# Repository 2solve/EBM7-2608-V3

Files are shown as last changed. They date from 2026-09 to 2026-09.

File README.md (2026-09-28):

# IC2S EBM7-2608 V2.3 — variante fixa 4-20 mA

Placa de extensão da família IC2S (Extension Board Model 7) com **quatro entradas 4-20 mA**, **uma entrada de célula de
carga** e **um NTC de junta fria**, medidos por um ADC sigma-delta de 24 bits (**AD7124-8**). Encaixa por baixo na base board:
**P1** é o barramento (alimentação 24 V e 5 V, SPI do processador) e **P2** leva os sinais de campo.

Esta é a variante **fixa**: as quatro entradas são só 4-20 mA. A variante com selecção 0-10 V / 4-20 mA por MOSFET vive noutro
projecto (`EBM7-2608-V23_configuravel`).

Projecto KiCad 10 (testado em 10.0.5). Abrir
`Desenvolvimento_IC2S-EBM7-2608-V2.3-Fixo420/Projeto_IC2S-EBM7-2608-V2.3-Fixo420/IC2S-EBM7-2608-V2.3-Fixo420.kicad_pro`.

Identificador desta versão: **`IC2S-EBM7-2608-V2.3-Fixo420`** (produto IC2S-EBM7-2608, versão 2.3, variante fixa 4-20 mA).

---

## Estado (28-09-2026)

| Verificação | Resultado |
|---|---|
| DRC (`kicad-cli pcb drc --severity-all --schematic-parity`) | **0 erros**, 62 avisos (todos de serigrafia) |
| Ligações por fazer | 0 |
| Paridade esquemático ↔ PCB | 0 |
| ERC | 0 erros |

Não está pronta para fabricar: ver [Pendentes](#pendentes).

---

## Estrutura do repositório

Segue o padrão de pastas dos produtos da 2Solve (o mesmo de `Produtos/Axcel_Sensor`): uma pasta por versão, e dentro dela
projecto, documentos e ficheiros de fabricação, sempre com o identificador no nome.

```
Desenvolvimento_IC2S-EBM7-2608-V2.3-Fixo420/
├── Projeto_IC2S-EBM7-2608-V2.3-Fixo420/
│   ├── IC2S-EBM7-2608-V2.3-Fixo420.kicad_pro / .kicad_sch / .kicad_pcb / .kicad_dru
│   ├── 01_conectores … 08_ntc.kicad_sch          (as oito folhas)
│   ├── footprints/EBM7_V23.pretty, symbols/       (bibliotecas locais, por ${KIPRJMOD})
│   ├── Documentos_de_Referência-IC2S-EBM7-2608-V2.3-Fixo420/   (datasheets das peças desta placa)
│   └── Outputs/drc_report.json
├── Documentos_IC2S-EBM7-2608-V2.3-Fixo420/
│   ├── 00-Especificações_Técnicas_…/   verificações, relatórios, perguntas ao firmware
│   ├── 01-Esquemáticos_…/              Schematic-….pdf, ….step, …-Top_View.pdf, …-Bottom_View.pdf
│   ├── 02-Pinout_…/                    (vazio)
│   └── 03-Diagrama_Blocos_…/           (vazio)
└── Arquivos_Fabricação_IC2S-EBM7-2608-V2.3-Fixo420/
    ├── 00-Gerbers_…/                   ….GTL .G1 .G2 .GBL .GTS .GBS .GTO .GBO .Outline, ….TXT (furação), .gbrjob, .zip
    ├── 01-BOM_List_…/                  …-Preliminar.xlsx
    ├── 02-Pick-and-Place_…/            …-Pick-and-Place-Preliminar.csv
    └── 03-Stencil_…/                   ….GTP (pasta topo), ….GBP (pasta base)
```

Os ficheiros de fabricação e as vistas foram **gerados pelo `kicad-cli` a partir do projecto** a 28-09-2026 e são
**preliminares**: a placa ainda não passou a revisão independente do roteamento. Não enviar a fabricar sem essa revisão.

Os documentos em `00-Especificações_Técnicas` são registos da data em que foram escritos e citam os nomes antigos dos
ficheiros (`IC2S_Extension_Board_Model_7-EBM7-2608_V23L_Load_Cell_4AI.*`), anteriores à arrumação de 25-09-2026.

**Onde está cada decisão:** cada folha do esquemático tem um bloco de texto «DECISOES DESTA FOLHA» com notas numeradas. Neste
README cita-se sempre como *folha N, nota M*. A nota é a fonte; este documento resume.

---

## Como funciona, bloco a bloco

### Folha 1 — Conectores

- **P1** (Harwin M20-7822046, fila única de 20) liga à base board. Traz +24 V (P1.20), a massa GND_ADC (P1.19), +5 V, DGND e
  o SPI. Os pinos que esta placa não usa (USB, CS_DAC, I²C…) terminam aqui por desenho da família (nota 1).
- P1.20 leva ~116 mA em regime e ~180 mA em falha, 6 % do que o contacto aguenta (nota 2).
- **P2** (M20-7821446) é o conector de campo: excitação e sinais da célula, e os quatro laços (nota 5). Pinos 6-13 em pares
  `+24V_AINn` / `AINn`.

### Folha 2 — Entrada de 24 V e protecção

Caminho: P1.20 → TVS **D1** → fusível **F1** → díodo **D2** → **+24V_ADC**, que alimenta tudo: o conversor U1 e os laços.

- **F1 = Eaton CC12H750MA (time-lag)**: o I²t de fusão (150 mA²s) fica ~29× acima do arranque dos ~30 µF a jusante. O fusível anterior (FF,
  1,5 mA²s) abria no próprio arranque dos condensadores — um dos mecanismos da avaria em campo da V2.2 (notas 1, 2 e 10).
- **D1 = SMA6J33A-Q** (TVS de entrada): standoff 33 V, **clamp real 53,3 V** a 11,3 A — não os 40,6 V que dizia a biblioteca
  (nota 3).
- **C1 = 10 µF / 100 V em 1210**, condensador de entrada do U1: o datasheet da Recom (R-78HB-0.5, p.4) pede 3,3 µF / 100 V
  quando Vin pode passar de 50 V, e o clamp do TVS é 53,3 V (notas 4, 12 e 13).
- **Ramo único de 24 V** (28-09-2026, nota 13): F2, D3 e C2 saíram; o +24V_REG passou a ser o próprio +24V_ADC. Com
  116 mA em regime e ~180 mA em falha, F1 (750 mA) e D2 (1 A) chegam. Perde-se a selectividade: um curto no +24V_ADC
  abre F1 e desliga a placa inteira.
- **Condensadores** (nota 14): 100 nF de 50 V (TDK C1608X7R1H104K080AA) em todo o lado menos no C36, que está no
  +24V_ADC e fica a 100 V; 1 µF com um só MPN (TDK C1608X7R1H105K080AB).
- **Massas:** desde 24-09-2026 **GND_24V e GND_ADC são a mesma rede**. O net-tie que as unia (R1/R200) saiu (nota 7). Motivo:
  as duas são o mesmo domínio a montante; quem isola a lógica do processador é a MainBoard (conversor SCW12B-05), não esta placa.

### Folha 3 — Alimentação

Cadeia analógica: +24V_ADC → **U1** (Recom R-78HB5.0-0.5L, conversor 24→5 V) → FB1 → **+5V_ADC** → **U3** (SPX3819) → **+3.3V_ANA**.
A alimentação do lado do PLC (U2) está desenhada na folha 4, junto ao isolador que alimenta.

- O GND do U1 é GND_ADC: o +5V_ADC é a referência ratiométrica da célula (nota 2).
- O U1 não aceita ligação a quente (hot-plug) — aviso para o manual (nota 3).
- **Pré-carga do U1** (nota 13 e adenda de 15-09): o R-78HB só tem exactidão e regulação especificadas acima de ~10 % de carga;
  a placa sozinha fica em 1,6-6,8 %. Há posições para duas resistências de 220 R (0 / 22,7 / 45,5 mA); **a decisão faz-se na
  bancada**.
- **U4 = TL431B** grampeia o +3.3V_ANA a ~3,6 V (divisor 4k42 / 10k). É o sítio para onde os díodos de protecção das entradas
  despejam a corrente de um surto; sem ele o SPX3819, que só fornece corrente, deixava o rail subir até ~10 V e levava o ADC
  e a referência. Corrente real estimada 12-23 mA, contra 100 mA recomendados (nota 14, em que o componente aparece como U14).

### Folha 4 — Barreira digital

- **Alimentação do lado PLC:** +5 V do P1 → **U2** (SPX3819, o mesmo MPN do U3, desde 28-09; era MCP1824) → **+3.3V** (massa DGND), com C6/C8/C9 e os pontos de teste
  T3 (DGND) e T5 (+3.3V). Alimenta o lado 1 do isolador. Passou da folha 3 para esta em 25-09-2026, só no desenho
  (as ligações não mudaram); as notas que falam dela continuam na folha 3.
- **U5 = ISO7141** passa o SPI entre o lado do PLC (DGND) e o lado analógico (GND_ADC): 3 canais de ida (MOSI, CLK, CS) e 1 de
  volta (MISO), sempre habilitado (notas 3 e 4).
- **Não é isolamento de segurança nesta placa** (nota 1): os 2500 Vrms do ISO7141 exigiriam 3,7 mm de distância cobre-a-cobre e
  o PCB tem ~1 mm. Faz **separação de ruído** entre a lógica e a medida. Para um dia declarar isolamento: ≥ 3,7 mm ao longo da
  barreira (nota 5).
- **No PCB a barreira é física:** DGND e GND_ADC são zonas separadas nas camadas internas e em baixo. O `.kicad_dru` exige
  **1,0 mm** entre as redes do lado PLC (classe `DIGSIDE`) e o resto; há rule areas sem cobre debaixo do ISO7141
  (`keepout_barreira_ISO7141`) e junto ao P1 (`keepout_barreira_P1`, reposto a 25-09).
- Firmware: no arranque, reset do porto série do ADC (64 SCLK com DIN = 1), porque o CS pode oscilar na rampa de alimentação.

### Folha 5 — ADC

- **U6 = AD7124-8**, alimentado por +3.3V_ANA (AVDD, por um filtro passante NFM) e +3.3V_IOVDD (nota 4).
- **Referência dos laços: U7 = ADR4525 (2,5 V) no REFIN2**, por um único 0 Ω. Na V2.2 três 0 Ω punham 5 V nesse pino, acima do
  máximo absoluto de 3,6 V, em todas as placas (nota 1).
- **Célula ratiométrica no REFIN1** = metade da tensão de excitação (nota 2; folha 7, nota 10).
- SYNC com pull-up de 10k (o ADC não tem pull-up interno e com SYNC em baixo fica em reset) (nota 5).
- **Mapa de canais nesta placa:** AIN1 ← AIN4_ADC, AIN2 ← AIN3_ADC, AIN3 ← AIN2_ADC, AIN4 ← AIN1_ADC, AIN5/AIN6 = célula +/−,
  AIN8/AIN9 = NTC. O cruzamento dos laços é herdado da V2.2 e foi mantido para não trocar canais no firmware (folha 6, nota 4).
- Firmware (notas 8 e 9): REF_EN = 1; buffers de entrada ligados; REF_BUFP = REF_BUFM = 0 nos setups com REFIN2.
  As perguntas abertas ao firmware estão em `perguntas_firmware_EBM7_V23L_2026-09-24.md`.

### Folha 6 — Laços 4-20 mA (×4)

Cada canal tem **dois caminhos** no P2, em pares de pinos:

- **Alimentação do sensor** (pino par, `+24V_AINn`): +24V_ADC → fusível **F3-F6** → borne, com o TVS **SMBJ36A** junto ao
  conector.
- **Sinal** (pino ímpar, `AINn`): borne → TVS **824500301** → protector **TPS26613** (U8-U11) → **burden 110 Ω 0,1 %** →
  ferrite → RC anti-aliasing → clamps **BAV199** para +3.3V_ANA → ADC.

- **Burden 110 Ω** (decisão de 21-09-2026, na caixa de texto da folha): 2,20 V a 20 mA, fim de escala do ADC (2,5 V) a 22,7 mA.
  Cumpre a nota (2) da Tabela 8-2 do TPS26613 (SLVSFE3C p.20): 4,46 V > 2,20 V. Os 409 Ω da V2.2 davam 8,18 V e violavam-na.
  **A constante do firmware muda de 6,25 para 9,09 mA/V.** MPN: Susumu RG1608P-111-B-T5.
- **TPS26613** limita a corrente a ~32 mA e desliga em sobretensão; aguenta um curto no cabo de campo (nota 8).
  O seu +Vs vem de **U12 = TPS7A4001** a 12 V, e não dos 24 V: o máximo de +Vs é 32 V e o TVS de entrada grampeia a 53,3 V
  (notas 9 e 16). Um só divisor VSNS para os quatro (nota 11).
- **F3-F6 = Schurter 3413.0006.22 (125 mA)** desde 25-09-2026 (nota 1). É **mitigação, não correcção**: aguenta o arranque de um
  sensor a 3 fios e surtos moderados, mas um surto forte ainda o abre. A correcção completa (díodo em série entre o fusível e o
  TVS) está só na variante configurável.
- **BAV199** em vez de BAT54S: fuga 5 nA em vez de 2 µA (nota 15).
- **U12 (TPS7A4001):** footprint corrigido a 25-09 para o land pattern da TI (SBVS162B p.22); os pads NC 3/6/7 ficam a 0,20 mm,
  com excepção própria no `.kicad_dru`. O condensador de entrada **C34 passou a 10 µF / 100 V em 1210**
  (GRM32EC72A106ME05L): o datasheet pede > 1 µF efectivo junto ao pino, e a 32 V um 0805 de 100 V dá ~0,64 µF.

### Folha 7 — Célula de carga

- **H1 (jumper 2×3)** escolhe a tensão de excitação: 1-2 = 2,5 V (U13, LDO), **3-4 = 5 V (omissão)**, 5-6 = 3,3 V (nota 15).
- Caminho: H1 → **D23** (Schottky RB162MM-60) → **R30 68 Ω 1 W** → P2.2 → ponte. O D23 impede que o clamp do campo volte
  para os rails; queda típica ~0,27 V a 11 mA e 25 °C (curva VF-IF do datasheet ROHM). O R30 passou a 1 W porque um curto de
  campo a 5 V dissipa 0,33 W (nota 16).
- TVS no campo (D8/D9 e D10), resistências de entrada 1k3 0,1 % e clamps BAV199 (notas 3, 4 e 12).
- **Medida ratiométrica:** REFIN1 = excitação/2 por um divisor 10k/10k casado; com REF_BUFP = 1 **sempre** (nota 10).
- Células aceites: 1-3 mV/V, 120-1000 Ω (nota 5).

### Folha 8 — NTC

- **Função:** compensação de **junta fria** para termopar; nunca usado em campo até hoje (nota 1).
- Divisor excitado pelo REFOUT do ADC, leitura diferencial em AIN8/AIN9 (notas 2 a 4). Com R21 = 22k a leitura fica dentro da
  gama dos buffers em −40…+85 °C (nota 7).

---

## Placa (PCB)

- 60 × 60 mm, 4 camadas. **F.Cu** sinal · **In1.Cu** e **In2.Cu** planos de massa partidos (DGND | GND_ADC), sem pistas ·
  **B.Cu** sinal e enchimento de massa.
- P1 e P2 montam em baixo (encaixe na base board).
- Classes de rede no `.kicad_pro`: Default, Analog, Digital, Loop, Power5, Power12, Power24 e `DIGSIDE` (auxiliar, só para a
  regra da barreira).

---

## Alterações de 24-28/09/2026

| Data | O quê | Porquê |
|---|---|---|
| 24-09 | GND_24V fundido em GND_ADC; R1 removido; D1 retorna a GND_ADC por via própria | mesmo domínio a montante |
| 25-09 | F3-F6 de 50 mA para 125 mA (3413.0006.22) | mitigar a abertura em surtos moderados e no arranque de sensores |
| 25-09 | Footprint do U12 (TPS7A4001) conforme SBVS162B p.22; regra dos pads NC | DRC limpo sem mentir sobre o land pattern |
| 25-09 | MPN dos burdens 110 Ω: RG1608P-111-B-T5 | faltava MPN |
| 25-09 | C34 → 10 µF / 100 V 1210 | CIN efectivo do TPS7A4001 |
| 25-09 | `keepout_barreira_P1` reposto | tinha desaparecido da placa |
| 25-09 | U2 (MCP1824) e C6/C8/C9/T3/T5 desenhados na folha 4 em vez da 3 | agrupar o lado PLC junto ao isolador; netlist igual |
| 28-09 | **Ramo único de 24 V**: saem F2, D3 e C2; F1 + D2 alimentam o U1 e o +24V_ADC; +24V_REG deixa de existir | reunião: é tudo alimentado pelos mesmos 24 V, não eram canais independentes nem isolados; ganha-se espaço |
| 28-09 | 100 nF fora do 24 V → TDK C1608X7R1H104K080AA (50 V), 24 peças; o C36 (+24V_ADC) fica GRM188R72A104KA35D (100 V) | 100 V estava sobredimensionado; pior caso fora do 24 V é o +12V_TPS a 31,7 V, por isso 50 V e não 25 V |
| 28-09 | 1 µF → TDK C1608X7R1H105K080AB (50 V) nos quatro | havia dois MPN para a mesma função |
| 28-09 | U2 MCP1824ST (SOT-223) → SPX3819 (SOT-23-5); **faltam rotear 6 ligações do U2** | mesmo MPN do U3; peça menor e mais barata (`alteracao_LDO_3V3_lado_PLC_2026-09-28.md`) |

---

## Notas do esquemático desactualizadas

Algumas notas foram escritas para outra revisão ou para a variante configurável e **não descrevem esta placa**. Até serem
corrigidas, vale o circuito:

- **Folha 5, nota 10** e **folha 6, notas 12-14** («MODO DUPLO», MOSFETs Q1-Q4, divisor 40k2/10k, 0-10 V): esta placa **não
  tem MOSFETs** nem selecção de modo. O mapa de canais correcto está na folha 5 acima.
- **Folha 6, caixa «DECISAO 21-09»**: fala em R10/R11/R12/R16 e R13/R14/R15/R17 — é a que vale para esta placa.
- **Referências de outras versões:** as notas dizem U3 = K78U05 (hoje **U1 = R-78HB5.0**), U14 = TL431 (hoje **U4**),
  U15 = TPS7A4001 (hoje **U12**), D200 = TVS de entrada (hoje **D1**), D31 = Schottky da excitação (hoje **D23**).
- **Folha 7, nota 11**: diz TPS7A2025 para o U13; a peça montada é o **LP5907MFX-2.5**.

---

## Documentos

Estão em `Desenvolvimento_…/Documentos_…/00-Especificações_Técnicas_IC2S-EBM7-2608-V2.3-Fixo420/`.

| Ficheiro | Conteúdo |
|---|---|
| `alteracoes_reuniao_2026-09-28.md` | revisão da reunião de 28-09: ramo único de 24 V, entrada do R-78HB, tensão dos 100 nF, MPN do 1 µF |
| `verificacao_aplicacao_TPS26613_V23L.md` | fórmulas e notas do datasheet do TPS26613 com os valores da BOM |
| `verificacao_aplicacao_AD7124_V23L_2026-09-24.md` | idem para o AD7124-8 (47 linhas avaliadas) |
| `verificacao_aplicacao_D14_pistas_V23L.md` | pistas debaixo do clamp D14 |
| `relatorio_roteamento_EBM7_V23L_2026-09-22.md` | revisão do roteamento a 22-09 |
| `relatorio_emc_EBM7_V23L_2026-09-23.md` | pré-conformidade EMC (CISPR 32 classe A) |
| `comparacao_BOM_V22_V23L_2026-09-23.md` | o que mudou na BOM desde a V2.2 fabricada |
| `perguntas_firmware_EBM7_V23L_2026-09-24.md` | perguntas abertas à equipa de firmware |
| `PROMPT_revisao_independente_V23L.md` | prompt para uma revisão independente em sessão nova |

---

## Pendentes

- **Rotear as ligações do U2 (SPX3819) e do C49 (2,2 µF na saída do U2)**, 28-09, e depois regenerar Gerbers, BOM, pick-and-place e stencil: os de 28-09 ainda mostram o MCP1824.
- Serigrafia: 62 avisos, legendas do H1, texto «5V» fora do contorno.
- Reescrever e assinar o requisito RF5 do escopo com a barreira real (DGND ↔ GND_ADC).
- Corrigir as notas desactualizadas listadas acima.
- Decidir a pré-carga do U1 na bancada.
- BOM final: a `…-Preliminar.xlsx` tem 55 linhas, 134 peças, 1 DNP (R8) e 133 a montar.
- Pick-and-place: o CSV tem 144 linhas, mais 11 do que as peças a montar — os 8 pontos de teste (T1-T8, `TestPad_Via`) e os
  3 fiduciais. Marcar esses footprints como «excluir dos ficheiros de posição» na placa antes de enviar à montadora.
- Datasheets que faltam em `Documentos_de_Referência`: SMBJ36A-13-F (Diodes), MBR1H100SFT3G (onsemi), BLM18PG471SN1D
  (Murata), LED KG EELP41.22 e as resistências genéricas (Yageo RC0603, Panasonic ERJ).
- Verificação do roteamento (`2shw-pcb:check-roteamento`) em **sessão independente**, antes de fabricar.
- O mecanismo da avaria em campo da V2.2 (família 2) **não foi medido** (medição G8 com osciloscópio). As protecções desta
  versão são correctas por si, mas não há prova de que resolvem essa avaria.

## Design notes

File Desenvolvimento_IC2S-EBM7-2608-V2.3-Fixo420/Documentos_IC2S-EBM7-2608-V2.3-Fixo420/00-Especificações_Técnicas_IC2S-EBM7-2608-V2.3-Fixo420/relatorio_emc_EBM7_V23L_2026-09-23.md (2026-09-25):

# Revisão EMC de pré-conformidade — EBM7 V2.3 legacy (V23L)

**Placa:** `IC2S_Extension_Board_Model_7-EBM7-2608_V23L_Load_Cell_4AI.kicad_pcb`, gravada em 2026-09-23 10:16:16.
**Ferramenta:** skill `kicad-happy:emc` 2.2.0 — `analyze_schematic.py` → `analyze_pcb.py --full` → `analyze_emc.py --standard cispr-class-a --spice-enhanced` (ngspice), corrida `2026-09-23_1028`.
**Norma alvo:** CISPR 32 / EN 55032 classe A (ambiente industrial). O analisador é de *risco*, não prevê conformidade: só o ensaio em laboratório acreditado o faz.
**Método:** cada achado do analisador foi **re-medido** na geometria real da PCB com `pcbnew` (polígonos preenchidos das zonas, vias, pads), porque o analisador não conhece as três referências de terra desta placa. Cada linha diz de onde vem a conclusão: **A** datasheet, **B** física/medida, **C** regra do projecto, **D** critério próprio.

## 1. Resultado bruto do analisador

| | |
|---|---|
| Pontuação de risco | 0 / 100 |
| Achados | 38 — 10 error, 24 warning, 4 info |
| Categorias | plano de terra, desacoplo, I/O, relógio, stackup, emissão, retorno, PDN |

A pontuação **não tem significado** aqui: dos 10 *errors*, 3 (SU-001) e 2 (PD-001) são falsos positivos do analisador e 1 (GP-005) é a arquitectura pretendida (ver §2). Descontados, o risco real é **baixo-médio**, concentrado em vias de retorno.

## 2. Achados verificados um a um

| Regra | Analisador | Verificação na geometria | Veredito | Fonte |
|---|---|---|---|---|
| SU-001 ×3 | «camadas de sinal adjacentes F/In1, In1/In2, In2/B» | In1 e In2 são **planos de terra**: GND_ADC 2 715 mm² + DGND 338 mm² + GND_24V 125 mm² = **87 % da placa** em cada camada interna; B.Cu 82 %. O analisador não reconhece planos formados por várias zonas. | **falso positivo** | B |
| PD-001 +5V_REG | anti-ressonância 398 MHz, alvo 0,028 Ω «Vout = 0,5 V, 0,9 A» | O «0,5» é o sufixo do MPN R-78HB5.0-**0.5**L, não a tensão; a carga de 0,9 A é inventada (a placa consome < 0,2 A). Sem cargas digitais rápidas não há corrente a 400 MHz para excitar o pico. | **falso positivo** | B |
| PD-001 +12V_TPS | anti-ressonância 501 MHz, «Vout = 6,186 V» | Vout real = VREF × (1 + R25/R26) = 1,173 × (1 + 93,1 k/10 k) = **12,09 V** (VREF 1,173 V típ., TI TPS7A4001 p.5). Rail correcto; o pico a 500 MHz é irrelevante para um LDO que alimenta ±Vs dos TPS26613. | **falso positivo** (mas confirma o divisor) | A/B |
| GP-005 | «3 domínios de terra» | DGND (PLC) ↔ GND_ADC isolados pelo ISO7141 (U5); GND_24V ↔ GND_ADC unidos por **R1 0 R**; GND_24V e DGND chegam ambos de P1 (pinos 19 e 3/12/16). É a arquitectura pretendida; barreira medida 1,20 mm (relatório de roteamento). | **intencional** | C/B |
| GP-001 CS_ADC 57 % | «vão no plano de referência» | O analisador só conta GND_ADC. Sobre **DGND** a cobertura real é **68 %**; o troço sem plano é B.Cu (121,2; 100,5)–(120,5; 101,2) a entrar no pad 9 de P1: são os furos do conector. | real, irrelevante (sinal lento, 0,7 mm) | B |
| GP-001 CLK/MISO/MOSI 92–93 % | idem | Cobertura real sobre DGND 92–93 %; os troços a 24–48 % são os últimos 1,3–2 mm até aos pads de P1. Inevitável num conector THT. | real, irrelevante | B |
| GP-001 EXC_SEL 71 % | idem | Real **58 %**: a pista F.Cu (150,0–154,6; 78,4) corre **em cima da fila de pads de H1**, cujos furos abrem In1. EXC_SEL é DC (selector de excitação). | real, irrelevante | B |
| GP-001 MISO_ADC_ISO 75 % | idem | Real **86 %**; vão em (136,0; 98,6)–(136,4) F.Cu e B.Cu (136,0; 98,6–101,2) — é a zona de vias/pads junto a U5 e C13. Sinal SPI isolado com flancos rápidos: ver RP-001. | real, menor | B |
| GP-001 Temp2_AIN9 78 % | idem | Real 76 %; troços F.Cu (150,1–152,3; 82,0) e (150,1; 86,2–87,2) passam sobre os furos de H1 e vias. Entrada analógica lenta filtrada. | real, menor | B |
| GP-001 AIN1–4, Load_Cell±, REFIN1+, VSNS 80–94 % | idem | Reais 87–94 %; os vãos são todos os últimos mm até aos pads de P2 (x = 176,5) ou de fusíveis. | real, irrelevante | B |
| RP-001 MISO_ADC_ISO | «2 transições sem via GND a 1 mm» | Vias (136,0; 98,6) e (136,0; 101,2): GND mais próxima a **2,61 / 3,15 mm**. | **confirmado** — corrigir | B |
| RP-001 Temp2_AIN9, REFIN1+ | idem | (150,1; 86,2) → GND a **5,12 mm**; (152,7; 84,9) → **4,87 mm**; (152,3; 82,0) → 2,78; (164,8; 82,8) → 1,87. | confirmado, prioridade menor (sinais lentos, REFIN1+ é referência do ADC) | B |
| RP-001 VSNS | 4 transições | GND a 2,56–3,27 mm. VSNS é tensão de sentido DC dos TPS26613. | confirmado, irrelevante | B |
| RP-001 CS_ADC | 1 transição | (125,8; 100,5) → DGND a 3,62 mm. | confirmado, menor | B |
| DC-003 C17 | «4,9 mm da via» | **C17 = desacoplo IOVDD do AD7124 (U6.2)**: pad GND a **4,73 mm** da via GND mais próxima; pad +3.3V_IOVDD a 7,38 mm. O AD7124 pede o 0,1 µF «right up against the device» com retorno curto (Rev F p.73). | **confirmado** — corrigir | A/B |
| DC-003 C37, C38 | 4,6 / 4,2 mm | C37.2 GND → via a **6,03 mm**; C38.2 GND → **6,89 mm**; C38.1 +12V_TPS → 11,8 mm. São o condensador de VSNS e o de entrada do U12. | confirmado, menor (redes DC) | B |
| DC-003 C35 | 3,7 mm | Condensador de saída do Recom. | confirmado, menor | B |
| CK-001 CLK, CLK_ADC_ISO | «relógio em camada exterior» | Placa de 4 camadas com plano adjacente a 0,21 mm: microstrip sobre plano é a topologia normal; não há camada interna livre para stripline. | sem acção | B/D |
| IO-001 P1 | «sem filtragem» | P1 é o conector de encaixe na base do PLC (SPI, I²C, 24 V). Os sinais de campo entram por **P2** (lazos 4–20 mA, célula). | sem acção em P1; ver §4 | C |
| IO-002 P2 | «2 pinos GND para 12 sinais» | P2: GND_ADC nos pinos 5 e 14; sinais de campo DC de baixa frequência. | sem acção | B |
| EE-001 | ressonâncias de cavidade 1,18 / 1,67 / 2,36 GHz | Informativo; a placa não tem fontes nessa banda. | informativo | B |

## 3. O que corrigir (por ordem de valor/custo)

1. **Via GND junto a C17.1** (146,40; 95,90) — retorno do desacoplo IOVDD do ADC passa de 4,7 mm a < 1 mm. Uma via 0,6/0,3.
2. **Vias GND de costura junto às vias de MISO_ADC_ISO** (136,0; 98,6) e (136,0; 101,2), do lado GND_ADC da barreira (x ≥ 134,2 para manter a distância ao DGND). São os flancos mais rápidos da placa (saídas do ISO7141).
3. **Via GND junto a C37.2 e C38.2** (147,9; 107,65) e (148,3; 104,75) — desacoplos DC, custo zero.
4. Vias GND junto às vias de sinal de Temp2_AIN9 (150,1; 86,2) e REFIN1+ (152,7; 84,9).
5. Opcional, do relatório anterior: cobre de 5 × 5 mm no cátodo dos TVS D9/D10/D12/D13 com 3 vias (condição da nota 2 do SMBJ36A para o rating de 600 W; baixa a indutância do clamp em ESD).

Nenhuma destas acções move componentes nem toca a barreira. Podem ser aplicadas por script com verificação de clearance, refill e DRC, com o KiCad fechado.

## 4. O que nenhuma ferramenta viu

- **Imunidade** (IEC 61000-4-2/-4/-5/-6 nas entradas de campo por P2) só se verifica em laboratório. A protecção existe (fusível → TVS SMBJ36A → TPS26613 → burden → filtro RC do ADC); o analisador não avalia o caminho nem a tensão de clamp.
- **Emissão conduzida/radiada**: as únicas fontes são o Recom R-78HB (frequência de comutação não consta do PDF Rev 5-2019), o relógio interno do AD7124 (614 kHz) e os flancos do SPI através do ISO7141. Espera-se emissão baixa; a banda a vigiar num pré-ensaio é 30–300 MHz junto a U5 e U1.
- **Cablagem**: a placa liga à base do PLC; o comportamento em cabo depende do conjunto, não desta PCB.

## 5. Limites desta revisão

- Mesma sessão que fez o roteamento e as cirurgias (não é revisão independente).
- O analisador falhou em três pontos que ficam registados para a skill: não reconhece planos de terra formados por várias zonas (SU-001); lê a tensão de saída do MPN do Recom (PD-001); estima 6,19 V para um LDO que dá 12,09 V (PD-001); e o modo `--text` rebenta em cp1252 (corrido com `PYTHONIOENCODING=utf-8`).
- Sem pasta `datasheets/` do projecto (DS-002): as afirmações com datasheet acima vêm dos PDFs em `Documentos_de_Referência` lidos nesta sessão (TPS7A4001 p.5; AD7124-8 Rev F p.73; TPS2661x SLVSFE3C p.36; Würth 824520361 p.1).
- Ficheiros: `emc_analysis/2026-09-23_1028/{schematic,pcb,emc}.json` e `emc_text.txt` na pasta temporária da sessão; medições em `cobertura_gp.py`.

## Adenda 11:05 — plugin actualizado para 2.2.1 e nova corrida

**Plugin:** kicad-happy 2.2.0 (43dad23, 31-08) → **2.2.1** (a6bba1a, `main` de 13-09, que já inclui o lote «v2.3 correctness» por cima da
release 2.2.1 de 01-09). `claude plugin marketplace update kicad-happy` + `claude plugin update kicad-happy@kicad-happy`; scripts corridos
directamente da cache 2.2.1 (o reinício só afecta a skill carregada).

**Placa:** entretanto gravada às **11:03:49** pelo projectista: C17 movido de (146,4; 96,6) para (144,43; 98,6), 36 troços GND_ADC/rede 11
refeitos junto a C17, C37 e D-lado direito. DRC 96 (−2 de serigrafia), 0 por ligar, paridade 0; o toco de 0,25 mm em (160,45; 83,20) continua.

**Achados 2.2.0 (placa 10:16) → 2.2.1 (placa 11:03): 36 → 28, pontuação 0 → 26,5.**

| Mudou | Porquê |
|---|---|
| GP-001 desapareceu em MISO_ADC_ISO, Temp2_AIN9, AIN6, REFIN1+, VSNS | correcção #39 da 2.2.1: o antipad da própria via já não conta como vão do plano — confirma a leitura que eu tinha feito à mão |
| GP-001 CS_ADC error → warning | idem (agora 86 %) |
| DC-003 C17, C37, C35 desapareceram | C17 movido pelo projectista (GND a 1,02 mm); C37.2 agora com via GND a 1,78 mm pelo reroteamento; C35 (3,63 mm) já não passa o limiar |
| PD-001 +5V_REG e +12V_TPS error → **info** «peaks above relevant band» | a 2.2.1 desconta picos fora da banda útil; mas continua a ler Vout = 0,5 V do MPN e 6,186 V para o TPS7A4001 (real 12,09 V) |
| **novo** DC-001 U1 | condensador mais perto do Recom a 5,5 mm (C1); é a «caixa 3» do relatório de roteamento |
| Mantêm-se | SU-001 ×3 (falso positivo, planos multi-zona), GP-005 (intencional), GP-001 nas redes dos conectores THT, RP-001 nas 6 redes, CK-001, IO-001/002, EE-001 |

**Correcção a este relatório (§2, linha DC-003 C17).** C17 (10 µF) **não** é o desacoplo junto ao ADC: a alimentação IOVDD segue
+3.3V_IOVDD → C17 → **C16 (NFM18PC104R1C3D, filtro passante 100 nF)** → Net-(C16-IN) → U6.2, com C16 a 2,76 mm do pino. O elemento «right up
against the device» (AD7124-8 Rev F p.73) é o C16, e o seu ponto fraco é o retorno: os pads GND de C16 têm a via mais próxima a **2,2–3,4 mm**,
enquanto o filtro gémeo do AVDD (C15) tem via a 0,9–1,6 mm. O movimento de C17 melhorou o retorno do 10 µF (1,0 mm) mas deixou o seu pad
+3.3V_IOVDD a 5,5 mm da via de alimentação — irrelevante para um bulk atrás do filtro.

**Lista de acções revista (custo ≈ uma via cada):**
1. Via GND encostada ao pad 2 de **C16** (p. ex. (145,7; 95,9) ou (143,2; 95,9)) — retorno do filtro IOVDD do ADC de 2,2–3,4 mm para < 1 mm.
2. Vias GND de costura junto às vias de MISO_ADC_ISO (136,0; 98,6) e (136,0; 101,2), do lado GND_ADC (x ≥ 134,2).
3. Via GND junto a C38.2 (4,0 mm) e C35.2 (3,6 mm).
4. Vias GND junto às vias de Temp2_AIN9 (150,1; 86,2) e REFIN1+ (152,7; 84,9).
5. Apagar o toco (160,45; 83,20)–(160,45; 82,95).

Ficheiros: `emc_221/2026-09-23_1105/{schematic,pcb,emc}.json`, `emc_text_221.txt`, `legacy_drc_1103.json` (pasta temporária da sessão).

## Correcção 11:30 — a acção 1 (via GND em C16) é retirada

Javier apontou que o footprint `EBM7_V23:NFM0603` já traz os furos de GND. Confirmado no ficheiro da lib e na PCB: o pad 2 (terminal GND do
NFM18PC104) é composto por três peças SMD de 0,4 × 0,6 mm em F.Cu com pasta, uma faixa de 0,4 × 1,8 mm em B.Cu e **três pads thru-hole de
0,2 mm** (em y = −0,7; 0; +0,7, camadas `*.Cu`), com anel de 0,10 mm. O `pcbnew` confirma que o fill GND_ADC de **In1, In2 e B.Cu toca os
três furos** em C16 e em C15: a distância do terminal GND ao plano é zero, não 2,2–3,4 mm. O meu inventário só lista objectos `(via …)` e
ignorou pads PTH — erro de medida meu, registado como lição. A linha DC-003 C17 do §2 e a acção 1 da adenda das 11:05 ficam sem efeito;
a lista passa a começar nas vias de costura do MISO_ADC_ISO.

**O footprint está bem criado?** Electricamente sim, e é deliberado (descrição da lib: «vias do pad 2: furo 0,3 → 0,2 mm, anel 0,05 → 0,10;
a V2.2 fabricada já tinha furos de 0,2»). Contra o land pattern de referência da Murata (NFM18PC104R1C3-0-770-EN p.6, Fig. 3: a 1,0; b 2,2;
c 0,6; d 1,2; e 0,4; f 0,4):

| Item | Murata p.6 | Footprint | Nota |
|---|---|---|---|
| Lands de topo (In/Out) | largura (b−a)/2 = 0,6; extensão exterior 2,2; folga interior 1,0 | 0,6 × 0,6 em x = ±0,8 → 2,2 / 1,0 | igual |
| Lands GND | dois lands 0,4 × 0,4 separados por c = 0,6, extensão d = 1,2 | faixa contínua 0,4 × 1,8 **com pasta ao longo de toda a faixa**, incluindo sob o centro do corpo | difere: cobre e pasta sob o corpo e 0,3 mm para fora de cada lado |
| Furos | não constam (é um substrato de ensaio) | 3 × 0,2 mm, anel 0,10 = `min_via_annular_width` da placa; o do centro fica sob a pasta e sob o corpo | via-em-pad sem tamponar: risco de sucção de solda / vazio; V2.2 foi montada assim |

Recomendação (critério D, não é exigência de datasheet): manter a ligação por furos — é o que dá ao filtro o retorno curto que o AD7124 pede —
mas, numa próxima revisão da lib, retirar a pasta da peça central (y = 0) e do trilho sobre os furos, ou passar os furos para fora do corpo
(y = ±0,9), para o land ficar mais perto da Fig. 3 e sem solda a entrar nos furos. Confirmar com quem montou a V2.2 se houve vazios nesses pads.

## Adenda 12:10 — stencil do NFM18PC (C15/C16 legacy, C29/C31 sem_trilhas) corrigido

**Fonte (A):** Murata NFM18PC104R1C3-0-770 p.16 (aberturas de pasta NFM18PC: GND em dois quadrados 0,4 × 0,4 com vão central 0,4 e
extensão 1,2; sinais 0,6 × 0,6 com 1,0/2,2; espessura 100–150 µm), p.29 (land para refusão: faixa GND 0,4 × 1,5 com três furos
«small diameter thru hole ø0,2–0,3» **sob máscara** — centro e pontas —, janelas expostas só onde há pasta) e p.27 §1-4 (ligar o GND do
chip por via ao plano interno). O fabricante prevê os furos, **nunca dentro da abertura de pasta**.

**O que estava mal:** as peças SMD do GND tinham 0,4 × 0,6 em y = ±0,6 (janela de máscara e pasta 0,3…0,9) e os furos exteriores estavam em
y = ±0,7 — **inteiramente dentro da janela de pasta**: a solda seria sugada pelo furo (vazio no terminal GND, esferas no lado oposto). O furo
central já estava tentado. Na legacy havia ainda uma via 0,6/0,3 livre empilhada sobre o furo exterior de C16 (acrescentada depois das 09:16).

**Correcção aplicada (lib nos dois projectos + 4 instâncias):** janelas GND 0,4 × 0,4 em y = ±0,4 (0,2…0,6, igual à p.16); furos exteriores
em y = ±0,8 com cobre 0,5…1,0 (anel 0,10 na ponta) — dique de máscara de **0,10 mm** entre janela e furo, medido com `pcbnew` nas 4 peças;
furo central inalterado (dique 0,10). Via empilhada removida (redundante com os furos do footprint). Nota: no KiCad o `offset` do furo desloca
o **cobre**, não o furo — a primeira passada deixou o furo em ±0,75 (dique 0,05) e foi refeita.

**DRC:** legacy 96 = 96 antes, 0 por ligar, paridade 0, nenhum item em C15/C16; sem_trilhas 143 = 143 antes (os avisos de courtyard de C31
já existiam). Backups `.antes_nfm_stencil` e `.antes_nfm_stencil2` (PCB e `.kicad_mod`).

**Nota 12:40 (releitura da p.29 ampliada):** a cota 1,5 da Fig. NFM18PC é **entre centros dos furos das pontas** (furos em ±0,75, sob
máscara), não o comprimento da faixa; a faixa de cobre segue até ≈ ±0,88 e o furo central fica sob uma ilha de máscara 0,6 × 0,4. Com ø0,2
em ±0,75 o dique de máscara à janela (0,2…0,6) seria 0,05 mm; o footprint usa furos em ±0,80 e cobre até ±1,0 para um dique de 0,10 mm —
desvio deliberado de 0,05 mm (critério D, registo de máscara). Janelas, pads de sinal e stencil iguais à p.16/p.29. Sem efeito em
diafonia: a faixa GND entre In e Out é a separação prevista do filtro passante; folga cobre GND–sinal 0,3 mm, igual à Murata.

## Correcção 24-09 — procedência da lista de vias (a pedido do Javier: «é o que pede o datasheet?»)

**Nenhum datasheet da pasta pede vias de retorno a uma distância concreta.** O limiar de 1 mm é das regras RP-001 e DC-003 da
ferramenta `kicad-happy:emc` (critério da ferramenta, não do fabricante). O que os datasheets dizem, textual:

- AD7124-8 Rev F p.73 (*Grounding and Layout*): «ensuring that the paths for all return currents are as close as possible to the paths the
  currents took to reach their destinations» — princípio, sem distância; pede também não passar digital sob o ADC, cruzar digital/analógico em
  ângulo recto, alimentação com pistas largas e o 0,1 µF encostado ao chip.
- ISO7141 (SLLSE83F) p.25 (*Layout Guidelines*): «Routing the high-speed traces on the top layer avoids the use of vias … Placing a solid
  ground plane next to the high-speed signal layer … provides an excellent low-inductance path for the return current flow» — a preferência é
  **não ter via** nas linhas rápidas; a via de costura seria paliativo.
- TPS7A4001 (SBVS162B) p.13, §10.1.1: «the ground connection for the output capacitor should connect directly to the GND pin of the device» —
  aplica-se a **C38**; critério diferente de «via a 1 mm», **ainda não medido**.

| Item da lista de 23-09 | Fonte real | Estado |
|---|---|---|
| Vias de costura junto às vias de MISO_ADC_ISO | princípio AD7124 p.73 / ISO7141 p.25; 1 mm é da ferramenta | opcional; SCLK = 1 MHz (Rodrigo, 24-09) → benefício marginal |
| C38 | TPS7A4001 p.13 (GND do C_OUT directo ao pino GND) | único com base em datasheet; medir |
| C35 | nenhuma — e **erro meu**: C35 está no +24V_ADC dos laços, não na saída do Recom | retirado |
| Vias junto a Temp2_AIN9 e REFIN1+ | nenhuma; sinais lentos | retirados |

Nada disto exige nova revisão. Para o roteamento da sem_trilhas valem as regras textuais acima (ISO7141 p.25, AD7124 p.73, TPS7A4001 p.13,
ADR4525 p.35 «reference as close to the load as possible»). O shunt de H1 é só o modelo 3D.

**C38 medido (24-09):** o GND de C38 liga por pista F.Cu de 0,25 mm e 2,66 mm **directamente ao pad térmico (pino 9, GND) do U12**;
o +12V de C38 fica a 2,74 mm do pino OUT. Cumpre TPS7A4001 p.13 («output capacitor … directly to the GND pin»). Melhoria opcional: alargar
essa pista (a mesma secção pede ESL/ESR mínimos). Não há mais nada da lista de vias com base em datasheet.

## ⚠️ Correcção 24-09 — a barreira NÃO mede 1,20 mm

A revisão independente de 24-09 mediu **0,30 mm** cobre-a-cobre entre o domínio PLC e o campo em In1/In2. Re-medido nesta sessão
incluindo os **preenchimentos das zonas** (`barreira_real.py`): F.Cu 1,200 mm; **In1 0,300 mm; In2 0,300 mm; B.Cu 0,400 mm**. O par
crítico é a zona DGND contra a via GND_ADC em (128,20; 116,70) (segunda via de C5.1, presente desde antes da cirurgia de 23-09; C5.1 já
tem via própria em (127,35; 118,70)). Os 1,20 mm que escrevi mediam só pistas e pads, sem zonas — **erro de método meu**. A verificação
«nenhum cobre de campo dentro do contorno DGND» também não apanhou a via, porque ela fica fora do contorno mas a 0,3 mm do seu bordo.

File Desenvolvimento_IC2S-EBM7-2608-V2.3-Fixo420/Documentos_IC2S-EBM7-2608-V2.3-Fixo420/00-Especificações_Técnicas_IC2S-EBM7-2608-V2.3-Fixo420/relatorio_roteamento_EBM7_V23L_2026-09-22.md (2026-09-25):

# Relatório de roteamento — EBM7 V2.3 legacy (4-20 mA), estado de 22-09-2026 17:01

**Ficheiro lido:** `IC2S_Extension_Board_Model_7-EBM7-2608_V23L_Load_Cell_4AI.kicad_pcb`, mtime 2026-09-22 17:01:53
(149 footprints, 655 segmentos, 103 vias, 14 zonas). Revisão **só de leitura**; nada foi alterado na placa.

**Independência (declarada):** esta sessão alterou hoje o H1, os 0R selectores, o R30 e a nota da folha 07.
O roteamento é do projectista. O verificador é o mesmo modelo/sessão: **não** cumpre a regra «sessão limpa,
modelo diferente» da `2shw-pcb:check-roteamento`. Vale como pré-revisão; a revisão de portão deve correr em sessão nova.

**Métodos:** `kicad-cli pcb drc --schematic-parity --severity-all` sobre o ficheiro e sobre uma **cópia com zonas
reenchidas** (mesmos números: o que está por ligar é real, não relleno velho); DRC pelo servidor MCP KiCad
(`run_drc`): 102 violações / 38 por ligar / 1 courtyard — **coincide**; medições de geometria por script sobre o texto
do ficheiro (distâncias pad-condensador, barreira, larguras, rule areas, serigrafia); datasheets da pasta de referência.

## Veredito: **NÃO-LIMPO — 1 bloqueante**, 4 importantes, 7 menores

### BLOQUEANTE

**B1 — Barreira de isolação furada por placement: FB1, C7 e C5 estão do lado PLC.**
A placa separa dois domínios: lado PLC (`DGND`, `+5V`, `+3.3V`, SPI de P1 até U5 pinos 1-8) e lado de campo
(`GND_ADC` e tudo o resto). As zonas `DGND_*` chegam a x = 132,5 mm entre y = 110 e 122; as `GND_ADC_*` começam em
133,0: barreira de 0,5 mm nas zonas. Mas **FB1 (129,9; 119,1), C7 (129,2; 116,2) e C5 (128,2; 118,8)**, todos da rede de
campo `+5V_REG`/`+5V_ADC`, estão colocados dentro dessa região, e a pista `+5V_ADC` que os liga a U3 corre a x 129,9-134.
Resultado medido: **pista `+3.3V` (lado PLC) a 0,300 mm da pista `+5V_ADC` (lado de campo), na mesma camada F.Cu**, em
(130,8-131,8; 115,0-115,7). São três pares a 0,300 e dois a 0,449 mm. O ISO7141 dá 3,7 mm de creepage no encapsulado
(SLLSE83F p.17); 0,3 mm na superfície anula a barreira. **Correcção:** mover FB1, C7 e C5 para x ≥ 134 (junto a U3, que
está em 135,3; 115,45) e rotear `+5V_REG → FB1 → C7 → U3.1` inteiramente do lado de campo; manter U2/C6/C8 e a pista
`+3.3V` à esquerda de x ≈ 131. Depois medir de novo: nenhuma pista/pad dos dois domínios a menos do que as zonas (0,5 mm).

### IMPORTANTE

**I1 — 24 pads de `GND_ADC` sem ligação ao plano** (confirmado com zonas reenchidas): C14, C15.2, C20, C22, C23, U7.4,
R29, R37, C39, C43, C44, C47, D6, D7, D9, D10, D12, D13, D19, D20, D21, D22, D24, D25, U8.1/3, U9.1. Não há pour em F.Cu:
cada um precisa de via para In1/B.Cu ou pista curta até uma via. Prioridade aos desacoplos do U6 (C14, C15, C20) e da
referência (C22, C23, U7.4).

**I2 — Recom U1: condensadores longe dos pinos.** `+5V_REG` pin 3 → C3 22 µF a 11,1 mm, C4 100 nF a 12,3 mm, C5 a 21,6 mm;
`+24V_REG` pin 1 → C1 a 8,4 mm. O datasheet (REV 5/2019 p.6) pede os externos «fitted close to the converter pins».
Aproximar C3/C4 do pino 3 e C1 do pino 1 (o Recom comuta a 120-800 kHz).

**I3 — Restos de roteamento que enganam a conectividade:** pista `REFIN1+` de 11,25 mm em B.Cu solta em (163,9; 84,9);
pista `+3.3V_ANA` de 0,7 mm em (138,2; 86,8); via `+3.3V_ANA` em (139,9; 112,6) ligada só numa camada; três pistas
`AIN5/AIN6_ADC_Load_Cell±` soltas em (151,0; 92,3), (157,8; 87,0), (150,9; 91,8). Apagar ou completar.

**I4 — Zona órfã `ilha_1cm2_catodo_D25` em `+12V_TPS`, B.Cu (162,5-177,0; 116,0-124,5).** Herdada da V2.2 (o D25 de
então era um TVS; hoje D25 é um BAV199 em 184,6; 96,5). Fica isolada (2 avisos `isolated_copper`), o pad `+12V_TPS` mais
perto está a 7,3 mm (U11.6) e por baixo dela está D11 (TVS do AIN4). Apagar; se a ilha térmica era para um TVS de
`+12V_TPS`, redesenhá-la debaixo do díodo certo.

### MENOR

- **M1 — Serigrafia órfã do selector:** «2V5» em (157,1; 81,4) e «3V3» em (161,4; 81,4), a 7,7 e 11,7 mm do H1 (agora em
  150,0; 78,4, 2x3). Refazer: 2V5 / 5V / 3V3 junto a cada fila, na ordem do esquemático (1-2 = 2V5, 3-4 = 5V, 5-6 = 3V3).
- **M2 — U12 TPS7A4001 (HVSSOP-8): clearance 0,15 mm entre pads NC 6/7 e pads `+24V_ADC` 5/8**, regra Power24 pede
  0,25. É o passo de 0,65 mm do encapsulado, não o roteamento. Ou os NC vão à rede do pino vizinho no esquemático, ou
  regra DRC que isente os pads NC de U12.
- **M3 — `+24V_ADC` a 0,20 mm** nos cinco troços de fan-out dos pinos 5/8 de U12 (classe Power24 = 0,50). Inevitável no
  passo de 0,65; manter curtos (hoje ≤ 1,3 mm) e alargar logo a seguir.
- **M4 — `Load_Cell+`/`Load_Cell-` a 0,20 mm** (classe Analog = 0,25) em 16 troços entre P2 e R31/R32. Sem efeito
  eléctrico (µA, mV); ou se alarga para 0,25 ou se muda a classe, para o DRC não mentir.
- **M5 — Courtyard C20/C14** sobrepostos (143,0 vs 140,4; 85,4): 0603 a 2,6 mm de centro a centro; afastar 0,15 mm.
- **M6 — Paridade: MPN do U5** (PCB `ISO7141FCCDBQ`, esquemático `ISO7141CCDBQR`). Actualizar PCB a partir do
  esquemático. `lib_footprint_mismatch` em P1/P2 (`HDR1X20/1X14_FEMALE` diferem da biblioteca): actualizar da biblioteca
  ou aceitar por escrito.
- **M7 — Serigrafia:** 57 `silk_over_copper` + 32 `silk_overlap`. Passo final, depois de fechar o cobre.

### Verificado e em ordem

- **Rule areas seguem as peças** (corrigido desde a revisão anterior): Fid1 0,00 mm, Fid2 0,15, Fid3 0,22, barreira ISO7141
  0,70 mm do centro de U5.
- **TPS26613 §11.1:** VSNS a ≥ 2,70 mm de qualquer rede de laço na mesma camada, fora do encapsulado; bypass `+12V_TPS`
  a 2,49-2,54 mm do pino 6 dos quatro U8-U11.
- **AD7124 p.73:** nenhuma pista de rede alheia passa debaixo do U6 (caixa ±3,5 mm); desacoplo AVDD C14/C15 a ~5 mm
  (o datasheet pede «right up against the device» — aceitável, não óptimo).
- **`+3.3V_ANA`:** nasce em U3.5 com C11/C12 no nó e FB2/FB3 a sair desse nó; tronco 0,4 mm até C14/C15 (ADC) e
  C22/C23 (ADR4525); nada de errado na topologia, faltam H1.6, U13/C41, D22/D24/D25.
- **H1 2x3:** redes dos pads = esquemático (1-3-5 `EXC_SEL`; 2 `+2V5_EXC`; 4 `+5V_ADC`; 6 `+3.3V_ANA`); os cortos das
  12:02 foram resolvidos pelo projectista.
- **Larguras:** `+24V`/`+24V_REG` 0,50; `+12V_TPS`, `+5V*` 0,40; laços 0,30 — conforme netclasses, salvo M3/M4.
- Nenhum footprint fora do contorno (118,5-178,5 × 75,0-135,0).

### Não verificado nesta passada

Continuidade do plano `GND_ADC` em In1/In2 sob as pistas de B.Cu (ranhuras), estrangulamentos de enchimento das zonas,
DFT (pontos de teste do plano T&Q), atributos `dnp` PCB × esquemático, ficheiro de posição. Datasheets em falta na pasta:
LP5907 (U13), RB162MM (D23), Samtec FTS (H1), KOA SG73P (R30, lido do download de hoje).

```yaml
evidencia:
  skill: 2shw-pcb:check-roteamento (pre-revisao, sem sessao independente)
  artefatos: [relatorio_roteamento_EBM7_V23L_2026-09-22.md, output/drc_report.json (MCP)]
  sessao_independente: false
  modelo_verificador: Claude Fable 5.1 (mesmo da sessao de edicao)
  drc_violacoes: 102
  por_ligar: 38
  paridade: 1
  bloqueantes: 1
  importantes: 4
  menores: 7
  veredito: NAO-LIMPO
  rodada: 1
```

## Adenda 18:22 — B1 corrigido (opção A, aplicada nesta sessão; verificar em sessão independente)

- Zonas `DGND_B/In1/In2`: bordo inferior a **y = 116,504 para x 126,5–132,5**; mantém-se a 122,304 para x ≤ 126,5, porque
  P1.16 (DGND) e P1.17 (+5V) estão em y 119–121,5 e a pista +5V sobe até (125,3; 117,4). `GND_ADC_*` recebeu a língua
  x 127,001–133,001 × y 117,004–122,304 (0,5 mm de folga em todos os lados).
- Movidos: **C7 → (133,6; 112,1)** (pad +5V_ADC a 1,75 mm de U3.1), **R5 → (130,5; 116,85)**, **D5/R4/T4 → direita do Recom**
  (155,4 / 156,95 / 157,9). Apagados: 13 troços de +5V_ADC na região DGND, 3 de EN, vias GND (134,0;112,6), (134,0;117,4),
  (132,8;115,45), (127,4;116,2) e os tocos; novas vias GND em (133,5;115,45), (134,3;118,35), (127,35;118,7), (155,4;127,0).
- +5V_ADC novo: FB1.2 → R5.2 → y 117,7 → via (134,2;117,45) → B.Cu x 134,75 → via (134,75;113,6) → C7.2 / U3.1, e B.Cu até
  (134,9;103,4) onde retoma a pista existente para H1.6. +5V_REG: U1.3 → y 129,7 → x 157,9 → T4 → R4.1.
- **Medido: mínimo cobre isolado ↔ campo 0,300 → 1,200 mm** (pista +3.3V ↔ pads de R5); nenhum cobre de campo na região DGND.
- DRC 102 → 99 violações (só serigrafia: −3 `silk_over_copper`, +1 `silk_overlap` nas referências de C7/C11/C12/C23),
  por ligar 38 → 35, paridade 1 (MPN do ISO7141, inalterado). Backups: `.antes_barreira` (17:42) … `.antes_barreira5`.
- **Novo achado pré-existente, mesma classe:** pista **+3.3V em B.Cu (124,8–128,0; y 95,0)** entra 1 mm na zona `GND_ADC_B`
  junto a C9/U5 (a escada de `GND_ADC` começa em x 127,0 para y < 95,2): 0,3 mm até o enchimento de campo na mesma camada.
  Corrigir subindo-a para y ≥ 95,5 ou encurtando-a a x ≤ 126,5. Não tocado.

## Adenda 23-09-2026 06:32 — estado actual (só leitura; KiCad aberto)

DRC 120 violações (99 ontem às 18:22), **21 por ligar** (35), paridade 1. Copia com zonas reenchidas dá os mesmos números:
o que está por ligar é real. Desde as 18:22: 13 footprints movidos (R36/R37/R38 e C48/R39 para a direita do U6, C47 junto a
U13, D24/D25 trocados, D21 rodado), 656 → 691 segmentos, 106 → 113 vias, zona órfã `ilha_1cm2_catodo_D25` apagada (I4 fechado).

### Bloqueante novo
**B2 — D21 (TVS 824500101 de Load_Cell−) rodado de 0° para 90° em (168,6; 85,55).** As pistas continuavam a apontar aos pads
da orientação antiga: pad 1 (Load_Cell−) caiu sobre a pista Load_Cell+ (y 83,85) e pad 2 (GND) sobre a pista Load_Cell−
(y 87,15) → **2 `shorting_items`, 5 `solder_mask_bridge`, courtyard sobre D20 e D10, clearance 0,145 mm a D10.1**. Correcção:
voltar D21 a 0° (a pista Load_Cell− já termina em (170,64; 85,55), o pad 1 da orientação original) e ligar o pad 2 ao plano.

### Por ligar (21)
- **GND_ADC, 21 pads sem via:** C14.1, C15.2, C20.1 (desacoplo do ADC); C39.2, R29.2 (REFIN1+); C43.2, C44.1 (filtro da célula);
  D22.1, D24.1, D25.1 (clamps); D19.2, D20.2 (TVS excitação/célula); D6.2, D7.2, D9.2, D10.2, D12.2, D13.2 (TVS dos laços);
  U8.1, U8.3, U9.1 (GND dos TPS26613). Sem pour em F.Cu: uma via por pad ou pista curta até via.
- +3.3V_ANA: D22.2; +2.5_VREF: pista B.Cu 0,8 mm até U6.20 (e via solta em 145,9; 86,2); Load_Cell−: D21.1 (vai com B2).

### Estado dos itens de ontem
| item | estado |
|---|---|
| B1 barreira (FB1/C7/C5 lado PLC) | **fechado** 18:22; mínimo isolado↔campo 1,20 mm; sem cobre de campo na região DGND |
| I1 24 pads GND | 21 restam (lista acima) |
| I2 condensadores do Recom | aberto: C3 12,45 mm, C1 5,52 mm do pino |
| I3 restos soltos | quase fechado: só via +3.3V_ANA (139,9; 112,6) e via +2.5_VREF (145,9; 86,2) |
| I4 zona órfã +12V_TPS | **fechado** |
| M1 serigrafia 2V5/3V3 órfã | aberto (157,1 / 161,4; 81,4) |
| M2 U12 pads NC 0,15 mm | aberto (regra ou rede) |
| M3/M4 larguras +24V_ADC 0,20 / Load_Cell± 0,20 | aberto; novo: `Net-(D5-A)` 0,25 em classe Power24 (classe errada para um LED) |
| M5 courtyard C20/C14 | aberto |
| M6 MPN U5, P1/P2 vs biblioteca | aberto |
| M7 serigrafia | 63 + 40 avisos (cresceu com o placement) |
| +3.3V B.Cu (124,8–128,0; 95,0) na GND_ADC_B junto a C9 | aberto |
| Desacoplo longe: U5.7/U5.10 → 5,8 mm; U6.20 → C25 6,3 mm; U13 → C41 3,4/4,8 mm; VSNS → C37 15–20 mm | inalterado |

### Verificado em ordem
Rule areas seguem as peças; VSNS ≥ 2,70 mm dos laços; nada alheio sob U6; H1 e R30 conforme esquemático; nenhum footprint
fora do contorno; par da célula completo em F.Cu (AIN5 27,5 mm sem via, AIN6 24,9 mm com 2 vias), filtros ainda no lado do conector.

### Correcção de fonte (23-09-2026) — I2, condensadores do Recom
A frase «C1 and C2 are required and should be fitted close to the converter pins» está na secção **Dual Output (two Converters)
with Negative Output** do datasheet (REV 5/2019, p.6), não na aplicação de saída única que usamos. Para saída única o PDF **não
dá instrução de posição** dos condensadores, e o texto extraído não contém «Switching Frequency» (os 120–800 kHz citados ontem
não saem deste PDF). I2 passa a **recomendação de prática** (condensadores de entrada/saída de um conversor comutado junto aos
pinos), não a requisito de datasheet. Mantém-se como IMPORTANTE pela física, com a fonte corrigida.

## Adenda 23-09-2026 09:16 — cirurgia aplicada (caixas 1 e 2, aprovadas por Javier)

Aplicado com verificação de clearance (≥ 0,2 mm a cobre de outra rede, 4 camadas), porta sintáctica + `pcbnew.LoadBoard`
numa cópia antes de gravar, refill e DRC. Backups `.antes_cirurgia` (PCB e .kicad_pro) e `.antes_cirurgia2`.

- **B2 D21**: rodado 90° → 0°; pad 1 caiu na ponta da pista Load_Cell− (170,64; 85,55); pad 2 com via GND. 2 cortos, 5 pontes
  de máscara, 2 courtyards e 1 clearance desapareceram.
- **22 vias GND_ADC** (0,6/0,3, stub 0,3 mm): C14.1, C15.2, C20.1, C39.2, C43.2, C44.1, D6.2, D7.2, D9.2, D10.2, D12.2, D13.2,
  D19.2, D20.2, D21.2, D22.1, D24.1, D25.1, R29.2, U8.1, U8.3, U9.1; mais uma para o grupo C42.1/C45.1 em (161,2; 78,2).
- **Esquina C9/U5** (item «+3.3V B.Cu na GND_ADC_B»): escalão das zonas DGND 96,0 → 94,4 e GND_ADC 95,2 → 93,9; a via (128,0; 95,0),
  a pista B.Cu e C9 ficam dentro do contorno DGND; nenhum cobre PLC dentro do contorno GND_ADC nem cobre de campo dentro do DGND.
  Mínimo isolado ↔ campo mantém-se **1,20 mm**.
- +2.5_VREF: via (145,9; 86,2) ligada a U6.20. C14 −0,10 mm / C20 +0,06 mm (M5 fechado). MPN de U5 = ISO7141CCDBQR (M6,
  paridade 0). `Net-(D5-A)` passou de Power24 a Default no `.kicad_pro`. Load_Cell± 16 troços a 0,25 mm (M4 fechado).
- **Erro meu, corrigido na mesma passada:** a via +3.3V_ANA (139,95; 112,6) que o DRC dava «só numa camada» era o nó entre dois
  troços F.Cu; ao apagá-la partiu-se o ramo dos BAV199. Reposta a junção pelo ponto (139,95; 112,6), sem via.

**Estado:** DRC **97** violações (06:32: 120), das quais 2 erros (pads NC de U12, M2), 57 + 36 de serigrafia, 2 `lib_footprint_mismatch`
(P1/P2); **por ligar 1** (D22.2 ← +3.3V_ANA, sem caminho de 2 troços a partir de D25.2; fica para o projectista); paridade **0**;
nenhuma pista ou via solta. Abertos: I2 (Recom, prática), M1 (serigrafia H1), M2, M3 (+24V_ADC 0,20 no fan-out de U12), M7,
filtros da célula longe do ADC, P1/P2 vs biblioteca, desacoplos de U5/U6.20/U13 e VSNS.

## Adenda 23-09-2026 09:37 — D22.2 ligado pelo projectista; releitura

Javier rotou D22.2 ← +3.3V_ANA (PCB gravada 09:37:45): 9 troços de 0,40 mm + 1 via em (160,45; 80,8); sai de D22.2 em F.Cu, desce a
B.Cu, corre por y = 82,1 debaixo de D24 (lado oposto, com GND_ADC em In1/In2 entre) e entra no bus existente na via (154,75; 79,45).
Moveu ainda as vias GND de C42/C45 (159,2 → 159,55; 80,8) e de D22.1 ((162,6; 81,85) → (161,7; 80,55)). Nenhum footprint ou zona mudou.

- Clearance mínima do caminho novo: **0,382 mm** (F.Cu, vs ADC_Load_Cell+) e 0,400 mm (B.Cu, vs via GND) — acima dos 0,15 da classe e dos
  0,20 do meu critério. Barreira isolado ↔ campo: **1,200 mm**, inalterada.
- DRC: **98** violações, **0 por ligar** (era 1), paridade 0. A violação nova é um **toco redundante** de 0,25 mm em F.Cu,
  (160,45; 83,20)–(160,45; 82,95), sobreposto ao troço maior — apagar. Os 2 erros continuam a ser os pads NC de U12 (M2).
- Ficam como antes: M1 (textos «2V5»/«3V3» órfãos em (157,1; 81,4) e (161,4; 81,4) — o «3V3» está encostado ao pad 1 de D22), M2, M3
  (+24V_ADC a 0,20 no fan-out de U12), 57 + 36 de serigrafia, P1/P2 vs biblioteca, desacoplos «longe» da caixa 3
  (C1/C3 do Recom, C12, C25/C24 de U6.20/U7.6, C41 de U13, C37 dos VSNS).

## ⚠️ Correcção 24-09 — a barreira NÃO mede 1,20 mm

A revisão independente de 24-09 mediu **0,30 mm** cobre-a-cobre entre o domínio PLC e o campo em In1/In2. Re-medido nesta sessão
incluindo os **preenchimentos das zonas** (`barreira_real.py`): F.Cu 1,200 mm; **In1 0,300 mm; In2 0,300 mm; B.Cu 0,400 mm**. O par
crítico é a zona DGND contra a via GND_ADC em (128,20; 116,70) (segunda via de C5.1, presente desde antes da cirurgia de 23-09; C5.1 já
tem via própria em (127,35; 118,70)). Os 1,20 mm que escrevi mediam só pistas e pads, sem zonas — **erro de método meu**. A verificação
«nenhum cobre de campo dentro do contorno DGND» também não apanhou a via, porque ela fica fora do contorno mas a 0,3 mm do seu bordo.

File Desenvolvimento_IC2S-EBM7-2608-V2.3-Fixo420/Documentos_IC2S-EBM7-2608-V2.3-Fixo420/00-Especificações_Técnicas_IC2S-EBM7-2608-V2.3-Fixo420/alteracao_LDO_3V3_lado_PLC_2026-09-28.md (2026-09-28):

# Regulador de 3,3 V do lado PLC — U2: MCP1824ST-3302E/DB → SPX3819M5-L-3-3/TR (2026-09-28)

Da reunião de 25-09: «esse chip é mais caro… existe regulador menores». O U2 alimenta só o lado 1 do ISO7141 (+5V do P1 → 3,3 V, massa DGND).

## Comparação que decidiu (datasheets locais; preços da API Mouser gravados nos repositórios)

| | MCP1824ST-3302E/DB (saiu) | SPX3819M5-L-3-3/TR | MCP1824T-3302E/OT |
|---|---|---|---|
| Encapsulamento | SOT-223-3 | SOT-23-5 | SOT-23-5 |
| Entrada (operação / máx. absoluto) | 2,1-6,0 V / 6,5 V | 2,5-16 V / 20 V | 2,1-6,0 V / 6,5 V |
| Precisão em temperatura | ±2,5 % | ±2 % | ±2,5 % |
| Estável com cerâmico | sim, «Stable with 1.0 µF Ceramic» (DS22070A p.1) | **não especificado** («bench testing», SPX3819 rev. 2.0.5 p.7); provado em campo na V2.2 | sim (mesmo datasheet) |
| ESD HBM | ≥ 4 kV | 1 kV | ≥ 4 kV |
| Mouser 1 un. | 0,64 USD (25-09) | 0,51 USD (16-09) | 0,56 USD (25-09) |
| Stock Mouser | 11 898 (25-09) | **99** (16-09) | 14 500 (25-09) |

Carga real: só o lado 1 do ISO7141, ≤ 8 mA a 40 Mbps (TI SLLSE83F p.10). O ISO7141 pede VCC1 de 2,7 a 5,5 V
(p.5) e 0,1 µF a ≤ 2 mm do pino (p.22 e p.25): cumprido com qualquer um dos três (C a 1,9 mm).

**Critério da equipa (28-09-2026): menos MPN, mais peças do mesmo tipo.** Na EBM7 o SPX3819 já é o U3/U4 do
+3.3V_ANA; na EBM2 o MCP1824T já é o U4 do 3V3_REF. O MCP1824ST sai das três placas.

## O que mudou

- **U2 = SPX3819M5-L-3-3/TR**, SOT-23-5. Ligações: 1 IN e 3 EN a +5V, 2 GND a DGND, 4 BYP aberto (p.7 permite), 5 OUT a +3.3V.
- Condensadores mantidos (os que já estavam na entrada e na saída).
- PCB: pegada SOT-23-5 no mesmo sitio (127,45; 108,85); tiradas 11 pistas que acabavam nos pads antigos e 2 restos soltos. **Faltam rotear 6 ligações do U2.** Gerbers, BOM de fabrico, pick-and-place e stencil de 28-09 ainda mostram o MCP1824: regenerar depois do roteamento.

## Verificação

- ERC 0 erros; DRC 0 erros, 0 paridade, 6 por ligar (as do U2); netlist: só mudam os pinos do U2.

## Riscos em aberto

- **Estabilidade com cerâmico não garantida no datasheet** do SPX3819; a base é a experiência de campo da V2.2 (SPX3819 do +3.3V_ANA só com cerâmicos). Aqui a carga é ≤ 8 mA, o que joga a favor (p.7), mas não foi medido. Medir na 1.ª placa: 3,3 V em DC e, com osciloscópio emprestado, o ripple na saída.
- **Stock Mouser baixo** (99 un. a 16-09): confirmar antes da compra (LCSC tem).
- ESD 1 kV HBM (entrada no +5V do P1, conector interno: só conta no manuseio).
- Preços e stock são das consultas gravadas (16 e 25-09), não de hoje: a web da Mouser bloqueia leitura automática.

## Complemento: circuito recomendado do datasheet (SPX3819 rev. 2.0.5, Fig. 18 «Standard Application Circuit», p.8)

| Elemento | Datasheet | Na placa |
|---|---|---|
| EN | alto (> 2 V); «ENABLE may be tied directly to VIN» | EN directo a +5V ✅ |
| BYP | condensador «(Opt.)»; pode ficar aberto se o ruído não importa (p.7) | aberto ✅ |
| Entrada | medido com CIN = 1 µF (p.2-3) | 10 µF cerâmico ✅ |
| Saída | desenhado polarizado; 2,2 µF electrolítico ou 1 µF tântalo (p.7) | C8 10 µF + C9 100 nF + **C49 2,2 µF**, todos cerâmicos |

**C49 = 2,2 µF C1608X5R1E225K080AB** (MPN já na BOM) acrescentado em paralelo à saída do U2, para a saída ficar como a do SPX3819 da V2.2 em campo (2,2 µF + 10 µF + 100 nF, só cerâmicos; a V2.2 não tinha nenhum electrolítico junto do SPX3819: os únicos eram C5/C11 de 100 µF nos +24V_ADC dos PDM2). No PCB: clone da pegada do C8, a 3 mm do U2, **2 ligações por rotear**. ERC 0; DRC 0 erros, sem avisos novos.

## Layout final (PCB de 28-09, 17:15)

**Correcção à tabela acima:** o C9 (100 nF) **não é da saída do U2**. Está na mesma rede +3.3V, mas é o **bypass do VCC1 do ISO7141 (U5)**: TI SLLSE83F §10, «a 0.1-µF bypass capacitor is recommended at input and output supply pins (VCC1 and VCC2)… as close to the supply pins as possible». Durante o roteamento chegou a ser movido com o grupo do U2 (ficou a 6,3 mm do VCC1) e foi reposto.

| Condensador | Função | Distância pad a pad |
|---|---|---|
| C9 100 nF | bypass VCC1 do U5 (pino 1); massa por via DGND a 1,0 mm | 1,93 mm |
| C13 100 nF | bypass VCC2 do U5 (pino 16) | 1,98 mm |
| C49 2,2 µF | saída do U2 (pino 5), o mais próximo | 1,68 mm |
| C8 10 µF | saída do U2, atrás do C49 | 2,23 mm |
| C6 10 µF | entrada do U2 (pino 1) | 3,03 mm |

O pino 7 do U5 (EN1) também está em +3.3V, mas é entrada lógica (habilita as saídas do lado 1); não precisa de desacoplamento.

Verificação: DRC kicad-cli com paridade — 0 erros, 0 avisos, 0 desligados, paridade 0. Barreira DIGSIDE/campo: 1,000 mm entre zonas DGND/GND_ADC (regra 1,0 mm), 1,04 mm entre pistas e pads. Gerbers, furação, PnP, stencil, BOM, vistas, STEP e PDF do esquemático regenerados a partir desta placa.

**Correcção (18:19):** a linha de pendentes da versão anterior atribuía o C35 ao U1 e falava de «C1/C2 do U1». C1/C2 são os nomes do datasheet da Recom, não referências da placa. Pelo esquemático: a entrada do U1 é o **C1** (folha 02, nota 9: «C1 = entrada do R-78HB»), a saída é o **C3** (folha 03), e o C35/C36/R27 pertencem à folha 06 (laços). O C2 da placa já não existe (saiu com o ramo único de 24 V).

## Condensadores do U1 (PCB de 28-09, 18:19)

| Condensador (Recom) | Placa | Distância pad a pad |
|---|---|---|
| C1, entrada | **C1** 10 µF/100 V | +24V_ADC → pino 1: 2,94 mm; massa → pino 2: 2,92 mm; via GND_ADC a 1,62 mm |
| C2, saída | **C3** 22 µF | +5V_REG → pino 3: 2,32 mm; massa → pino 2: 4,98 mm; via GND_ADC a 1,05 mm |

Antes estavam a 10,9 e 12,4 mm; a Recom pede «C1 and C2 are required and should be fitted close to the converter pins». C4/C5 continuam no filtro do +5V_REG para o FB1, fora do laço do conversor.

C35 (folha 06) passou de 0,53 mm para 2,23 mm do bordo; o eixo continua perpendicular ao bordo (só importa se a placa for em painel com V-cut desse lado).

DRC kicad-cli com paridade: 0 erros, 0 desligados, paridade 0; 1 aviso cosmético (texto «C35» sobre o pad do C36). Pacote de fabricação regenerado desta placa (18:23).

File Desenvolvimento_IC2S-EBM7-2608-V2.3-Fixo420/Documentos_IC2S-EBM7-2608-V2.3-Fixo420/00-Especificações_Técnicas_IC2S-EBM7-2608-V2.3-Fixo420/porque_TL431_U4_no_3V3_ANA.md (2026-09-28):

# Porque existe o U4 (TL431B) no +3.3V_ANA

Pergunta da reunião de 25-09-2026: *«o SPX3819 já regula os 3,3 V; para que serve o TL431?»*

## Resposta curta

O U3 (SPX3819) **só consegue fornecer corrente, não a absorver**. O U4 existe para o caso contrário: quando entra
corrente **de fora** no +3.3V_ANA e empurra o rail para cima. Quem a mete lá são os díodos de protecção das entradas.
Sem o U4, essa corrente não tem para onde ir e o rail sobe até queimar o ADC. Em funcionamento normal o U4 está
desligado e não faz nada.

## O caminho da corrente, passo a passo

1. Cada entrada analógica do ADC tem um **BAV199** (D14, D15, D16, D17, D22, D24, D25): um díodo para o GND_ADC e outro para o **+3.3V_ANA**.
2. Se a tensão numa entrada passar de ~3,3 V + 0,6 V (surto no cabo, sensor ligado mal, 24 V no borne errado), o díodo
   de cima conduz e **despeja a corrente no +3.3V_ANA**. É exactamente para isso que ele lá está: proteger o pino do ADC,
   que aguenta no máximo **AVDD + 0,3 V** (AD7124-8 Rev. F, p.14, *Analog Input Voltage to AVSS*).
3. Essa corrente tem de sair do rail por algum lado. O SPX3819 é um LDO série: o transístor de saída liga a entrada à
   saída e só puxa corrente **da entrada para a saída**. Não há no datasheet (MaxLinear SPX3819 Rev. 2.0.5) nenhuma
   especificação de corrente absorvida na saída: ele simplesmente corta.
4. Sem o U4, a corrente só pode ir para o consumo das cargas (ADC, referência, alguns mA) e para os condensadores do
   rail, que carregam. Se o surto trouxer mais corrente do que as cargas gastam, **o rail sobe**. A revisão kicad-happy
   (folha 3, nota 14) estimou que chegava a ~10 V.
5. O AVDD do AD7124 tem **máximo absoluto de 3,96 V** (p.14, *AVDD to AVSS*). A 10 V o ADC morre, e com ele a
   referência U7 e o que mais estiver no rail.

O U4 fecha esse caminho: com o rail acima de ~3,6 V ele conduz e absorve a corrente para o GND_ADC, segurando o rail.

## Os números

O U4 é um regulador *shunt*: conduz quando a tensão no pino REF passa de V_ref. O divisor R6 4k42 / R7 10k faz o
limiar ser V_ref × (1 + 4,42/10) = V_ref × 1,442.

| Grandeza | Valor | Fonte |
|---|---|---|
| V_ref (TL431B) | 2,440 / 2,495 / 2,550 V (mín / típ / máx) | TI SLVS543S, p.6 |
| Limiar do clamp | **3,52 / 3,60 / 3,68 V** | 1,442 × V_ref |
| Com 100 mA a atravessar | +0,07 V (\|Z_KA\| ≤ 0,5 Ω × 1,442) → até ~3,75-3,79 V | SLVS543S p.6; folha 3, nota 14 |
| Saída do SPX3819 | 3,3 V ± 2 % em temperatura → **3,37 V no máximo** | SPX3819 p.2 |
| Folga entre os dois | 3,52 − 3,37 = **0,15 V**: em serviço o U4 nunca conduz | — |
| AVDD máx. absoluto do AD7124 | **3,96 V** | AD7124-8 p.14 |
| Folga do clamp ao máx. absoluto | 3,96 − 3,79 = 0,17 V no pior caso | — |
| Corrente que o U4 aguenta | 100 mA recomendado, 150 mA máx. absoluto | SLVS543S p.5 |
| Corrente residual estimada de um surto | 12-23 mA (corrida 4) | folha 3, nota 14 |
| Consumo permanente do divisor | 3,3 V / 14,42 kΩ = **0,23 mA** | — |
| Fuga do U4 desligado | ≤ 1 µA | SLVS543S p.6, I_off |

## Porque não outra peça

- **Zener de 3,6 V** (ZMM5227B, da mesma série do D4 já usado; Diodes DS30024 Rev. C-2, p.2): V_Z = **3,42-3,78 V a
  20 mA**, Z_ZT = 24 Ω a 20 mA e Z_ZK = **1700 Ω a 0,25 mA**. Dois problemas:
  - joelho mole: com 1700 Ω perto do joelho, o zener já conduz a 3,3-3,37 V e carrega o LDO permanentemente. A fuga
    só está especificada a 1 V (≤ 15 µA), não a 3,3 V;
  - clamp alto: a 100 mA fica em ~3,78 + 0,08 A × 24 Ω ≈ **5,7 V**, bem acima dos 3,96 V do ADC.
  O TL431B tem joelho abrupto (≤ 1 µA desligado), Z_KA ≤ 0,5 Ω e 0,5 % de tolerância.
- **TVS de 3,3 V**: o mesmo problema, maior. Os TVS de baixa tensão têm fuga alta e clamp muito acima do standoff.
- **Não pôr nada e confiar no LDO**: é o caso descrito acima. O LDO não absorve corrente.
- **Custo**: o TL431BQDBZR custa ~0,44 USD à unidade (Mouser, BOM da EBM2 de 25-09) e o divisor são duas
  resistências 0603.

## Resumo para o revisor

| | Sem o U4 | Com o U4 |
|---|---|---|
| Serviço normal | 3,3 V | 3,3 V (o U4 está desligado; gasta 0,23 mA no divisor) |
| Surto numa entrada | o BAV199 despeja no rail, o LDO não absorve, o rail sobe (~10 V) e o ADC morre | o U4 absorve até 100 mA e o rail fica ≤ 3,79 V, abaixo dos 3,96 V do ADC |

O mesmo raciocínio está resumido na **folha 3, nota 14** do esquemático. A EBM2 V5 tem o mesmo circuito (U3, folha 3,
nota 7), com o limiar a 3,52 V.

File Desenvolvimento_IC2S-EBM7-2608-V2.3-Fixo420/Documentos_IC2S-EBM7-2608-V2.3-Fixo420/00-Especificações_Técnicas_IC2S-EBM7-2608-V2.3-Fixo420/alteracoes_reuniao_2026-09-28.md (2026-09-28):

# Alterações de 28-09-2026 — revisão da reunião

Quatro observações da reunião, aplicadas ao esquemático e ao PCB. Notas no esquemático: **folha 2, notas 2, 13 e 14**.

## 1. Ramo único de 24 V

**Antes:** depois do TVS havia dois ramos iguais, F1 → D2 → +24V_REG (só o U1, R-78HB) e F2 → D3 → +24V_ADC (laços,
LDO de 12 V, LED), cada um com o seu 10 µF / 100 V.

**Agora:** saem **F2, D3 e C2**. F1 → D2 → **+24V_ADC** alimenta tudo; o nome +24V_REG deixa de existir.

- Motivo (equipa): é tudo alimentado pelos mesmos 24 V; os ramos não eram canais independentes nem isolados; ganha-se espaço.
- Corrente: 116 mA em regime, ~180 mA em falha (folha 1, nota 2) contra F1 = 750 mA e D2 = MBR1H100SF 1 A.
- Arranque: ~30 µF a jusante do F1; pela escala da nota 10 (3,4 mA²s para 20 µF) dá ~5 mA²s contra 150 mA²s de fusão:
  **~29× de margem** (era ~44× no ramo com 20 µF). Estimativa, não medida.
- Custo: perde-se a selectividade. Um curto no +24V_ADC abre F1 e desliga a placa inteira (antes só o ramo dos laços).

PCB: saíram as três peças, a pista do ânodo (Net-(D3-A)), a ligação do díodo à diagonal e o toco de GND do condensador. O bus
+24V passa a acabar no pad 1 do F1. A pista do C1 desce em F.Cu (139,80; 127,20 → 128,80) e junta-se, a 45°, à diagonal
que já ia para a via do +24V_ADC em (141,20; 130,10). Largura 0,50 mm (classe Power24). No `.kicad_pro` saíram os padrões
de netclass `+24V_REG` e `Net-(D3-A)`.

## 2. Condensador de entrada do R-78HB

**C1 = 10 µF / 100 V, 1210 (GRM32EC72A106ME05L)**, a 5,5 mm do pino Vin. Recom R-78HB-0.5 (rev. 5-2019), p.4: *«To
protect the converter during power-up, use C1 = 3.3 µF/100V if Vin > 50V»*. Operamos a 24 V, mas o clamp do TVS é 53,3 V,
portanto aplica-se — e 10 µF / 100 V cumpre. A capacidade de saída (~50 µF) está abaixo do máximo de 100 µF (p.2). O
1 µF / 100 V da p.6 é da configuração de saída negativa, que não é a nossa. **Sem alteração.**

## 3. Tensão dos 100 nF

Todos os 25 eram GRM188R72A104KA35D (100 V). Só um precisa: o **C36**, no +24V_ADC (até 53,3 V).

| Grupo | Tensão máxima | Peça |
|---|---|---|
| C36 no +24V_ADC | 53,3 V (clamp) | fica GRM188R72A104KA35D, 100 V — valor `100nF/100V` |
| 4 no +12V_TPS | 12 V; 31,7 V com o divisor do LDO em falha (folha 6, nota 17) | **TDK C1608X7R1H104K080AA, 50 V** |
| 20 em 3,3 V, 5 V, ADC e referência | ≤ 5 V | **TDK C1608X7R1H104K080AA, 50 V** (um só MPN) |

25 V não serve: não cobre os 31,7 V do +12V_TPS. Fonte: catálogo TDK *MLCC commercial general*, p.34 (X7R, 1608,
100 nF ±10 %, DC 50 V). Valor escrito `100nF/50V`. São 24 peças.

## 4. Mesmo MPN para a mesma função

- 10 µF nos rails de 2,5 / 3,3 / 5 V: já era um só MPN (0603YD106KAT2A). Sem alteração.
- 2,2 µF, 22 µF e 10 µF / 100 V (1210): um MPN cada. Sem alteração.
- **1 µF: havia dois** (885012206002 em 1 e C0603C105K4RACTU em 3). Agora os quatro são **TDK C1608X7R1H105K080AB**
  (X7R, 1608, 1 µF ±10 %, DC 50 V; catálogo TDK p.35). Valor escrito `1uF/50V` (antes havia `1uF` e `1uF/16V`).

O catálogo TDK está em `Projeto_…/Documentos_de_Referência-…/TDK_mlcc_commercial_general_en.pdf`.

## Verificação

- Netlist antes/depois: só saem F2, D3, C2 e a rede Net-(D3-A); C1 / D2 / U1 passam de +24V_REG a +24V_ADC; 28 condensadores
  mudam de valor/MPN. Nenhuma outra ligação muda.
- ERC: 0 erros (os avisos são os mesmos de antes).
- DRC (`--severity-all --schematic-parity --all-track-errors`): 0 erros, 62 avisos (serigrafia), 0 por ligar, paridade 0.
- Gerbers, furos, BOM (55 linhas, 134 peças, 133 a montar), pick-and-place (144 linhas), stencil, PDF do esquemático, vistas e STEP regenerados.

Scripts (sessão de 28-09): `sch_2809.py` (esquemático), `pcb_2809.py` (PCB), `pro_2809.py` (netclasses).

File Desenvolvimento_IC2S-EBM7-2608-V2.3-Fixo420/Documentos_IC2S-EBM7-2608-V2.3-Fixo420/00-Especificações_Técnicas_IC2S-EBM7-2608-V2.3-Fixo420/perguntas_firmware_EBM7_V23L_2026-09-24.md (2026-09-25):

# Perguntas ao firmware — EBM7 V2.3 legacy 4-20 mA

Objectivo: fechar suposições do hardware e confirmar as constantes que **mudam** com esta versão. Prioritárias: 1, 2, 5–8 e 10.

## 1. Configuração actual do AD7124

1. Que referência usa cada canal (REFIN1, REFIN2, interna 2,5 V ou AVDD)? Os laços 4-20 mA medem contra **REFIN2 (ADR4525, 2,5 V)**? O orçamento de exactidão assume que sim.
2. Que referência estava configurada no firmware da **V2.2**? (Na placa, R150/R151/R152 montados punham REFIN2 a 5 V — fora do permitido; ou o firmware usava AVDD?)
3. Por canal: ganho, buffers de entrada e de referência, taxa de saída e filtro (rejeição 50/60 Hz).
4. Mapa de pinos AIN usado — confirmar contra o esquemático: AIN1–AIN4 laços, AIN5/AIN6 célula, AIN8/AIN9 temperatura, REFIN1 ratiométrica.

## 2. Constantes que mudam na legacy

5. Burden: 160 Ω (V2.2) → **110 Ω**.
6. Referência dos laços: **2,5 V (ADR4525)**.
7. Divisor da NTC: 5k62 → **22k (R37)**. Que fórmula/tabela usa a NTC?
8. Célula de carga: medição **ratiométrica** contra REFIN1, série 1k3 + filtro diferencial. A fórmula assume a tensão de excitação ou trabalha em proporção?

## 3. Calibração (decide se RF2 < 0,2 % se cumpre)

9. É feita a calibração interna de zero e fundo de escala no arranque?
10. Há calibração por placa com corrente padrão, guardada em memória? Sem ela o pior caso é 0,30 %; com ela, 0,16 %.
11. Constante comum a todas as placas ou por unidade?

## 4. Diagnóstico e falhas

12. Detecção de laço aberto (< 3,6 mA) e de falha (> 21 mA)? O ADC mede até 22,7 mA.
13. Com transmissor em curto o TPS26613 limita 100 ms e corta 800 ms em ciclo; a leitura pulsa. O firmware filtra ou sinaliza? (SGOOD não está ligado.)
14. Usam REF_DET (REFIN < 0,7 V) ou o registo de erros? Detectariam shunt errado em H1 ou célula desligada.
15. Lêem AVDD, IOVDD ou a referência pelos canais internos para vigiar as alimentações?

## 5. Excitação e comunicação

16. Como sabe o firmware que tensão de excitação o shunt de H1 seleccionou (5 V / 3,3 V / 2,5 V)?
17. Frequência do SCLK do SPI? O ISO7141 acrescenta atraso e limita a velocidade máxima.
18. Usam as fontes de corrente internas ou os GPIO do AD7124 para alguma coisa?

---

## Resposta do Rodrigo (software do Raspberry Pi) — resumo e verificação, 24-09

- **Não há firmware na EBM7**: o software do Pi fala com o AD7124 por SPI (1 MHz, modo 3, sem CRC) e converte para engenharia.
- **V2.2**: todos os canais com referência **AVDD 3,3 V**; REFIN1/REFIN2 não usados; referência interna habilitada. Vetor de fábrica 16.244.633 a 3,2 V → 3,305 V ✔.
  Mas o REFIN2 e o REFOUT estavam ligados ao +5V_ADC por 0 Ω (acima de AVDD + 0,3 V = 3,6 V) → **AD7124 das V2.2 sob suspeita**. Na legacy +2,5_VREF não toca o 5 V e R8 é DNP ✔.
- **Calibração**: 6 pontos (0–20 mA) por unidade e por canal, guardada no Pi → cenário 0,16 % ✔. Sem calibração interna do AD7124.
- **Configuração**: célula ganho 128 bipolar ~400 SPS; laços ganho 1 unipolar ~4800 SPS; SINC3, sem rejeição 50/60 Hz; todos os buffers ligados.
- **Mapa**: AI1 = AIN4 … AI4 = AIN1 — **igual na legacy** (seguido pela netlist: P2.7 → U8 → R10 → FB4 → R18 → AIN1_ADC → pino 8 = AIN4). Negativo dos laços = DGND interno (código 19).
- **Vetor novo** [0; 2.952.790; …; 14.763.950] = I·110/2,5·2²⁴ ✔.
- **NTC não é lida hoje**; RF3 exige-a → função nova.

## Retorno do hardware às perguntas dele

| Tema | Resposta | Fonte |
|---|---|---|
| Buffers em 0 V | laços AIN_BUFP 1 / AIN_BUFM 0, negativo **AVSS (17)**; REFIN2 REF_BUFM 0 (REF_BUFP opcional); **REFIN1 REF_BUFP = 1 obrigatório** (divisor 10k/10k = 5 kΩ × ±12 µA ≈ 60 mV), REF_BUFM 0 | AD7124 p.7, p.8, p.91; netlist (pino 13 REFIN1− e 21 REFIN2− a GND_ADC) |
| Limite superior | NAMUR NE 43: ≤ 3,6 e ≥ 21,0 mA falha; 20,5–21,0 sobre-alcance; saturação 22,7 mA | NE 43; 2,5 V/110 Ω |
| SGOOD | impossível nesta placa (ISO7141 com 4 canais no SPI; GPIO do AD7124 só saídas); detectar por código máximo ~100 ms + ~0 durante 800 ms | TI p.23; decisão 04-09 |
| NTC | Vishay NTCS0603E3103JLT R25 10 kΩ ±5 %, **B25/85 3435 K ±1 %** (tabela da série, linha …3103*LT); divisor REFOUT → R36 → AIN9 → R37 22k → GND; referência interna tem de ficar habilitada; AIN9 vs AVSS, ref interna, ganho 1; −40 °C 0,20 V, +85 °C 2,35 V → RF3 ✔ (modelo β) | Vishay NTCS0603E3; netlist |

## Texto de resposta ao Rodrigo (pronto para enviar)

Olá, Rodrigo,

Muito obrigado, as respostas esclareceram bastante. Conferi tudo contra a placa e seguem os retornos.

**CONFIRMAÇÕES**
- O vetor de fábrica novo está correto: 0,44 V / 2,5 V × 2^24 = 2.952.790 contagens em 4 mA.
- O mapa invertido (AI1 = AIN4 … AI4 = AIN1) é o mesmo na V2.3; não muda nada no software.
- A calibração de 6 pontos por placa e por canal cobre o requisito de 0,2 % (cenário de 0,16 %).

**BUFFERS EM 0 V**
Concordo em desligar os buffers que ficam em 0 V. O AD7124 permite ligar cada buffer separadamente:
- Laços: AIN_BUFP = 1 e AIN_BUFM = 0. Sugiro usar AVSS (código 17) como negativo em vez de DGND (19); na placa os dois vão ao GND_ADC, mas o AVSS é a terra analógica.
- REFIN2 (laços, ADR4525): REF_BUFM = 0. O REF_BUFP pode ficar desligado, porque o ADR4525 tem impedância baixa.
- REFIN1 (célula): REF_BUFP = 1 é obrigatório. O REFIN1 vem de um divisor de 10k/10k (5 kΩ) e, sem buffer, a corrente de entrada de ±12 µA daria cerca de 60 mV de erro. REF_BUFM = 0.
- Com isso a célula fica ratiométrica: o REFIN1 vale metade da excitação, qualquer que seja o jumper do H1.

**LIMITE SUPERIOR**
Sugiro o critério NAMUR NE 43: abaixo de 3,6 mA e acima de 21,0 mA é falha; entre 20,5 e 21,0 mA, sobre-alcance. O ADC satura em 22,7 mA.

**SGOOD**
Não dá para levar ao Raspberry nesta placa: o SGOOD fica do lado de campo, o ISO7141 usa os 4 canais no SPI e os GPIO do AD7124 são só saídas. Por software dá para detectar: com transmissor em curto, a leitura fica no código máximo por uns 100 ms e depois perto de zero por 800 ms, em ciclo. Sugiro sinalizar "sobrecorrente" quando aparecer o código máximo.

**NTC**
O canal de NTC é requisito (RF3 do escopo), então entra na V2.3:
- NTC Vishay NTCS0603E3103JLT: 10 kΩ a 25 °C (±5 %), B25/85 = 3435 K (±1 %).
- O divisor é alimentado pelo REFOUT: REFOUT → NTC → AIN9, com 22 kΩ do AIN9 ao GND. Por isso a referência interna precisa continuar habilitada.
- Medição: AIN9 contra AVSS, referência interna de 2,5 V, ganho 1, AIN_BUFP = 1 e AIN_BUFM = 0. Fica ratiométrica.
- Fórmula: R_NTC = 22 kΩ × (1/razão − 1), com razão = V_AIN9 / 2,5 V; depois 1/T = 1/298,15 + ln(R_NTC/10 kΩ)/3435 (T em K).
- Faixa: cerca de 0,20 V a −40 °C e 2,35 V a +85 °C, dentro da faixa do ADC.

**SUGESTÕES (não urgentes)**
- Ativar alguma rejeição de 50/60 Hz, pensando nos cabos de 40 m em ambiente industrial.
- Usar o REF_DET na célula: sem jumper no H1 o REFIN1 cai abaixo de 0,7 V e isso é detectado.
- Ler o registrador de erros e, na célula, fazer a calibração interna de zero na inicialização.

**SOBRE OS 5 V NA V2.2**
Você tem razão em levantar isso. Na V2.2 o REFIN2 e a saída da referência interna ficavam ligados ao +5V_ADC por resistores de 0 Ω, acima do máximo absoluto de 3,6 V. Vamos considerar os AD7124 das placas V2.2 como suspeitos. Na V2.3 isso não existe mais.

Se quiser, marcamos a chamada para fechar os detalhes.

Abraço,
Javier

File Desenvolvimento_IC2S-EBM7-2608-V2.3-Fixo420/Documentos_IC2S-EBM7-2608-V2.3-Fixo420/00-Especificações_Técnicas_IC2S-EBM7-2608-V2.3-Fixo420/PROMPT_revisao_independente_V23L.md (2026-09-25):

# Prompt — revisión independiente EBM7 V2.3 legacy

Copiar todo lo que está entre las dos líneas en una sesión NUEVA de Claude Code
(idealmente con otro modelo), abierta en `C:\hw\hw-ebm7-v2.2`.

---

Eres un revisor independiente de hardware. Vas a revisar una PCB que diseñó otra persona y que otra sesión de IA
modificó. Tu trabajo es verificar, no validar: busca lo que está mal, no confirmes lo que está bien.

## Objeto de la revisión

- Proyecto KiCad 10: `Desenvolvimento_IC2S-EBM7-2608-V2.2\Projeto_IC2S-EBM7-2608-V2.2\KiCad_EBM7_V23_LEGACY_4-20\`
  - PCB: `IC2S_Extension_Board_Model_7-EBM7-2608_V23L_Load_Cell_4AI.kicad_pcb`
  - Esquemático raíz: `IC2S_Extension_Board_Model_7-EBM7-2608_V23L_Load_Cell_4AI.kicad_sch` (8 hojas)
  - Biblioteca de footprints del proyecto: `footprints\EBM7_V23.pretty\`
- Datasheets locales: `Desenvolvimento_IC2S-EBM7-2608-V2.2\Projeto_IC2S-EBM7-2608-V2.2\Documentos_de_Referência-IC2S-EBM7-2608-V2.2\`
- Requisitos del producto: `Desenvolvimento_IC2S-EBM7-2608-V2.2\Documentos_IC2S-EBM7-2608-V2.2\00-Especificações_Técnicas_IC2S-EBM7-2608-V2.2\escopo_EBM7_respin.md` (tabla RF1–RF6).

Es una placa de expansión de PLC: AD7124-8 con 4 lazos 4-20 mA (protectores TPS26613), una célula de carga en puente
con excitación seleccionable por jumper (H1: 5 V / 3,3 V / 2,5 V) y una NTC; aislador ISO7141 hacia el lado digital.

## Datos de entrada que no están en el CAD

El software que lee el AD7124 corre en una Raspberry Pi (no hay firmware en la placa). Su configuración actual,
informada por el responsable del software el 24-09-2026: referencia AVDD en todos los canales; todos los buffers de
entrada y de referencia activados; laços con ganancia 1 unipolar, negativo = DGND interno (código 19); célula con
ganancia 128 bipolar; SINC3, sin rechazo 50/60 Hz; modo continuo, full power, reloj interno; SPI 1 MHz modo 3;
calibración de 6 puntos por placa y por canal guardada en el Pi; AIN8/AIN9 (NTC) no configurados. Tienen previsto
pasar los laços a REFIN2 y la célula a REFIN1.

## Tareas, en este orden

1. **`/2shw-pcb:check-roteamento`** sobre la PCB indicada. Solo lectura.
2. **`/2shw-pcb:verificar-aplicacao-datasheet`** para todos los CI críticos: AD7124-8 (U6), ADR4525 (U7),
   ISO7141 (U5), TPS26613 (U8–U11), TPS7A4001 (U12), LP5907 (U13), SPX3819 (U3), MCP1824 (U2), R-78HB (U1),
   TL431 (U4), y los TVS/diodos de protección. Incluye las restricciones cruzadas entre componentes y el test de una
   multiplicación por cadena analógica (lazo, célula, NTC), evaluando también la configuración de software descrita
   arriba contra el datasheet del AD7124.
3. Un informe final que junte las dos cosas, con los hallazgos ordenados por severidad.

## Reglas

- **Solo lectura.** No modifiques ningún archivo del proyecto, no hagas commits, no ejecutes `sch_annotate`.
  Tus scripts y archivos temporales van a la carpeta temporal de la sesión.
- No toques ni uses como referencia `KiCad_EBM7_V2.3_ensaio_SPI` ni `KiCad_EBM7_V2.3_mouser`.
- **No leas** los informes previos de esta placa hasta haber terminado tus propios hallazgos:
  `relatorio_roteamento_*.md`, `relatorio_emc_*.md`, `verificacao_aplicacao_*.md`, `comparacao_BOM_*.md`,
  `perguntas_firmware_*.md` de la carpeta del proyecto. Al final, y solo al final, puedes compararlos y decir en qué
  coincides y en qué no.
- Toda frase atribuida a un datasheet sale de una búsqueda en el PDF en esta sesión, con página. Si no está, escribe
  «no consta en este PDF». Pinouts: confirma en el dibujo renderizado, no solo en el texto.
- Clasifica cada conclusión por su fuente: A (datasheet), B (física/medida en la placa), C (regla del proyecto),
  D (criterio propio). Un umbral que no venga del datasheet se marca D.
- Mide sobre la geometría real (pcbnew con `C:\Program Files\KiCad\10.0\bin\python.exe`, o `kicad-cli`), no sobre
  suposiciones. Los footprints pueden traer pads pasantes que funcionan como vías: cuéntalos.
- Datos conocidos como faltantes: la sensibilidad de la célula (mV/V) no está definida; el datasheet local del diodo
  D23 es del RB162MM-40, pero la BOM usa RB162MM-60TR. Trátalos como «falta dato», no los inventes.
- Murata, TDK, onsemi y ADI bloquean descargas automáticas: si falta un datasheet, márcalo `[FD]` y sigue.

## Entregables (en portugués, en la carpeta temporal de la sesión)

- `check_roteamento_V23L_independente.md`
- `verificacao_aplicacao_V23L_independente.md`
- `revisao_independente_V23L_resumo.md` — veredicto (lista para fabricar / no), bloqueantes, hallazgos por
  severidad con fuente A/B/C/D, lo que no pudiste verificar y por qué, y al final la comparación con los informes
  previos.

---

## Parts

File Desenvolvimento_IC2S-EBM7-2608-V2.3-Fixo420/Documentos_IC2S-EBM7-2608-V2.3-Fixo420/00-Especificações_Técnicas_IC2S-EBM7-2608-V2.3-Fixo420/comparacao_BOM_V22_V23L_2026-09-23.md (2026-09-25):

# Comparação de componentes — EBM7 V2.2 (fabricada) → V2.3 legacy 4-20 mA

**Fontes:** BOM de fabricação da V2.2 (`Arquivos_Fabricação…/01-BOM_List…/BOM_PartType-…V22….xls`) e netlist reconstruída da V2.2
(`Reconstruida_IC2S-EBM7-2608-V2.2.Net`); esquemático da V2.3L exportado hoje (`kicad-cli sch export bom` e `netlist`).
**Método:** os designadores foram renumerados entre versões, por isso a correspondência é feita **pela função**: as redes a que cada
peça liga em cada versão. Onde a função foi deduzida da topologia (e não de um documento), está marcado *(inferido)*.

| | V2.2 | V2.3L |
|---|---|---|
| Peças montadas | 119 (BOM) | 137 + 1 DNP (R8) |
| Números de peça distintos | 43 | 54 |

## 1. Entrada e alimentação

| Função | V2.2 | V2.3L | Nota |
|---|---|---|---|
| Alimentação do lado de campo | 2 × **PDM2-S24-S24-S** (U1, U2), DC/DC isolado 24→24 V 2 W | laço directo de +24V por F2 e D3 (+24V_ADC) + **TPS7A4001DGNR** (U12), LDO 24→12 V (+12V_TPS, ±Vs dos TPS26613) com R25 93k1 / R26 10k | o lado de campo deixa de ser isolado do 24 V; GND_24V–GND_ADC unidos por R1 0 R (nota 7 da folha 02) |
| 5 V do lado analógico | **CRE1S2405SC** (U3), DC/DC isolado 24→5 V 1 W | **R-78HB5.0-0.5L** (U1), buck não isolado | |
| Fusíveis de entrada | 0466.125NR 125 mA (F1) + 2 × 3413.0008.22 160 mA (F2, F7) | 2 × **CC12H750MA-TR** (F1, F2) | 3 → 2 |
| Díodos de polaridade | 3 × PMEG6010CEH (D1, D3, D5) | 2 × **MBR1H100SFT3G** (D2, D3) | 3 → 2 |
| TVS na entrada +24V | — | **SMA6J33A-Q** (D1) | novo |
| Bulk de entrada/saída 10 µF | 5 × UMK316BBJ106ML 10 µF 50 V 1210 | 3 × **GRM32EC72A106ME05L** 10 µF 100 V 1210 (C1, C2, C35) + **C3216X5R1H106K** 10 µF 50 V 1206 (C38, +12V_TPS) | |
| Electrolíticos | 2 × ESL107M050AGMAA 100 µF THT | — | saem |
| 100 nF no 24 V do campo | 2 × C1206C104M5RAC 100 nF 50 V 1206 | GRM188R72A104KA35D 100 nF 100 V 0603 (C34, C36) | |
| Condensadores Y da barreira | 6 × C1206C102KGRACTU 1 nF 2 kV | — | saem com a isolação |
| Bulk do 5 V | GRM32ER61A107ME20K 100 µF 10 V 1210 (C17) | 2 × **CL21A226KOQNNNG** 22 µF 0805 (C3, C5) | |
| Carga no +5V_REG | — | 2 × **RC1206FR-07220RL** 220 R 1206 (R2, R3) | novo; carga mínima do Recom *(inferido)* |
| Clamp do +5V_REG | ZMM5234B 6,2 V | ZMM5234B (D4) | mantido |
| LEDs | 3 × LG Q396-PS-35 com 2 × 14k7 (R1, R2) | 2 × **KG EELP41.22** (D5 com R4 2k2 no +5V_REG; D18 com **R27 22k** no +24V_ADC) | 3 → 2 |
| Zener no +24V | BZT52H-B2V4 2,4 V (D25) | — | sai |
| 3,3 V digital | MCP1824ST-3302E/DB (U8) | MCP1824ST-3302E/DB (U2) | mantido |

## 2. Referência, ADC e alimentação analógica

| Função | V2.2 | V2.3L | Nota |
|---|---|---|---|
| ADC | AD7124-8BCPZ | AD7124-8BCPZ (U6) | mantido |
| LDO 3,3 V analógico | SPX3819M5-L-3-3 (U4) | SPX3819M5-L-3-3 (U3) | mantido |
| Referência 2,5 V | ADR4525 (U7) — está na netlist mas **não na BOM XLS** | ADR4525BRZ (U7) | mantido; a BOM da V2.2 omite U7 e C43–C46 |
| Protecção do +3.3V_ANA | — | **TL431BQDBZR** (U4), shunt 3,6 V, com R6 4k42 / R7 10k | novo |
| Desacoplo 100 nF | 15 × TMK107BJ104KA 100 nF 25 V | 26 × **GRM188R72A104KA35D** 100 nF 100 V | uniformizado a 100 V |
| 1 µF | 885012206002 | 885012206002 (C21) + 3 × **C0603C105K4RACTU** (C22, C41, C47) | |
| Filtros passantes | 2 × NFM18PC104R1C3D | 2 × NFM18PC104R1C3D (C15, C16) | mantidos; footprint corrigido hoje |
| Ferrites | 7 × BLM18PG471SN1D | 7 × BLM18PG471SN1D | mantidas |

## 3. Laços 4–20 mA (×4)

| Função | V2.2 | V2.3L | Nota |
|---|---|---|---|
| Protector de laço | — | 4 × **TPS26613DDFR** (U8–U11) + divisor VSNS R22 11k5 / R23, R24 6k65 | novo |
| Resistência de medida (burden) | 249 R + 160 R em série = 409 Ω (8 peças) | 4 × **110 R** (R13, R14, R15, R17) | nota (2) da Table 8-2 do TPS2661x; **sem MPN no esquemático** |
| Fusível por canal | 4 × F0603G0R10FNTR 70 mA 0603 | 4 × **3413.0002.22** 1206 (F3–F6) | |
| TVS na alimentação do laço (+24V_AINx) | 4 × 824500301 | 4 × **SMBJ36A-13-F** (D9, D10, D12, D13) | |
| TVS no sinal (AINx) | 4 × 824500301 | 4 × 824500301 (D6, D7, D8, D11) | mantido |
| Clamp à entrada do ADC | 4 × BAT54SLT1G | **BAV199LT1G** (D14–D17) | |
| 0 R | 3 × 0 R (R150–R152, no +2.5_VREF) | 6 × 0 R (R1 net-tie, R10, R11, R12, R16; R8 DNP) | funções diferentes, não comparar peça a peça |

## 4. Célula de carga

| Função | V2.2 | V2.3L | Nota |
|---|---|---|---|
| Resistência de excitação | CR1206-FX-18R0ELF 18 R ¼ W | **SG73P2BTTD68R0F** 68 R 1 W (R30) | |
| Selector de excitação | FTS-102-01-L-D, 2×2 (+3,3 V) | **FTS-103-01-L-D**, 2×3 (5 V / 3,3 V / 2,5 V) + **RB162MM-60TR** (D23) | |
| Fonte 2,5 V de excitação | — | **LP5907MFX-2.5** (U13) + C47 1 µF | novo (previsão) |
| Resistências série da célula | 2 × ERA-3AEB101V 100 R 0,1 % | 2 × **RG1608P-132-B-T5** 1k3 0,1 % (R31, R32) + **C46** 2,2 µF diferencial | filtro anti-aliasing |
| Referência ratiométrica (REFIN1+) | — | 2 × **RG1608P-103-B-T5** 10k 0,1 % (R28, R29) + BAV199 (D22) | novo |
| TVS nas linhas da célula | 2 × 824500301 | 2 × **824500101** (D20, D21) | |
| TVS na excitação | 824500301 (em IEXC2) | **SMA6J6.0A** (D19, em IEXC_OUT) | |
| Clamp à entrada do ADC | 2 × BAV199LT1G | BAV199LT1G (D24, D25) | mantido |

## 5. NTC

| Função | V2.2 | V2.3L |
|---|---|---|
| NTC | NTCS0603E3103JLT | NTCS0603E3103JLT (R36) |
| Resistência do divisor | ERA-3AEB5621V 5k62 0,1 % | **RG1608P-223-B-T5** 22k 0,1 % (R37) |
| Resistências 3k | 2 × RC0603FR-073KL | 2 × RC0603FR-073KL (R38, R39) |
| Filtro | GCM188R71H103KA37J 10 nF | GCM188R71H103KA37J (C48) |

## 6. Mantidos sem alteração

AD7124-8BCPZ, ISO7141CCDBQR, MCP1824ST-3302E/DB, SPX3819M5-L-3-3, ADR4525, NFM18PC104R1C3D, BLM18PG471SN1D, 824500301 (4 de 11),
BAV199LT1G, ZMM5234B, 0603YD106KAT2A, C1608X5R1E225K080AB, 885012206002, GCM188R71H103KA37J, NTCS0603E3103JLT, CRCW0603100KFKEA,
RC0603FR-072K2L, RC0603FR-073K3L, RC0603FR-073KL, RC0603JR-070RL, M20-7822046 (P1), M20-7821446 (P2).

## 7. Pendentes encontrados nesta comparação

- **R13, R14, R15, R17 (110 R) sem MPN** no esquemático da V2.3L.
- A **BOM XLS da V2.2 não lista U7 (ADR4525) nem C43–C46**, que estão na netlist reconstruída; a BOM de fabricação da V2.2 estava incompleta.
- A exportação agrupada do `kicad-cli` marca os seis 0 R como DNP porque agrupa por valor; só **R8** é DNP. Qualquer BOM de compra tem de ser
  exportada sem agrupar por valor, ou agrupando também pelo campo DNP.

## 8. Dimensionamento do burden de 110 Ω e orçamento RF2 (adenda 23-09)

**Fontes (A):** TI SLVSFE3C p.5 (IOL 25/32/40 mA; IQ ≤ 0,1 µA), p.6 (V(SNSR) 1,72 V, V(SNSF) 1,00 V só típico), p.20 Table 8-2 notas (1)(2),
p.23 Table 8-3 (MODE = GND); Schurter USFF 1206 p.4 (3413.0002 = 50 mA, 430 mV a In); ADI ADR4525 Rev. G p.4 (grau B ±0,02 %,
soldadura ±0,02 %, 2 ppm/°C box, VIN 3–15 V, dropout 500 mV), p.9 (25 ppm/1000 h), p.35 Table 11 (COUT ≥ 1 µF), p.6/p.9 (carga 0,1–100 µF);
AD7124-8 Rev F p.5 (erro de ganho ±0,0025 % G = 1, deriva 1–2 ppm/°C). **Premissas (D):** barramento 18–32 V (decisão 15-09); ambiente
20–60 °C (ΔT 40 K, decisão 04-09); os canais 4-20 mA medem contra +2,5_VREF (ADR4525) — configuração de firmware, não verificada.

| Restrição | Conta | Resultado |
|---|---|---|
| Fundo de escala do ADC | 2,5 V / 110 Ω | 22,7 mA — 20 mA usa 88 %; cobre falha NAMUR ≥ 21 mA |
| TI nota (1) | R1 + R2 = 11k5 + 3k325 = 14,8 kΩ ≤ 12,09 V / 45 µA = 269 kΩ | passa |
| TI nota (2) | V(SNSF)·(R1+R2)/R2 = 4,46 V > I·Rb | 20 mA: 2,2 V (margem 2×); 22 mA: 2,4 V; 40 mA (limite máx.): 4,40 V — margem 1,3 %, só em falha |
| Tensão disponível ao transmissor a 18 V, 20 mA | 18 − D3 ≈ 0,5 [FD] − fusível 0,18 − TPS 12,5 Ω máx. 0,25 − Rb 2,2 | ≈ 14,9 V (transmissores típicos pedem 10–12 V) |
| Potência | 20 mA: 44 mW; 22,7 mA: 57 mW; falha 40 mA: 176 mW 100 ms / 0,9 s | exige ≥ 0,1 W (0,125 W preferível) e capacidade de pulso |
| ADR4525 | VIN 3,3 V ≥ 3,0 V; COUT = C24 100 nF + C25 10 µF = 10,1 µF (1…100 µF) | passa |

**Orçamento RF2 (< 0,2 % FS) com burden 0,1 % / 25 ppm/K:** inicial 0,1 + 0,02 + 0,02 + 0,0025 = 0,14 %; deriva em 40 K 0,1 (Rb) + 0,008 (ref)
+ 0,008 (ADC) + 0,04 (auto-aquecimento ≈ 15 K) + 0,005 (ref, 4500 h) = 0,16 %. **Sem calibração:** pior caso 0,30 % ❌, RSS 0,15 %.
**Com calibração por unidade a 25 °C:** pior caso 0,16 % ✅. Com burden 1 %/100 ppm não cumpre nem calibrado (0,4 % só de deriva).

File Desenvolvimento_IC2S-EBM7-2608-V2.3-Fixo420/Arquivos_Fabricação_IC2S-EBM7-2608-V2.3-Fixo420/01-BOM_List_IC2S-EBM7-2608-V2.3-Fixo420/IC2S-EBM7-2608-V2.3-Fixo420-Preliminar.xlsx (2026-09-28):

Item | Referencias | Valor | Footprint | MPN | Qtd | DNP | Qtd_a_montar
1 | C1,C34,C35 | 10uF/100V | EBM7_V23:C_1210_3225Metric | GRM32EC72A106ME05L | 3 |  | 3
2 | C3,C5 | 22uF | EBM7_V23:C_0805_2012Metric | CL21A226KOQNNNG | 2 |  | 2
3 | C4,C9,C10,C12,C13,C18,C19,C20,C23,C24,C26,C27,C28,C29,C30,C31,C32,C33,C37,C39,C40,C42,C43,C44 | 100nF/50V | EBM7_V23:0603C | C1608X7R1H104K080AA | 24 |  | 24
4 | C6,C8,C14,C17,C25,C45 | 10uF | EBM7_V23:0603C | 0603YD106KAT2A | 6 |  | 6
5 | C7,C11,C46,C49 | 2.2uF | EBM7_V23:0603C | C1608X5R1E225K080AB | 4 |  | 4
6 | C15,C16 | 100nF FT | EBM7_V23:NFM0603 | NFM18PC104R1C3D | 2 |  | 2
7 | C21,C22,C41,C47 | 1uF/50V | EBM7_V23:0603C | C1608X7R1H105K080AB | 4 |  | 4
8 | C36 | 100nF/100V | EBM7_V23:0603C | GRM188R72A104KA35D | 1 |  | 1
9 | C38 | 10uF/50V | EBM7_V23:C_1206_3216Metric | C3216X5R1H106K160AB | 1 |  | 1
10 | C48 | 10nF | EBM7_V23:0603C | GCM188R71H103KA37J | 1 |  | 1
11 | D1 | SMA6J33A-Q | EBM7_V23:DO-214 | SMA6J33A-Q | 1 |  | 1
12 | D2 | MBR1H100SF | EBM7_V23:SOD123 | MBR1H100SFT3G | 1 |  | 1
13 | D4 | ZMM5234B | EBM7_V23:SOD-80C | ZMM5234B | 1 |  | 1
14 | D5,D18 | KG EELP41.22 | EBM7_V23:0603LED | KG EELP41.22-PHRH-35-A8J8-20-R18 | 2 |  | 2
15 | D6,D7,D8,D11 | 824500301 | EBM7_V23:DO-214 | 824500301 | 4 |  | 4
16 | D9,D10,D12,D13 | SMBJ36A | EBM7_V23:DO-214AA | SMBJ36A-13-F | 4 |  | 4
17 | D14,D15,D16,D17,D22,D24,D25 | BAV199 | EBM7_V23:SOT23-3 | BAV199LT1G | 7 |  | 7
18 | D19 | SMA6J6.0A | EBM7_V23:DO-214 | SMA6J6.0A | 1 |  | 1
19 | D20,D21 | 824500101 | EBM7_V23:DO-214 | 824500101 | 2 |  | 2
20 | D23 | RB162MM-60 | EBM7_V23:SOD-123F | RB162MM-60TR | 1 |  | 1
21 | F1 | CC12H750MA-TR | EBM7_V23:1206F | CC12H750MA-TR | 1 |  | 1
22 | F3,F4,F5,F6 | 3413.0006.22 | EBM7_V23:1206F | 3413.0006.22 | 4 |  | 4
23 | FB1,FB2,FB3,FB4,FB5,FB6,FB7 | 470R@100MHz | EBM7_V23:0603FB | BLM18PG471SN1D | 7 |  | 7
24 | H1 | FTS-103-01-L-D | EBM7_V23:HDR2X3_1.27mm-Without_number | FTS-103-01-L-D | 1 |  | 1
25 | P1 | M20-7822046 | EBM7_V23:HDR1X20_FEMALE | M20-7822046 | 1 |  | 1
26 | P2 | M20-7821446 | EBM7_V23:HDR1X14_FEMALE | M20-7821446 | 1 |  | 1
27 | R2,R3 | 220R | EBM7_V23:1206R | RC1206FR-07220RL | 2 |  | 2
28 | R4 | 2k2 | EBM7_V23:0603R | RC0603FR-072K2L | 1 |  | 1
29 | R5 | 100k | EBM7_V23:0603R | CRCW0603100KFKEA | 1 |  | 1
30 | R6 | 4k42 | EBM7_V23:0603R | RMCF0603FT4K42 | 1 |  | 1
31 | R7,R9,R26 | 10k | EBM7_V23:0603R | RC0603FR-0710KL | 3 |  | 3
32 | R8 | 0R | EBM7_V23:0603R | RC0603JR-070RL | 1 | DNP | 0
33 | R10,R11,R12,R16 | 0R | EBM7_V23:0603R | RC0603JR-070RL | 4 |  | 4
34 | R13,R14,R15,R17 | 110R | EBM7_V23:0603R | RG1608P-111-B-T5 | 4 |  | 4
35 | R18,R19,R20,R21 | 3k3 | EBM7_V23:0603R | RC0603FR-073K3L | 4 |  | 4
36 | R22 | 11k5 | EBM7_V23:0603R | RC0603FR-0711K5L | 1 |  | 1
37 | R23,R24 | 6k65 | EBM7_V23:0603R | RC0603FR-076K65L | 2 |  | 2
38 | R25 | 93k1 | EBM7_V23:0603R | RMCF0603FT93K1 | 1 |  | 1
39 | R27 | 22k | EBM7_V23:0603R | ERJ-3EKF2202V | 1 |  | 1
40 | R28,R29 | 10k 0.1% | EBM7_V23:0603R | RG1608P-103-B-T5 | 2 |  | 2
41 | R30 | 68R 1W | EBM7_V23:1206R | SG73P2BTTD68R0F | 1 |  | 1
42 | R31,R32 | 1k3 0.1% | EBM7_V23:0603R | RG1608P-132-B-T5 | 2 |  | 2
43 | R36 | NTC 10k | EBM7_V23:0603R | NTCS0603E3103JLT | 1 |  | 1
44 | R37 | 22k 0.1% | EBM7_V23:0603R | RG1608P-223-B-T5 | 1 |  | 1
45 | R38,R39 | 3k | EBM7_V23:0603R | RC0603FR-073KL | 2 |  | 2
46 | U1 | R-78HB5.0-0.5L | EBM7_V23:R-78HBxx-0.5L_SIP-3H | R-78HB5.0-0.5L | 1 |  | 1
47 | U2,U3 | SPX3819M5-L-3-3/TR | EBM7_V23:SOT-23-5 | SPX3819M5-L-3-3/TR | 2 |  | 2
48 | U4 | TL431B | EBM7_V23:SOT23-3 | TL431BQDBZR | 1 |  | 1
49 | U5 | ISO7141CCDBQR | EBM7_V23:SSOP16-4.9x3.9mm | ISO7141CCDBQR | 1 |  | 1
50 | U6 | AD7124-8BCPZ | EBM7_V23:LFCSP-32-2 | AD7124-8BCPZ | 1 |  | 1
51 | U7 | ADR4525BRZ | EBM7_V23:SOIC8 | ADR4525BRZ | 1 |  | 1
52 | U8,U9,U10,U11 | TPS26613DDFR | EBM7_V23:SOT-23-8 | TPS26613DDFR | 4 |  | 4
53 | U12 | TPS7A4001DGN | EBM7_V23:HVSSOP-8-1EP | TPS7A4001DGNR | 1 |  | 1
54 | U13 | LP5907MFX-2.5 | EBM7_V23:SOT-23-5 | LP5907MFX-2.5/NOPB | 1 |  | 1
 | PRELIMINAR - placa ainda sem revisao independente do roteamento (2shw-pcb:check-roteamento). Gerado do esquematico em 28-09-2026.

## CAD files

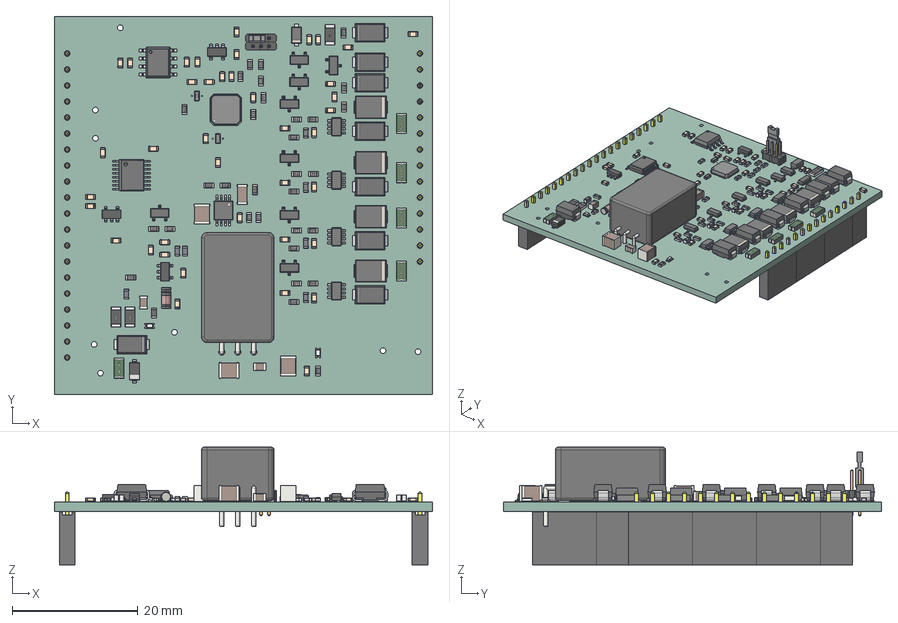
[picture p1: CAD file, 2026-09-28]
Desenvolvimento_IC2S-EBM7-2608-V2.3-Fixo420/Documentos_IC2S-EBM7-2608-V2.3-Fixo420/01-Esquemáticos_IC2S-EBM7-2608-V2.3-Fixo420/IC2S-EBM7-2608-V2.3-Fixo420.step
60.0 x 60.0 x 18.7 mm
User Library-CAPC1608X___ x 40
User Library-RESC1608X___ x 32
MSOP-8-1EP_3x3mm_P0.65mm_EP1.68x1.88mm
C_1210_3225Metric x 3
User Library-so8-3
User Library-S1G-1 x 8
D_SMB x 4
C_1206_3216Metric
C_0805_2012Metric x 2
User Library-MAX_QSOP16
User Library-SMD RESISTOR-1 x 3
User Library-FUSER_nanoSMD x 5
User Library-SOT-23-3_body_1 x 8
User Library-SOT-23-3_pin_SOT_SOT-23_1 x 24
User Library-Murata_NFM18PS_Murata_NFM_body x 2
User Library-Murata_NFM18PS_Murata_NFM_terminals x 2
User Library-LED_0603_WS_Pocket002 x 2
User Library-LED_0603_WS_Pad004 x 2
User Library-LED_0603_WS_Fillet x 2
User Library-LED_0603_WS_Pocket001 x 2
User Library-LED_0603_WS_Pad x 2
User Library-FB_1608_Pad001 x 7
User Library-FB_1608_Cut x 7
9360D52E-9BD1-42F0-84E8-DD68B45C04DC
BDA441D8-A5C4-4C44-A8A0-E9EBD450C16B x 3
20493694-5DF9-4F19-89F9-3D9FA7465B40
Converter_DCDC_RECOM_R_78HB_05L_THT
SOT-23-8 x 4
D_SOD_123F
K÷rper2 x 3
Pin2 x 3
User Library-SOD80-2
User Library-ZL262-4SG x 9
IC2S-EBM7-2608-V2.3-Fixo420_PCB

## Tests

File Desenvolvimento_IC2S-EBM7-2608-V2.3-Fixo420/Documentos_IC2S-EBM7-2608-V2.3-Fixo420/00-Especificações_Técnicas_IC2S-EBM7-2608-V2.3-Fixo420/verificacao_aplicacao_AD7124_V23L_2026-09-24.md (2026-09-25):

# Verificação de aplicação — AD7124-8 (U6), EBM7 V2.3 legacy

**Placa:** `IC2S_Extension_Board_Model_7-EBM7-2608_V23L_Load_Cell_4AI` (PCB de 2026-09-23 12:09; netlist exportada do esquemático).
**Procedimento:** skill `2shw-pcb:verificar-aplicacao-datasheet`; linhas avaliadas por `tabela.py` (não escritas à mão), 47 linhas.
**Configuração de software:** a actual é a descrita pelo Rodrigo em 24-09 (V2.2: referência AVDD, todos os buffers ligados, AINM = DGND,
ganho 1 nos laços e 128 na célula, SINC3, SCLK 1 MHz modo 3); a proposta é a da resposta enviada a 24-09.

## 1. CIs e PDFs usados

| CI | PDF | Páginas |
|---|---|---|
| AD7124-8 (U6) | `AnalogDevices_AD7124-8_RevF.pdf` (Rev F) | 7, 8, 9, 10, 11, 14, 16, 17, 47, 73, 75, 89–91 |
| ADR4525 (U7) | `adr4520_4525_4530_4533_4540_4550.pdf` (Rev G, Downloads) | 4, 9, 35 |
| TL431BQ (U4) | `TI_TL431.pdf` | 14 (TL431BQ: Vref 2483–2507 mV, desvio ≤ 34 mV) |
| SPX3819 (U3) | `1016_SPX3819.pdf` | 2 (±1 % a 25 °C, ±2 % em temperatura, 57 ppm/°C) |
| TPS26613 (U8–U11) | `TI_TPS2661x.pdf` (SLVSFE3C) | 5 (IOL 25/32/40 mA) |
| ISO7141 (U5) | `TI_ISO7141CC.pdf` (SLLSE83F) | 8 (tPLH/tPHL ≤ 45 ns a 3,3 V) |
| TVS 824500101 (D20, D21) | `Wurth_824500101.pdf` | 1 (VDC 10 V, VBR 11,7 V ±5 %) |
| NTC NTCS0603E3103JLT (R36) | `Vishay_NTCS0603E3_serie.pdf` | tabela da série (R25 10 kΩ, B25/85 3435 K ±1 %) |

## 2. Tabela

| CI | fonte (§/tabela/nota, pág.) | fórmula | valores usados | resultado | veredito |
|---|---|---|---|---|---|
| AD7124-8 (U6) | Rev F p.9, AVDD-AVSS full power | `2,9 V <= AVDD <= 3,6 V (SPX3819 3,3 V +-2 %, 1016_SPX3819 p.2)` | Vn=3.300, tol=0.02 | Vn*(1-tol) = 3.234 ; Vn*(1+tol) = 3.366 | cumpre |
| AD7124-8 (U6) | Rev F p.9, IOVDD e IOVDD-AVSS | `1,65 <= IOVDD <= 3,6 V e IOVDD-AVSS <= 5,4 V` | Vn=3.300, tol=0.02 | Vn*(1+tol) = 3.366 | cumpre |
| TL431BQ (U4) x AD7124 | TL431 p.14 (Vref 2483-2507 mV, dev <= 34 mV) x AD7124 p.14 (abs max AVDD 3,96 V) | `clamp max = (Vref_max+dev)*(1+R6max/R7min) <= 3,96 V` | Vr=2.507, dev=0.034, R6=4464, R7=9900 | (Vr+dev)*(1+R6/R7) = 3.687 | cumpre |
| TL431BQ (U4) x SPX3819 | TL431 p.14 x SPX3819 p.2 | `clamp min > AVDD max normal (TL431 nao conduz em operacao)` | Vr=2.483, dev=0.034, R6=4376, R7=1.01e+04, Vavdd=3.366 | (Vr-dev)*(1+R6/R7) = 3.510 ; Vavdd = 3.366 | cumpre |
| TL431BQ (U4) x AD7124 | AD7124 p.9 (full power <= 3,6 V) | `clamp max <= 3,6 V (so com o SPX3819 em falha)` | Vr=2.507, dev=0.034, R6=4464, R7=9900 so em falha do regulador; abs max cumprido na linha anterior | (Vr+dev)*(1+R6/R7) = 3.687 | **FALHA** |
| AD7124-8 (U6) | Rev F p.73 | `AVDD: 0,1 uF encostado ao chip (C15 -> pino 26, mm)` | d=1.550 limiar 2,0 mm = criterio D (o datasheet nao da numero) | d = 1.550 | cumpre |
| AD7124-8 (U6) | Rev F p.73 | `AVDD: 1 uF tantalo || 0,1 uF (bulk, uF)` | C=10.000 C14 e MLCC 10 uF, nao tantalo: desvio de tipo, nao de valor | C = 10.000 | cumpre |
| AD7124-8 (U6) | Rev F p.73 | `IOVDD: 0,1 uF encostado ao chip (C16 -> pino 2, mm)` | d=2.760 limiar 2,0 mm = criterio D; C16 e NFM passante com 3 furos GND proprios | d = 2.760 | **FALHA** |
| AD7124-8 (U6) | Rev F p.73 | `IOVDD: 1 uF || 0,1 uF (bulk, uF)` | C=10.000 | C = 10.000 | cumpre |
| AD7124-8 (U6) | Rev F p.16 e p.73 | `REGCAPA e REGCAPD: 0,1 uF cada (C20, C19)` | Ca=0.1, Cd=0.1 | Ca = 0.1 ; Cd = 0.1 | cumpre |
| AD7124-8 (U6) | Rev F p.47 | `REFOUT: 0,1 uF obrigatorio com referencia interna activa (C18 100 nF + C21 1 uF)` | C=1.100 | C = 1.100 | cumpre |
| AD7124-8 (U6) | Rev F p.7 (Output Current 10 mA) | `carga do REFOUT (divisor NTC a +85 C) <= 10 mA` | Vr=2.500, Rntc=1451, R37=2.2e+04 | Vr/(Rntc+R37) = 0.0001066 | cumpre |
| AD7124-8 (U6) | Rev F p.73 (All analog inputs must be decoupled to AVSS) | `condensadores de AIN8/AIN9 a AVSS` | n=0 so C48 10 nF diferencial AIN8-AIN9; nenhum a AVSS | n = 0 | **FALHA** |
| AD7124-8 (U6) | Rev F p.73 (decouple the REFINx(+) ... to AVSS) | `REFIN1+: C39; REFIN2+: C24, C25` | n1=1.000, n2=2.000 | n1 = 1.000 ; n2 = 2.000 | cumpre |
| AD7124-8 (U6) | Rev F p.7 (External REFIN 0,5...AVDD) | `REFIN2 = ADR4525 2,5 V dentro de 0,5...AVDD` | V=2.500, Avdd=3.234 | V = 2.500 | cumpre |
| AD7124-8 (U6) | Rev F p.7 (buffered AVSS+0,1...AVDD-0,1) | `REFIN2(+) bufferizado: 2,5 V <= AVDD_min - 0,1` | V=2.500, Avdd=3.234 | Avdd-0.1 = 3.134 | cumpre |
| AD7124-8 (U6) | Rev F p.7 / p.47 (buffers pedem 100 mV) | `REFINx(-) = 0 V com REF_BUFM = 1 (config. actual do Pi: todos os buffers ligados)` | Vm=0 config. actual do software (Rodrigo 24-09) | Vm = 0 | **FALHA** |
| AD7124-8 (U6) | Rev F p.7 (unbuffered AVSS-0,05) | `REFINx(-) = 0 V com REF_BUFM = 0 (config. proposta)` | Vm=0 | Vm = 0 | cumpre |
| AD7124-8 (U6) | Rev F p.16 (REFIN1(+) >= AVSS+0,5) e p.8 (REF_DET < 0,7 V) | `REFIN1 pior caso (H1 = 2V5, Vf D23 = 0,7 V): Vb/2 >= 0,7 V` | Vs=2.500, Vf=0.7, Rb=350.000, R30=68.000 Vf do RB162MM-60 [FD]: datasheet ausente; 0,7 V e pessimista; ponte 350 ohm (RF1) | (Vs-Vf)/(Rb+R30)*Rb/2 = 0.7536 | cumpre |
| AD7124-8 (U6) | Rev F p.7 (buffered <= AVDD-0,1) | `REFIN1 melhor caso (H1 = 5 V, Vf = 0): Vb/2 <= AVDD_min - 0,1` | Vs=5.000, Vf=0, Rb=350.000, R30=68.000, Avdd=3.234 | (Vs-Vf)/(Rb+R30)*Rb/2 = 2.093 | cumpre |
| AD7124-8 (U6) | Rev F p.8 (unbuffered ref +-12 uA) x RF1 (erro < 0,5 %) | `REFIN1 sem buffer: 12 uA x (R28||R29) / REFIN1 < 0,5 %` | I=1.2e-05, R=5000, Vref=1.930 exige REF_BUFP = 1 no canal da celula | I*R/Vref = 0.03109 | **FALHA** |
| AD7124-8 (U6) | Rev F p.7 (buffered ref +-3 nA full power) | `REFIN1 com buffer: 3 nA x 5 kohm / REFIN1 < 0,5 %` | I=3e-09, R=5000, Vref=1.930 | I*R/Vref = 7.772e-06 | cumpre |
| AD7124-8 (U6) | Rev F p.7 (+-VREF/gain) | `laco: 20 mA x 110 ohm <= VREF2 = 2,5 V` | I=0.02, Rb=110.000, Vref=2.500 | I*Rb = 2.200 | cumpre |
| AD7124-8 (U6) | Rev F p.7 (G = 1 buffered 0,1...AVDD-0,1) | `laco AINP: 4...22,7 mA x 110 ohm dentro de 0,1...AVDD_min-0,1` | Rb=110.000, Avdd=3.234 | 0.004*Rb = 0.44 ; Avdd-0.1 = 3.134 | cumpre |
| AD7124-8 (U6) | Rev F p.7 | `laco AINM = AVSS/DGND (0 V) com AIN_BUFM = 1 (config. actual)` | Vm=0 config. actual do software | Vm = 0 | **FALHA** |
| AD7124-8 (U6) | Rev F p.7 (G = 1 unbuffered -0,05...) | `laco AINM = 0 V com AIN_BUFM = 0 (config. proposta)` | Vm=0 | Vm = 0 | cumpre |
| AD7124-8 (U6) | Rev F p.7 (unbuffered +-2,65 uA/V) x RF2 (< 0,2 %) | `laco AINP sem buffer: 2,65 uA/V x 2,2 V x R18 3k3 / 2,2 V < 0,2 %` | k=2.65e-06, V=2.200, R=3300 exige AIN_BUFP = 1 | k*V*R = 0.01924 | **FALHA** |
| AD7124-8 (U6) | Rev F p.7 (buffered +-3,3 nA full power) | `laco AINP com buffer: 3,3 nA x 3k3 / 2,2 V < 0,2 %` | I=3.3e-09, R=3300, V=2.200 | I*R = 1.089e-05 | cumpre |
| AD7124 x TPS26613 | AD7124 p.14 (AIN <= AVDD+0,3) x TPS2661x p.5 (IOL max 40 mA) | `falha: IOL_max x 110 ohm <= AVDD + 0,3 V` | I=0.04, Rb=110.000, Avdd=3.300 so com transmissor em curto e IOL > 32,7 mA | I*Rb = 4.400 | **FALHA** |
| AD7124 x TPS26613 | AD7124 p.14 (AINx input current 10 mA) | `falha: corrente no pino <= (4,4 - 3,3) / R18 <= 10 mA` | V=4.400, Avdd=3.300, R=3300 | (V-Avdd)/R = 0.0003333 | cumpre |
| AD7124-8 (U6) | Rev F p.75 (antialias obrigatorio; sem numero) | `laco: fc = 1/(2 pi R18 C27) <= f_mod/100` | R=3300, C=1e-07, fmod=6.144e+05 limiar /100 = criterio D | 1/(2*pi*R*C) = 482.288 | cumpre |
| AD7124-8 (U6) | Rev F p.7 (+-VREF/gain) x celula | `celula: S x Vb <= REFIN1/128 = (Vb/2)/128  (S em V/V)` | S=?, ratio=0.5 falta a sensibilidade da celula; com 2 mV/V usa 51 % da escala | missing: S | **falta dado** |
| AD7124-8 (U6) | Rev F p.7 (G > 1: AVSS-0,05...AVDD+0,05) | `celula: modo comum Vb/2 (H1 = 5 V) dentro de -0,05...AVDD+0,05` | Vcm=1.930, Avdd=3.234 | Vcm = 1.930 | cumpre |
| AD7124-8 (U6) | Rev F p.75 | `celula: fc diferencial = 1/(2 pi 2x1k3 (C46+C43/2)) <= f_mod/100` | R=1300, Cd=2.2e-06, Cc=1e-07, fmod=6.144e+05 | 1/(2*pi*2*R*(Cd+Cc/2)) = 27.206 | cumpre |
| AD7124 x TVS 824500101 | AD7124 p.14 x Wurth 824500101 p.1 (VBR 11,7 V +-5 %) | `celula ligada a 24 V por engano: V_TVS <= AVDD+0,3` | Vt=12.285, Avdd=3.300 o pino fica acima de AVDD+0,3 enquanto o BAV199 conduz; so em falha de cablagem | Vt = 12.285 | **FALHA** |
| AD7124 x TVS 824500101 | AD7124 p.14 (10 mA) | `idem: corrente maxima possivel no pino, sem contar o BAV199, <= 10 mA` | Vt=12.285, Avdd=3.300, R=1300 | (Vt-Avdd)/R = 0.006912 | cumpre |
| AD7124-8 (U6) | Rev F p.7 x escopo RF3 (-40...+85 C) | `NTC: V_AIN9 de -40 a +85 C dentro de 0,1...AVDD-0,1 (B = 3435 K, Vishay)` | Vlo=0.2035, Vhi=2.345, Avdd=3.234 | Vlo = 0.2035 ; Vhi = 2.345 | cumpre |
| AD7124-8 (U6) | Rev F p.7 (unbuffered +-2,65 uA/V) | `NTC sem buffer: 2,65 uA/V x 2,35 V x 3 kohm / 2,35 V < 0,1 %` | k=2.65e-06, V=2.345, R=3000 exige AIN_BUFP = 1 | k*V*R = 0.01864 | **FALHA** |
| AD7124-8 (U6) | Rev F p.7 x SPX3819 p.2 (57 ppm/C) x RF2 | `lacos com referencia AVDD (config. actual): deriva 57 ppm/C x 40 K < 0,2 %` | tc=5.7e-05, dT=40.000 calibracao por placa nao remove deriva; passar a REFIN2 | tc*dT = 0.00228 | **FALHA** |
| AD7124-8 (U6) | Rev F p.11 (t3, t4 >= 100 ns) | `SCLK 1 MHz: meio periodo >= 100 ns` | f=1e+06 | 0.5/f = 5e-07 | cumpre |
| AD7124 x ISO7141 | AD7124 p.11 (dados validos <= 80 ns) x ISO7141 p.8 (tPLH/tPHL <= 45 ns) | `ida e volta: 2 x 45 + 80 ns <= meio periodo` | tiso=4.5e-08, tv=8e-08, f=1e+06 | 2*tiso+tv = 1.7e-07 | cumpre |
| AD7124-8 (U6) | Rev F p.16 (SYNC baixo mantem o modulador em reset) | `SYNC alto: pull-up R9 10k a IOVDD` | pullup=1.000 | pullup = 1.000 | cumpre |
| AD7124-8 (U6) | Rev F p.17 (Connect the exposed pad to AVSS) | `EP (pino 33) ligado a GND_ADC` | ok=1.000 | ok = 1.000 | cumpre |
| AD7124-8 (U6) | Rev F p.73 (Avoid running digital lines under the device) | `pistas de outras redes sob o U6 (+-2,5 mm)` | n=0 | n = 0 | cumpre |
| AD7124-8 (U6) | Rev F p.73 (Avoid crossover of digital and analog signals) | `cruzamentos SPI x entradas analogicas em camadas diferentes` | n=0 | n = 0 | cumpre |
| ADR4525 (U7) x AD7124 | ADR4525 Rev G p.4 (VIN 3-15 V, dropout 500 mV) | `VIN = +3.3V_ANA min >= 3,0 V` | V=3.234 | V = 3.234 | cumpre |
| ADR4525 (U7) x AD7124 | ADR4525 p.35 Table 11 (C_OUT >= 1 uF) e p.9 (carga 0,1-100 uF) | `1 <= C24 + C25 <= 100 uF` | C=10.100 | C = 10.100 | cumpre |

cumpre: 35 · FALHA: 11 · falta dado: 1

## 3. Leitura dos resultados

As 11 linhas **FALHA** não são todas defeitos de placa. Separam-se em três grupos:

**A. Hardware — achados reais**

1. **AIN8/AIN9 (NTC) sem desacoplo a AVSS.** Rev F p.73: «All analog inputs must be decoupled to AVSS». Só existe C48 (10 nF) entre AIN8 e AIN9;
   o modo comum destas duas entradas não tem filtro. Correcção: um condensador de cada entrada a GND_ADC (ex.: 10 nF 0603), junto ao U6.
   Exige footprints novos → para a próxima revisão ou para a sem_trilhas.
2. **Sobretensão nas entradas em falha.** Com transmissor em curto e IOL acima de 32,7 mA (máx. 40 mA, TPS p.5) o burden chega a 4,4 V; com a
   célula ligada a 24 V por engano o TVS segura ~12,3 V. Nos dois casos o pino passa AVDD + 0,3 V (p.14) enquanto o BAV199 conduz. A corrente
   fica limitada por R18 (0,33 mA) e por R31/R32 (≤ 6,9 mA, dividida com o BAV199), abaixo dos 10 mA de p.14. Violação formal de tensão
   **só em falha**, com corrente dentro do limite.
3. **Clamp do TL431 no pior caso = 3,69 V**, acima dos 3,6 V de operação em full power (p.9), abaixo dos 3,96 V absolutos (p.14). Só actua com o
   SPX3819 avariado; em operação normal o TL431 não conduz (clamp mínimo 3,51 V > 3,37 V).
4. *(critério D)* C16 (0,1 µF do IOVDD) a 2,76 mm do pino; o datasheet diz «ideally right up against the device» sem número. É um NFM com os
   seus próprios furos a GND; observação, não bloqueante.

**B. Requisitos para o software do Raspberry (a configuração actual falha)**

| Registo | Canal | Valor | Linha que o exige |
|---|---|---|---|
| REF_BUFM | todos os que usam REFIN1/REFIN2 | **0** | REFINx(−) = 0 V < AVSS + 0,1 |
| AIN_BUFM | laços e NTC (negativo em AVSS) | **0** | AINM = 0 V < AVSS + 0,1 |
| REF_BUFP | célula (REFIN1) | **1** | sem buffer: 12 µA × 5 kΩ = 60 mV → 3,1 % |
| AIN_BUFP | laços e NTC | **1** | sem buffer: 19 mV → 0,87 % (laços) e 0,8 % (NTC) |
| REF_SEL | laços | **REFIN2** (ADR4525) | com AVDD a deriva do SPX3819 dá 0,23 % em 40 K > 0,2 % |
| REF_SEL | célula | **REFIN1** | ratiometria (RF1) |
| REF_SEL + REF_EN | NTC | **interna**, referência interna activa | o divisor é alimentado pelo REFOUT |

**C. Dado em falta**

- **Sensibilidade da célula de carga (mV/V).** Com 2 mV/V a escala é usada a 51 %; com 3 mV/V a 77 %. Qualquer valor até 3,9 mV/V cabe.

## 4. Teste de uma multiplicação por cadeia analógica

**Laço 4-20 mA** (AI1 → U8 → R10 0 Ω → burden 110 Ω → FB4 → R18 3k3 → AIN4, com C27 100 nF e BAV199):

| Corrente | Burden | Pino (buffer ligado, ±3,3 nA × 3k3 = 11 µV) | Código (REFIN2 2,5 V) |
|---|---|---|---|
| 4 mA | 0,44 V | 0,44 V | 2 952 790 |
| 20 mA | 2,20 V | 2,20 V | 14 763 950 |
| 22,7 mA | 2,50 V | 2,50 V | saturação |
| 40 mA (falha) | 4,40 V | ≈ AVDD + Vf (clamp) | saturação |

**Célula de carga** (H1 → D23 → IEXC2 → R30 68 Ω → IEXC_OUT → ponte 350 Ω; REFIN1 = V_ponte/2 por R28/R29):

| H1 | I_exc (Vf 0,4 V [FD]) | V_ponte | REFIN1 | Fundo de escala (G 128) | Sinal a 2 mV/V |
|---|---|---|---|---|---|
| 5 V | 11,0 mA | 3,85 V | 1,93 V | ±15,0 mV | 7,7 mV (51 %) |
| 3,3 V | 6,9 mA | 2,43 V | 1,21 V | ±9,5 mV | 4,9 mV (51 %) |
| 2,5 V | 5,0 mA | 1,76 V | 0,88 V | ±6,9 mV | 3,5 mV (51 %) |

**NTC** (REFOUT 2,5 V → R36 NTC → nó → R37 22k → GND; nó → R38 3k → AIN9; REFOUT → R39 3k → AIN8):

| Temperatura | R_NTC (B = 3435 K) | V_AIN9 | Corrente no REFOUT |
|---|---|---|---|
| −40 °C | 248 kΩ | 0,20 V | 9 µA |
| +25 °C | 10 kΩ | 1,72 V | 78 µA |
| +85 °C | 1,45 kΩ | 2,35 V | 107 µA |

## 5. O que nenhuma ferramenta viu

- **ERC, DRC e o analisador kicad-happy passam com a configuração actual do software**, que viola p.7 em três registos (REF_BUFM, AIN_BUFM,
  e a escolha de AVDD como referência). Só o cruzamento entre a p.7 do datasheet e a configuração do Rodrigo o mostra.
- A falta de desacoplo a AVSS em AIN8/AIN9 não gera aviso em nenhuma ferramenta: C48 existe e liga às duas entradas.
- As sobretensões em falha dependem de três CIs ao mesmo tempo (TPS26613 IOL máx., burden, abs máx. do AD7124) e de um TVS; nenhuma peça isolada falha.

## 6. Limites desta revisão

- **Não é independente:** feita na mesma sessão que alterou a placa e escreveu a resposta ao Rodrigo.
- Vf do RB162MM-60 (D23) sem datasheet local: assumido 0,4 V (0,7 V no pior caso de REF_DET, que ainda passa com 0,754 V).
- Não cobre: filtros digitais e rejeição 50/60 Hz (dependem da configuração final do software), ruído (tabelas de ruído p.19–20), o sensor de
  temperatura interno, burnout e diagnósticos, e o modelo do cabo de 40 m na medição ratiométrica da célula (4 fios, sem sense).
- Distâncias de desacoplo e o ADR4525 a 10,2 mm do REFIN2 (ADR4525 p.35: «as close to the load as possible») são qualitativas no datasheet;
  os limiares usados são critério D e estão marcados.

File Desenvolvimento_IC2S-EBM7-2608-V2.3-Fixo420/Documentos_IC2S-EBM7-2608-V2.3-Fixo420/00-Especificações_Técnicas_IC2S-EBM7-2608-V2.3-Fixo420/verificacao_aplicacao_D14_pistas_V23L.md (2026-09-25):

# Verificação de aplicação — pistas debaixo de D14 (BAV199, clamp de AIN1_ADC), EBM7 V2.3 legacy

**Pergunta do projectista (22-09-2026):** as pistas que passam debaixo de D14 podem ficar ou têm de mudar de sítio?
**Ficheiro:** `IC2S_Extension_Board_Model_7-EBM7-2608_V23L_Load_Cell_4AI.kicad_pcb`, mtime 2026-09-22 18:22:59. Só leitura.
**Skill:** `2shw-pcb:verificar-aplicacao-datasheet` (mesma sessão que editou a placa hoje: limitação declarada).

## 1. O que há debaixo de D14 (courtyard 154,05–157,97 × 87,17–90,63; SOT-23 em F.Cu, rot −90)

| camada | rede | o quê |
|---|---|---|
| F.Cu | GND_ADC, +3.3V_ANA, AIN1_ADC | os próprios acessos aos três pads (pad 1 GND, pad 2 +3.3V_ANA com via em 154,85;86,95, pad 3 AIN1_ADC) |
| **B.Cu** | **+3.3V_ANA, 0,40 mm** | **o bus que alimenta a coluna de clamps D14–D17 (x = 154,85, de y 86,85 a 112,95): passa por baixo de D14, 0,45 mm em planta do pad 1** |
| F.Cu | AIN5_ADC_Load_Cell+ | toco solto de 0,7 mm (157,85;87,0)–(157,35;86,5), a 0,74 mm do pad 1 — resto de roteamento |
| In1.Cu, In2.Cu | GND_ADC | planos contínuos sob toda a caixa |

Nó protegido: `AIN1_ADC` = U6.8, R18 (3k3), C27 (100 nF), D14.3. O bus de B.Cu alimenta **só** D14, D15, D16, D17, D22, D24, D25.

## 2. Datasheets usados (grep na sessão)

- onsemi **BAV199LT1/D Rev 12** (Aug 2024), 6 páginas: p.2 IR ≤ 5,0 nA @ 70 V (25 °C) / 80 nA @ 150 °C por díodo; CD ≤ 2,0 pF. **Não tem secção de layout** (p.6 é texto legal).
- Analog Devices **AD7124-8 Rev F**, p.73 *Grounding and Layout*: «Avoid running digital lines under the device …», «Avoid crossover of digital and analog signals», «Run traces on opposite sides of the board at right angles to each other» (técnica de 2 camadas: «the component side of the board is dedicated to ground planes»).
- TI **TPS2661x SLVSFE3C §11.1** (espírito): sinais sensíveis afastados da corrente de laço.

## 3. Tabela (avaliada por `tabela.py`, não escrita à mão)

| CI | fonte (§/tabela/nota, pág.) | fórmula | valores usados | resultado | veredito |
|---|---|---|---|---|---|
| D14 BAV199 / U6 AD7124-8 | AD7124-8 Rev F p.73: 'Avoid running digital lines under the device ... Avoid crossover of digital and analog signals' | `distancia minima cobre digital (SPI/CS/CLK/ISO) <-> no AIN1_ADC (pads e pistas, qualquer camada) >= 2 mm` | d_dig=4.040 nenhuma rede digital debaixo de D14; a mais perto e CS_ADC_ISO a 4,04 mm de U6.8 | d_dig = 4.040 | cumpre |
| D14 / U6 | AD7124-8 Rev F p.73: '... allows the analog ground plane to run under the AD7124-8 to prevent noise coupling' | `planos GND_ADC continuos debaixo de D14 (In1.Cu, In2.Cu) >= 1` | planos=2.000 | planos = 2.000 | cumpre |
| D14 / U6 | AD7124-8 Rev F p.73: 'Run traces on opposite sides of the board at right angles to each other' (tecnica de 2 camadas: 'component side ... ground planes') | `bus +3.3V_ANA em B.Cu (x=154,85) corre em planta sob pistas AIN1 de F.Cu: comprimento paralelo L; aceite se ha >= 1 plano GND entre as camadas` | L_par=4.530, planos=2.000 em 4 camadas os dois planos internos fazem o que a regra pede para 2 camadas | L_par = 4.530 ; planos = 2.000 | cumpre |
| D14 BAV199 | BAV199LT1/D Rev 12 p.2: IR <= 5,0 nA (VR=70 V, 25 C), <= 80 nA (TJ=150 C), por diodo | `corrente normal no bus +3.3V_ANA debaixo de D14 = so a fuga dos 7 BAV199 que alimenta: 7 x IR(150 C) <= 1 uA -> pista sem di/dt` | n=7.000, IR_150=8e-08 | n*IR_150*1e9 = 560.000 | cumpre |
| D14 BAV199 | BAV199LT1/D Rev 12 p.2: CD <= 2,0 pF (VR=0, 1 MHz) | `capacidade que o clamp acrescenta ao no AIN1 vs C27 do filtro: CD/C27 <= 0,1 %` | CD=2e-12, C27=1e-07 | CD/C27*100 = 0.002 | cumpre |
| AIN1_ADC (F.Cu) | criterio do projecto: cobre de outra rede na mesma camada a >= 0,30 mm do no analogico (DRC exige 0,15) | `distancia minima na mesma camada: +5V_ADC (rail DC) a d5, ao longo de L5 em paralelo` | d5=0.347, L5=8.500 rail DC; acoplamento ~0,1 pF contra 100 nF de C27: sem efeito; melhoravel, nao defeito | d5 = 0.347 ; L5 = 8.500 | cumpre |
| AIN1_ADC (F.Cu) | TPS2661x SLVSFE3C 11.1 (espirito): sinais sensiveis afastados da corrente de laco; criterio >= 2 mm na mesma camada | `distancia minima de redes de laco (AINx de campo, +24V_AINx, BRD, IEXC, Load_Cell) ao no AIN1_ADC` | d_loop=8.020 | d_loop = 8.020 | cumpre |
| D14 (housekeeping) | DRC track_dangling: toco AIN5_ADC_Load_Cell+ (157,85;87,0)-(157,35;86,5) dentro do courtyard de D14 | `tocos de outra rede dentro do courtyard de D14 == 0` | tocos=1.000 resto de roteamento (I3 do relatorio): apagar | tocos = 1.000 | **FALHA** |
| D14 BAV199 | BAV199LT1/D Rev 12: 6 paginas; nao tem seccao de layout (p.6 e texto legal) -> 'not in this PDF' | `requisitos de layout do fabricante do diodo: nenhum` | req=0 | req = 0 | cumpre |

cumpre: 8 · FALHA: 1 · falta dado: 0

## 4. Teste de uma multiplicação (acoplamento no nó AIN1)

- Bus B.Cu sob D14: corrente normal = fuga de 7 BAV199 ≤ 7 × 80 nA = **0,56 µA** (pior caso a 150 °C), DC → nenhum di/dt a acoplar. Em falta de campo o clamp conduz mA para +3.3V_ANA, mas aí o dano seria o próprio evento, não a pista.
- Dois planos GND_ADC (In1, In2) entre F.Cu e B.Cu: a capacidade F.Cu↔B.Cu através de dois planos é desprezável; a regra «right angles» do AD7124 é para 2 camadas e aqui está mais do que cumprida.
- +5V_ADC em F.Cu a 0,35 mm da pista AIN1 ao longo de ~8,5 mm: ≈ 0,1 pF de acoplamento contra os 100 nF de C27 (fc = 1/(2π·3k3·100n) = 482 Hz) → razão 1e-6. Rail DC. Sem efeito medível.

## 5. Veredito

**As pistas debaixo de D14 podem ficar.** O único item que falha é o toco solto de `AIN5_ADC_Load_Cell+` dentro do courtyard de D14, que é lixo de roteamento (I3 do relatório das 17:01) e se apaga.

## 6. O que nenhuma ferramenta viu

ERC/DRC não distinguem «pista debaixo de um clamp analógico» de qualquer outra pista; o DRC só mediria clearance na mesma camada. A pergunta só se responde lendo quem alimenta o bus (só clamps → sem corrente) e quantos planos há entre as camadas (dois) — nenhum analisador faz essa conta.

## 7. Limites desta verificação

Não se verificou a continuidade real dos enchimentos de In1/In2 sob D14 (usou-se o contorno das zonas, que cobre a caixa e não tem keepout nem zona de outra rede ali); não se mediu ruído. Mesma sessão que editou a placa hoje: repetir em sessão independente antes do portão.

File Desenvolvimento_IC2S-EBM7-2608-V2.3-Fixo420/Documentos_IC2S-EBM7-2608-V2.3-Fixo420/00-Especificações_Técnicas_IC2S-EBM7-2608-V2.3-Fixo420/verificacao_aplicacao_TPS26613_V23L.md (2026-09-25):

# Verificação de aplicação — TPS26613 (U8-U11) — EBM7 V2.3 legacy

**Data:** 21-09-2026 · **Placa:** `IC2S_Extension_Board_Model_7-EBM7-2608_V23L_Load_Cell_4AI.kicad_pcb`, gravada às **19:11:52** ·
**Datasheet:** `TI_TPS2661x.pdf` (SLVSFE3C, nov. 2020 rev. dez. 2021), citações por `grep` com página ·
**Procedimento:** `2shw-pcb:esquematico` etapa 2.3b / skill `verificar-aplicacao-datasheet` — tabela gerada por avaliação (`tabela.py`), não escrita à mão.

## Estado do roteamento no momento da leitura

549 segmentos (F.Cu 507 · B.Cu 42) · 83 vias · 71 ligações por fazer (eram 80) · DRC: 3 `clearance` · 4 `courtyards_overlap` · 2 `isolated_copper` · 0 `track_dangling` (eram 2) · 76 de serigrafia.
`VSNS`: 73,69 mm (F.Cu 50,27 · B.Cu 23,42), 4 vias; troço vertical em B.Cu em x = 161,300 de y 98,1 a 121,5.
Barreira do ISO7141: sem pistas nem vias no keepout.

## Tabela de verificação

| CI | fonte (§/tabela/nota, pág.) | fórmula | valores usados | resultado | veredito |
|---|---|---|---|---|---|
| TPS26613 U8-U11 | SLVSFE3C Tab. 8-2 nota (1), pág. 20 | `(R1 + R2) <= (+Vs) / 45 uA` | R1=1.15e+04, R2=3325, Vs=12.000 | R1+R2 = 1.482e+04 ; Vs/45e-6 = 2.667e+05 | cumpre |
| TPS26613 U8-U11 | SLVSFE3C Tab. 8-2 nota (2), pág. 20 | `V(SNSF) x (R1+R2)/R2 > I_LOOP x R_burden` | V_SNSF=1.000, R1=1.15e+04, R2=3325, I_LOOP=0.02, R_burden=110.000 R13-R17 = 110R na placa (era 409 herdado) | V_SNSF*(R1+R2)/R2 = 4.459 ; I_LOOP*R_burden = 2.200 | cumpre |
| TPS26613 U8-U11 | SLVSFE3C Tab. 8-2 linha '±Vs supplies', pág. 20 | `+Vs >= V(SNSR) x (R1+R2)/R2  (tem de conseguir sair do modo lazo)` | V_SNSR=1.720, R1=1.15e+04, R2=3325, Vs=12.000 | V_SNSR*(R1+R2)/R2 = 7.669 | cumpre |
| TPS26613 U8-U11 | SLVSFE3C §8.3.5.1, pág. 20 | `R1/R2 recomendados se I_LOOP x R_burden > 1,8 V  -> estao presentes (R22, R23||R24)` | I_LOOP=0.02, R_burden=110.000, presentes=1.000 | I_LOOP*R_burden = 2.200 | cumpre |
| TPS26613 U8-U11 | SLVSFE3C §7.3 Rec. Operating, pág. 4 | `+Vs <= 30 V` | Vs=12.000 +Vs vem do U12 regulado, nao dos 24 V crus (que chegam a 33) | Vs = 12.000 | cumpre |
| TPS26613 U8-U11 | SLVSFE3C §7.3 Rec. Operating, pág. 4 | `VSNS <= 5 V` | Vs=12.000, R1=1.15e+04, R2=3325 | Vs*R2/(R1+R2) = 2.691 | cumpre |
| TPS26613 U8-U11 | SLVSFE3C §7.3 Rec. Operating, pág. 4 | `IN, OUT dentro de -50..+50 V  (lazo a 24 V, TVS D1 a 33 V)` | V_max_lazo=33.000 | V_max_lazo = 33.000 | cumpre |
| TPS26613 U8-U11 | SLVSFE3C §7.1 Abs max, pág. 4 | `VSNS <= 5,5 V` | Vs=12.000, R1=1.15e+04, R2=3325 | Vs*R2/(R1+R2) = 2.691 | cumpre |
| TPS26613 U8-U11 | SLVSFE3C §7.5 IOL tip. 32 mA + Tab. 8-2 nota (2) | `em limite de corrente: I_OL x R_burden < V(SNSF) x (R1+R2)/R2  (nao cai em modo lazo na falta)` | I_OL=0.032, R_burden=110.000, V_SNSF=1.000, R1=1.15e+04, R2=3325 | I_OL*R_burden = 3.520 ; V_SNSF*(R1+R2)/R2 = 4.459 | cumpre |
| TPS26613 U8-U11 | SLVSFE3C §11.1 bullet 1, pág. 36 — 'add local bypass capacitors' (limite 3 mm = critério, TI nao da numero) | `distancia pino 6 (+Vs) ao 100 nF local <= 3 mm, nos 4 canais` | d_U8=2.490, d_U9=2.540, d_U10=2.520, d_U11=2.540 | max(d_U8,d_U9,d_U10,d_U11) = 2.540 | cumpre |
| TPS26613 U8-U11 | SLVSFE3C §11.1 bullet 2, pág. 36 — 'connect GND pin to GND of ±Vs supplies' | `pino 1 (GND) e pino 3 (-Vs) na mesma rede que a massa do +Vs (GND_ADC), nos 4` | ok_netlist=1.000 | ok_netlist = 1.000 | cumpre |
| TPS26613 U8-U11 | SLVSFE3C §11.1 bullet 3, pág. 36 — 'route both terminals of Rburden differentially to ADC (AINP, AINM)' | `entrada do ADC diferencial sobre R_burden` | diferencial=0 topologia unipolar (R13 a GND_ADC, so AINx_ADC vai ao U6) — decisao de projecto a documentar, nao e de roteamento | diferencial = 0 | **FALHA** |
| TPS26613 U8-U11 | SLVSFE3C §11.1 bullet 4, pág. 36 — 'keep EN/VSNS and SGOOD away from loop current' (2 mm fora do encapsulado = critério) | `distancia minima VSNS <-> redes de lazo na mesma capa, fora da saida de pino, >= 2 mm` | d_min_fora_pino=2.460, d_saida_pino_SOT23_8=1.300 1,30 mm e a distancia pino5-pino7 do SOT-23-8, geometria do encapsulado | d_min_fora_pino = 2.460 ; d_saida_pino_SOT23_8 = 1.300 | cumpre |
| TPS26613 U8-U11 | §11.1 bullet 4 aplicado ao troco novo de VSNS em B.Cu (23,4 mm sob a coluna de OUT em F.Cu) | `planos In1 e In2 (GND_ADC) continuos entre o troco de B.Cu e as pistas de lazo em F.Cu (so as antipads das 4 vias descobertas)` | pontos_cobertos=37.000, pontos_total=51.000, vias=4.000, pontos_por_via=3.500 | pontos_total - pontos_cobertos = 14.000 ; vias*pontos_por_via = 14.000 | cumpre |
| R13-R17 (carga) | critério de derating: I²R <= 50 % do nominal 0603 (0,1 W) | `I_LOOP² x R_burden <= 0,050 W` | I_LOOP=0.02, R_burden=110.000 | I_LOOP**2*R_burden = 0.044 | cumpre |
| AD7124-8 U6 <- lazo | AD7124-8 Rev F: fim de escala = V_REF (ADR4525 2,5 V), unipolar | `I_LOOP x R_burden <= V_REF a 20 mA; fim de escala em mA = V_REF / R_burden` | I_LOOP=0.02, R_burden=110.000, V_REF=2.500 | I_LOOP*R_burden = 2.200 ; V_REF/R_burden*1000 = 22.727 | cumpre |
| TPS26613 U8-U11 | SLVSFE3C Fig. 6-1, pág. 3 (renderizada) — pad 7 = VSNS no 26613; = EN no 26611/12/14 | `pad 7 dos 4 footprints na rede VSNS (pinfunction VSNS_7)` | ok_pinout=1.000 | ok_pinout = 1.000 | cumpre |
| TPS26613 U8-U11 | SLVSFE3C SGOOD (pad 8) — saida de diagnostico por canal | `SGOOD ligado ou decisao escrita de o deixar sem uso` | decisao_escrita=? os 4 SGOOD estao sem ligar; falta a nota de decisao na folha | missing: decisao_escrita | **falta dado** |

cumpre: 16 · FALHA: 1 · falta dado: 1

**Leitura:** 16 cumprem · 1 falha · 1 falta dado. A falha é de **topologia**, não de roteamento; o dado que falta é uma **nota de decisão**, não uma medida.

## Prova de uma multiplicação — cadeia de um canal (idêntica nos quatro)

```
P2.AINx ─► U8 IN ─► U8 OUT ─► R10 0R ─┬─► R13 110R ─► GND_ADC
                                       └─► FB4 ─► R18 3k3 ─► AINx_ADC ─► U6      (C27 100 nF, clamp D14)

  4 mA :  V(OUT) = 0,004 × 110 = 0,44 V      V(ADC) = 0,44 V   (17,6 % do fim de escala de 2,5 V)
 20 mA :  V(OUT) = 0,020 × 110 = 2,20 V      V(ADC) = 2,20 V   (88 %)
22,7 mA:  V(OUT) = 2,50 V = V_REF            fim de escala do ADC — permite ver o fallo NAMUR > 21 mA
32 mA (I_OL, em falta): V(OUT) = 3,52 V  <  4,46 V (umbral de modo lazo)  →  o TPS26613 não muda de modo durante uma falta
Margem ao transmissor a 20 mA: 24 − 0,15 (R_ON 7,5 Ω) − 2,20 − ~0,5 (fusível + díodo) ≈ 21 V
Antes (valores herdados 40k2 + 10k): 20 mA × 50,2 kΩ = 1 004 V — a entrada não podia funcionar em corrente.
```

## O que nenhuma ferramenta viu

- **ERC / DRC**: não lêem datasheets. Um divisor de 50,2 kΩ numa entrada de corrente é eléctricamente perfeito para ambos.
- **Analisador de esquemático (kicad-happy)**: reconhece padrões, não intenções. Viu `R10`/`R13` como divisor de tensão e deu-o por correcto.
- **SPICE (47/47)**: confirmou que o divisor dividia o que dizia dividir. Não pode saber se devia ser um divisor.
- **Revisor independente**: recebeu o checklist de pinagem e roteamento. Nenhum dos dois tinha a linha «fórmulas da secção de aplicação com os valores da BOM».
- **`kicad-cli`**: tolera uma cadeia partida em várias linhas que o editor gráfico rejeita — verificar como carrega o utilizador.

## O que continua a não cumprir, e porquê

1. **§11.1 bullet 3 — `RBurden` diferencial para `AINP`/`AINM`.** A topologia é unipolar: `R13` vai a `GND_ADC` e só `AINx_ADC` chega ao `U6`. É uma recomendação de exactidão (rejeição de ruído de massa), não um limite eléctrico. **Não se resolve no roteamento**: ou se aceita e se escreve como decisão na folha `06_lacos`, ou se muda o esquemático para ligar os dois terminais de `R13` a um par `AINP`/`AINM` do AD7124 (tem 16 entradas). Recomendação: escrever a decisão; a medida em 4-20 mA industrial tolera a perda.
2. **`SGOOD` (pad 8) sem ligar nos quatro.** Perde-se o diagnóstico por canal. Legítimo, mas falta a nota de decisão na folha.

## Limites desta revisão

- Cobre **um** dos seis CI críticos. Faltam AD7124-8, ISO7141, TPS7A4001, SPX3819 e R-78HB com o mesmo rigor.
- `V(SNSF)` = 1,00 V e `V(SNSR)` = 1,72 V são os valores da tabela da pág. 6 tal como extraídos; se essa linha tiver mín/máx que a extracção não captou, o limite de 223 Ω desloca-se ligeiramente. Não muda nenhum veredito com 110 Ω (margem 4,46 V contra 2,20 V).
- Os limites de 3 mm (bypass) e 2 mm (VSNS fora do encapsulado) são **critério do revisor**: a TI não dá número. Estão marcados como tal na tabela.
- O `+Vs` do TPS26613 assume-se 12,0 V; o valor real do `U12` (TPS7A4001 com 93k1/10k) não foi medido nesta revisão.

## Pendentes que saem desta tabela

- Nota de decisão na folha `06_lacos` sobre `SGOOD` sem uso e sobre a entrada unipolar do ADC.
- MPN dos quatro `110R` 0,1 % (`R13`, `R14`, `R15`, `R17`).
- Constante do firmware dos painéis: **9,09 mA/V** (2,20 V a 20 mA).
- `clearance` em (164,40 · 100,65): pista `AIN2` contra a ilha de `GND_ADC` do `U9` — roteamento.

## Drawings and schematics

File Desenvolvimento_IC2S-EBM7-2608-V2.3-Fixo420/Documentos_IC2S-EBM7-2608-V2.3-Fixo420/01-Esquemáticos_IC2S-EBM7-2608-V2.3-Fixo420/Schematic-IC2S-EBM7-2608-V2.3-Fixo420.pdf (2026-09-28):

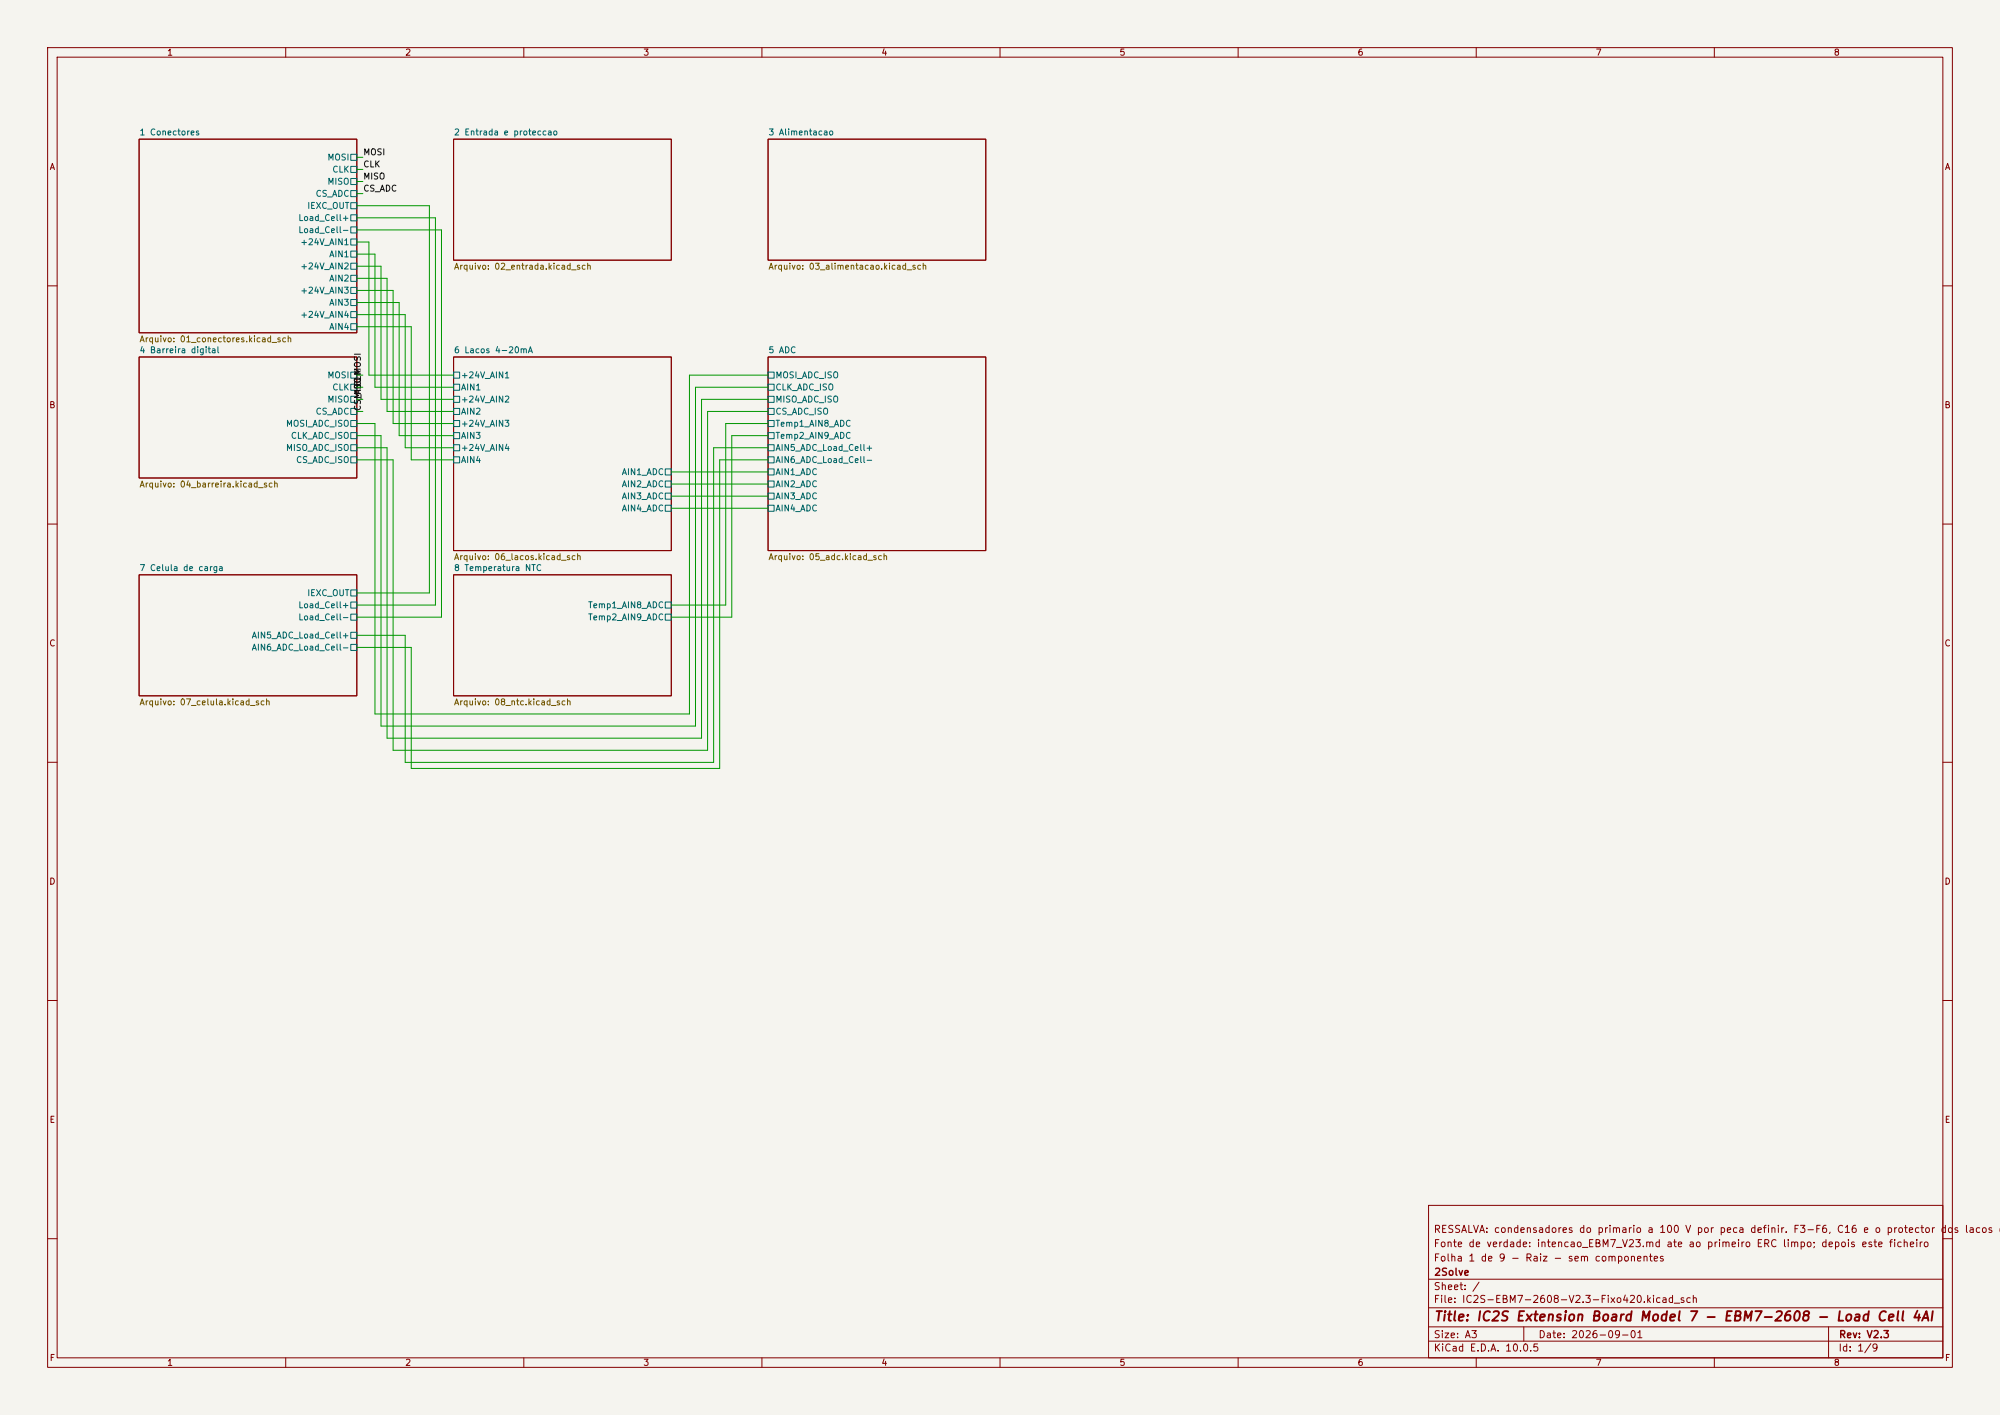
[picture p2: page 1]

Arquivo: 03_alimentacao.kicad_sch MOSI CLK MISO

Arquivo: 08_ntc.kicad_sch MOSI CLK MISO

RESSALVA: condensadores do primario a 100 V por peca definir. F3-F6, C16 e o protector dos lacos escolhidos (2026-09-03).
Fonte de verdade: intencao_EBM7_V23.md ate ao primeiro ERC limpo; depois este ficheiro
Folha 1 de 9 - Raiz - sem componentes
2Solve
Sheet: /
File: IC2S-EBM7-2608-V2.3-Fixo420.kicad_sch
Title: IC2S Extension Board Model 7 - EBM7-2608 - Load Cell 4AI

Size: A3 | Rev: V2.3 | F Date: 2026-09-01
KiCad E.D.A. 10.0.5 | Id: 1/9

1 | 2 | 3 | 4 | 5 | 6

AB

C

D

AB

C

### D Date: 2026-09-01

Size: A4 | Rev: V2.3

## Title: IC2S Extension Board Model 7 - EBM7-2608 - Load Cell 4AI

### File: 01_conectores.kicad_sch

### Sheet: /1 Conectores/

2Solve

### Folha 2 de 9 - 1 Conectores

### Fonte de verdade: intencao_EBM7_V23.md ate ao primeiro ERC limpo; depois este ficheiro

Fid2 | Fid3 | RESSALVA: condensadores do primario a 100 V por peca definir. F3-F6, C16 e o protector dos lacos escolhidos (2026-09-03). GND_ADC

GND_ADC

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
# 14 P2 M20-7821446 +24V DGND

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
20 P1 M20-7822046 +5V DGND

GND_ADC

DGND

Fid1 | +24V_AIN4 +24V_AIN3 AIN2

AIN1 +24V_AIN1

+24V_AIN2

AIN4

CLK

# AIN3 CS_ADC

IEXC_OUT Load_Cell+

Load_Cell-

MISO MOSI LDAC_DAC

# CS_DAC USB1 USB2

SCL

# ID3 CS4

ID1

SDA | 6. Fiduciais sem pino electrico: as redes unconnected-(FidX) 5. P2 = M20-7821446 (campo): IEXC e celula > folha 7; da V2.2 desaparecem do diff de netlist. a espera dessas folhas (aviso de ERC temporario esperado). lacos 4-20 mA > folha 6. Os pinos de hoja na raiz ficam
2. P1-20 leva 116 mA em regime (4 lacos a 24 mA, 2 LED, U3) e passiva real e a base board via P1. Fecha os 4 pendentes 3. PWR_FLAG de +24V, GND_ADC (P1.19), +5V e DGND nesta folha: a fonte Barramento da base board. Sinais nao usados nesta placa: 1. P1 = M20-7822046 (Harwin, FILA UNICA de 20 - nao 2x10). DECISOES DESTA FOLHA (F2 2.2b) ~180 mA em falha: 6% dos 3 A/contacto (Harwin M20), margem 16x. USB1/2, CS_DAC, LDAC_DAC, CS4, ID1, ID3, SDA, SCL -
de ERC das folhas 2 e 3. terminam aqui por desenho da familia de extensoes. +5V | 4. P1-18 e P2-1 sem ligacao (tambem na V2.2). DGND +24V | GND_ADC

AB

C

D

AB

C

### D Date: 2026-09-01

## Title: IC2S Extension Board Model 7 - EBM7-2608 - Load Cell 4AI

### File: 02_entrada.kicad_sch

### Sheet: /2 Entrada e proteccao/

2Solve

### Folha 3 de 9 - 2 Entrada e proteccao

### Fonte de verdade: intencao_EBM7_V23.md ate ao primeiro ERC limpo; depois este ficheiro

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

GND_ADC

GND_ADC

F1 CC12H750MA-TR

C1
10uF/100V

+24V_ADC

D1

SMA6J33A-Q

T1
TP_+24V | D2 MBR1H100SF +24V

T2
TP_GND_ADC_P1 GND_ADC
1. F1 = CC12H750MA-TR (Eaton, time-lag). I2t de fusao 150 mA2s, 2. F2 REMOVIDO 28-09-2026 (nota 13): ramo unico, F1 alimenta a placa toda. DECISOES DESTA FOLHA (F2 2.2b - fonte: intencao_EBM7_V23.md) Murata cat. 2021 p.110). Com o U1 = R-78HB, o C1 e a 12. C1 = GRM32EC72A106KE05 (1210 X7S 10 uF 100 V, C1 retorna a GND_ADC = GND do U1. (C13 e hoje o bypass | do U5.) de GND_ADC (era GND_24V). Escolha do projectista 2026-09-04. entrada junto ao Vin (PCB 28-09: 2,9 mm do pino 1); massa
Arranque ~30 uF: ~5 mA2s (escala da nota 10) contra 150 mA2s do CC12H750MA, ~29x de margem. 116 mA em regime, ~180 mA em falha (folha 1, nota 2): o U1 (R-78HB) e o +24V_ADC; +24V_REG deixa de existir. | ERC pendente estrutural: +24V e GND_ADC (P1.19) sem driver ate existir a 13. RAMO UNICO DE 24 V (reuniao da equipa, 2026-09-28): F1 750 mA e D2 MBR1H100SF 1 A chegam. saem F2, D3 e C2. Tudo vem dos mesmos 24 V: nao eram
5. Diodos: pino 1 = CATODO (convencao KiCad = Nexperia). MLCC de 50 V - mecanismo A. Peca exata por escolher. 4. C1 = 10 uF a 100 V: o clamp de 53,3 V fica acima de clamp REAL 53,3 V @ 11,3 A (nao 40,6 - erro da biblioteca). 8. Trilhos como power ports globais; +24V_REG substitui Net-(D5-K). canais independentes nem isolados. F1 + D2 alimentam
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

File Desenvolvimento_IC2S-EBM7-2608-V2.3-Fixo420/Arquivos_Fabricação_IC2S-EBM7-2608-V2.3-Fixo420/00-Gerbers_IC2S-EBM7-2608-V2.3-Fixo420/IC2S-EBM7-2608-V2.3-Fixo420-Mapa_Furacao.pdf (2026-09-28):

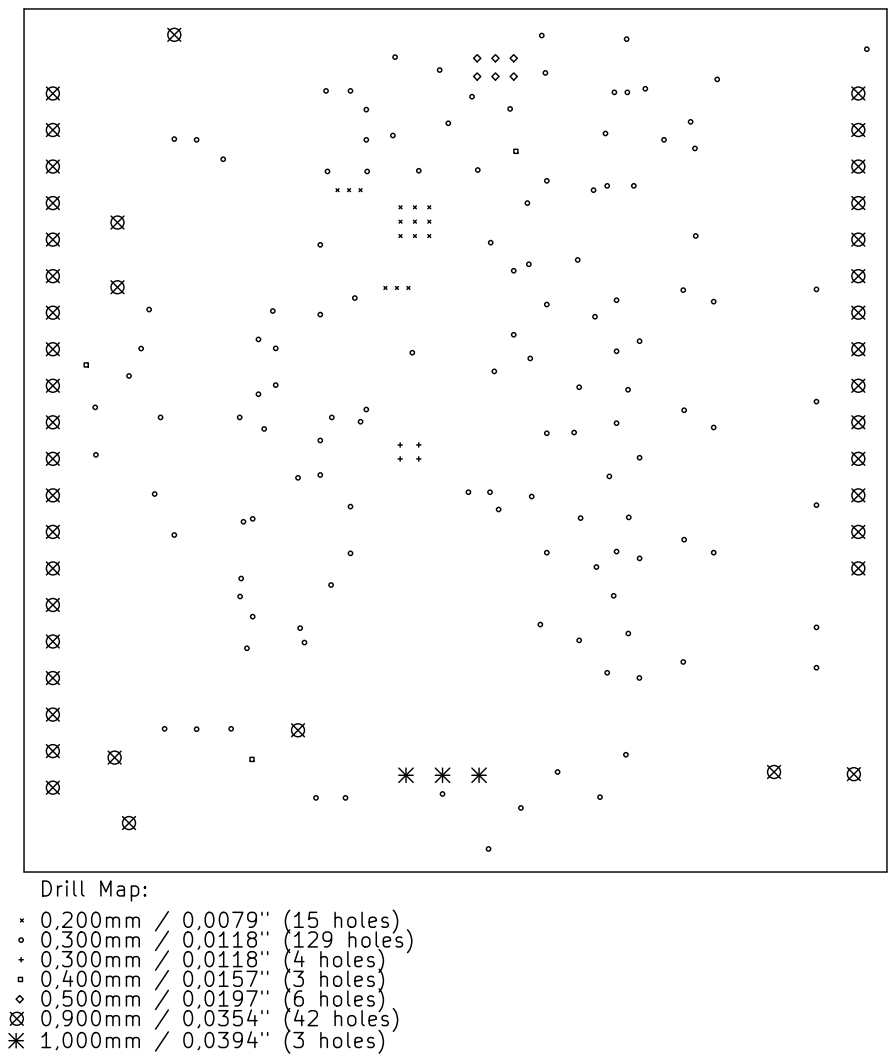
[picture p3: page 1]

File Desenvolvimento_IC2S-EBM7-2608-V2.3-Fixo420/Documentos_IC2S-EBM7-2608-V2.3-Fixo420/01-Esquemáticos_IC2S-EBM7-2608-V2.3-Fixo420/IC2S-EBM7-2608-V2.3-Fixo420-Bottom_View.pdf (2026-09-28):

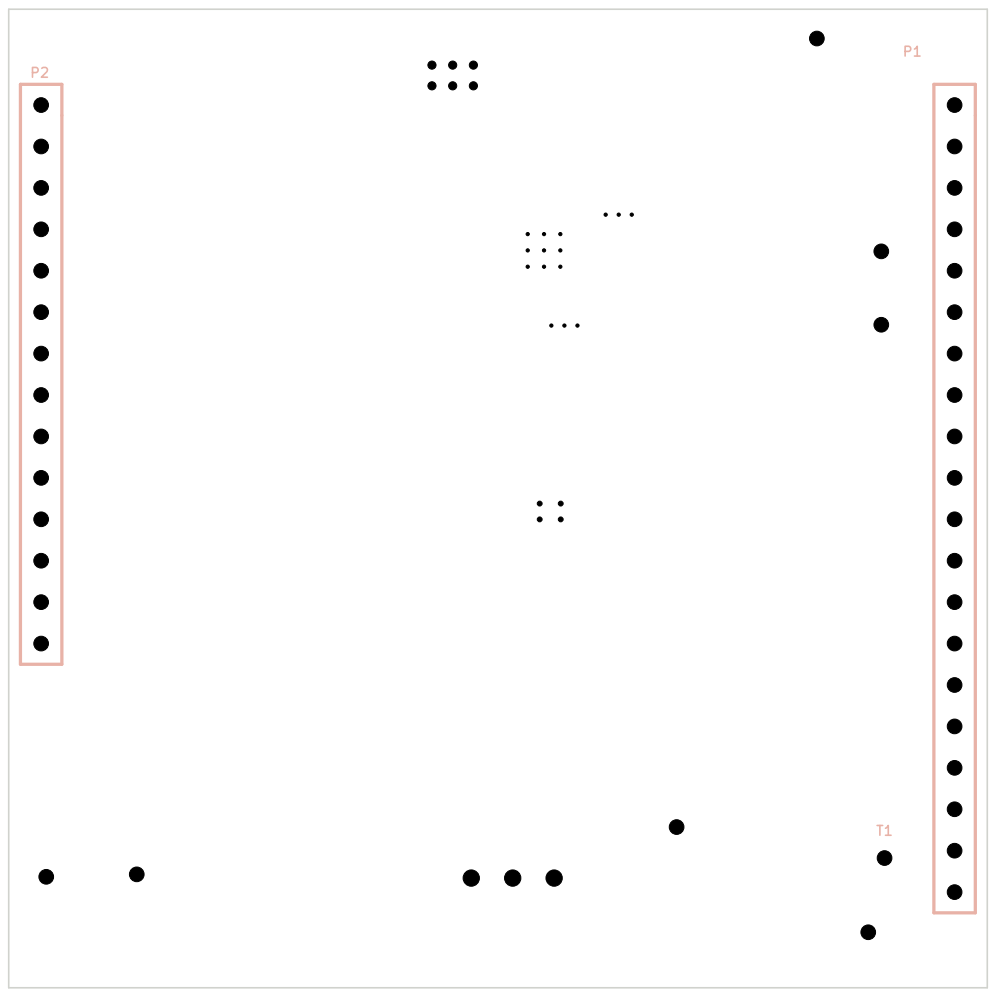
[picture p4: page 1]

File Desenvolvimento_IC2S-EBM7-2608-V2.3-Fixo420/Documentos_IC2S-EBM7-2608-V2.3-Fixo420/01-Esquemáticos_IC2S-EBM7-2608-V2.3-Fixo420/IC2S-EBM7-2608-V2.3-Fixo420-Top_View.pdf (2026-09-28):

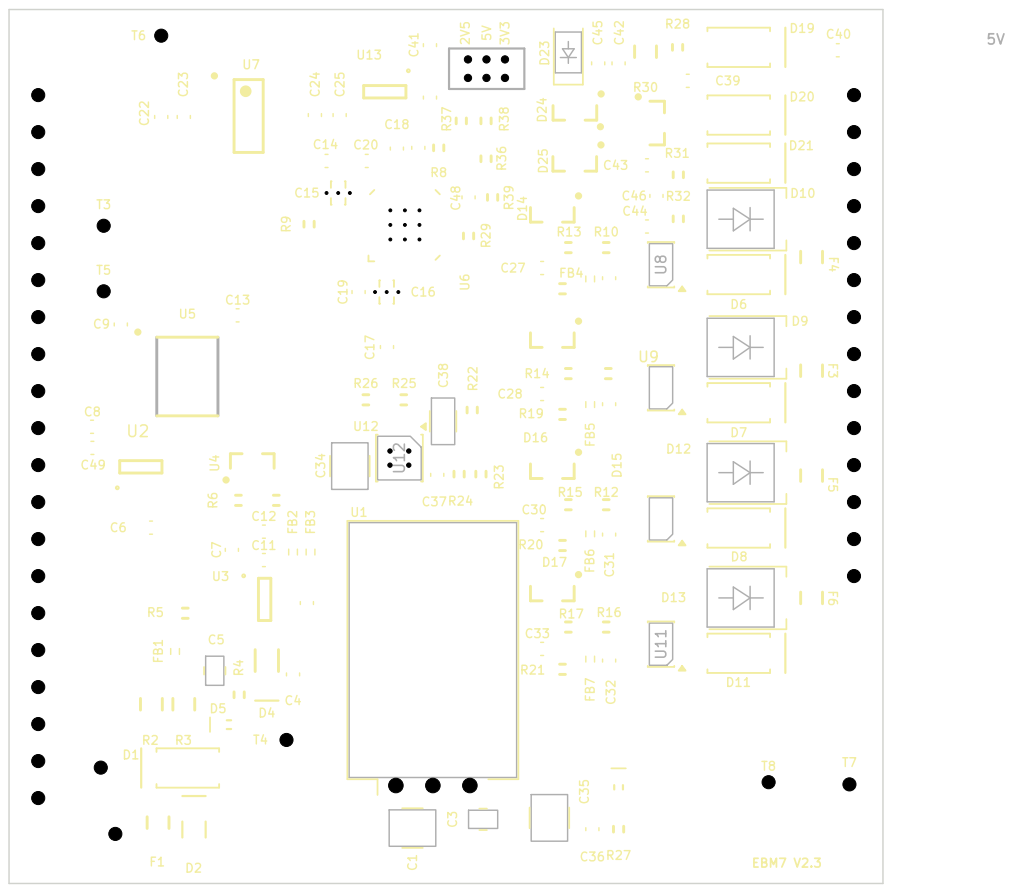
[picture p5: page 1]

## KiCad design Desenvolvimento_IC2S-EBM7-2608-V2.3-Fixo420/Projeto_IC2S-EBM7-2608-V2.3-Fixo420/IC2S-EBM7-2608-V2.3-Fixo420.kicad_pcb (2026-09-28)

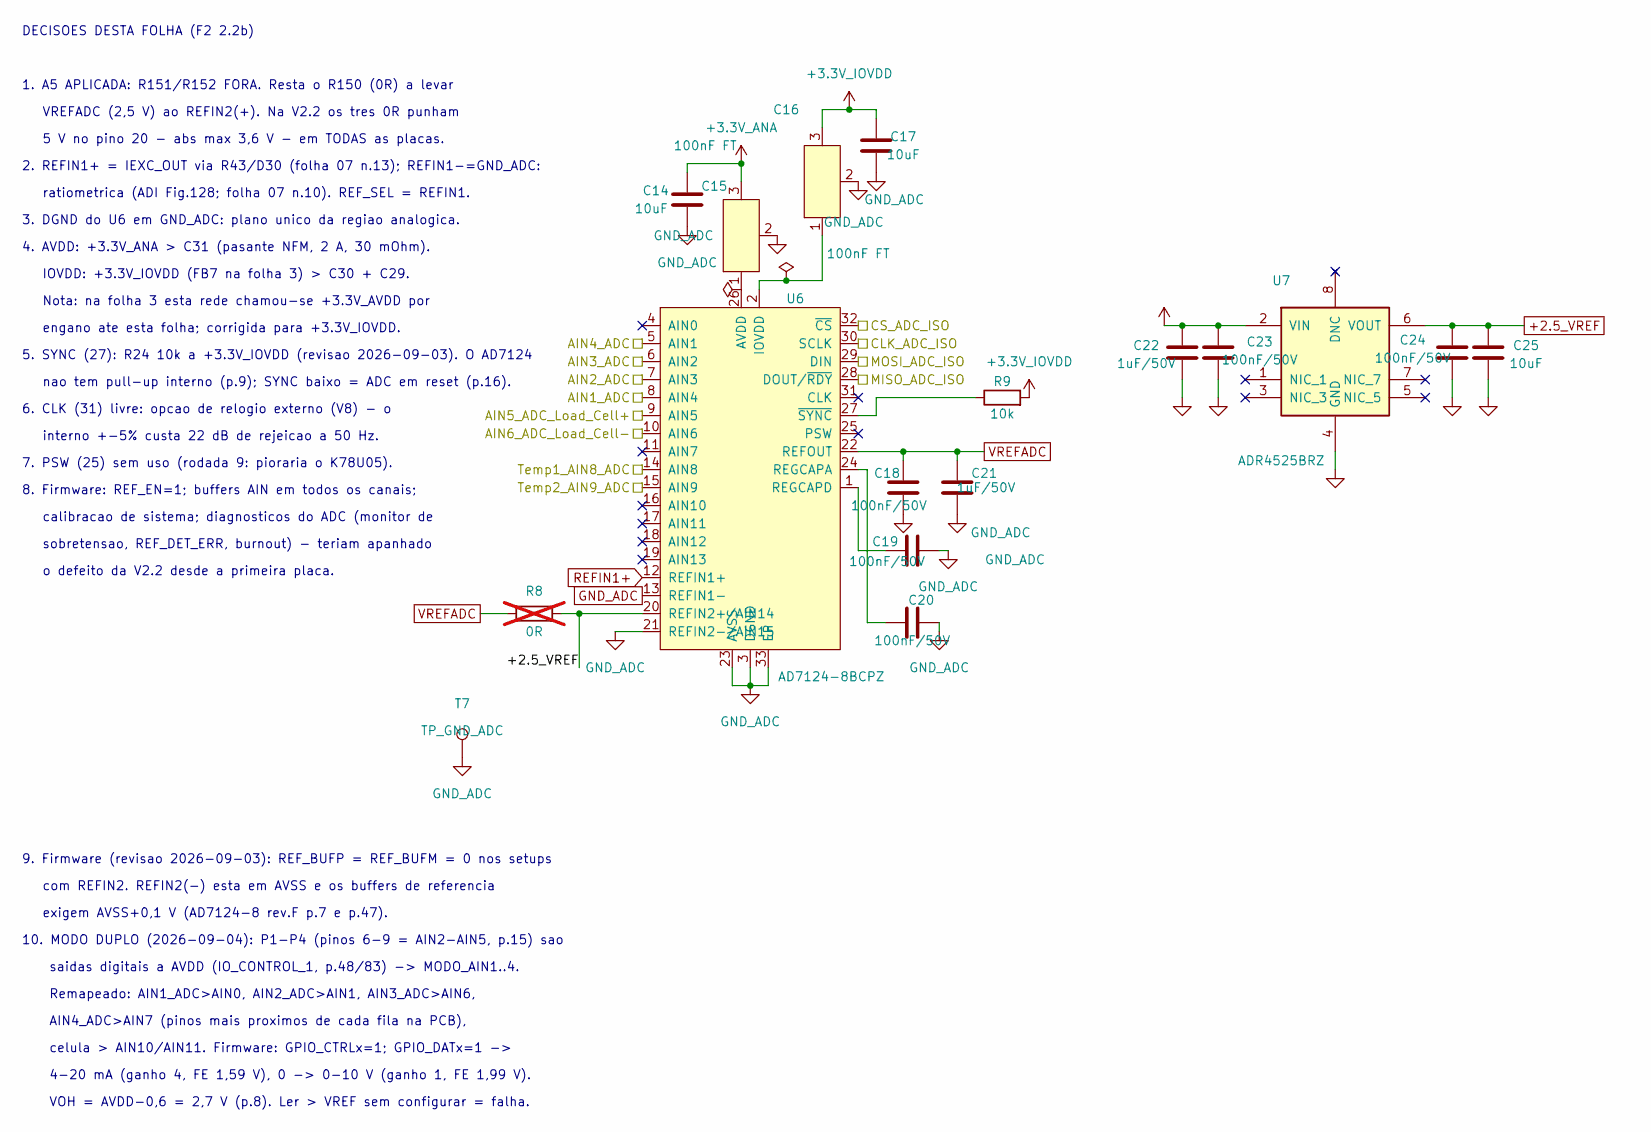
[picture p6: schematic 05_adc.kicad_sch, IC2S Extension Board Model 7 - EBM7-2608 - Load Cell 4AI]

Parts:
C14, C17, C25: 10uF; 0603C; MPN 0603YD106KAT2A
C15, C16: 100nF FT; NFM0603; MPN NFM18PC104R1C3D
C18, C19, C20, C23, C24: 100nF/50V; 0603C; MPN C1608X7R1H104K080AA
C21, C22: 1uF/50V; 0603C; MPN C1608X7R1H105K080AB
R8: 0R; 0603R; MPN RC0603JR-070RL; not fitted
R9: 10k; 0603R; MPN RC0603FR-0710KL
T7: TP_GND_ADC; TestPad_Via
U6: AD7124-8BCPZ; LFCSP-32-2; MPN AD7124-8BCPZ
U7: ADR4525BRZ; SOIC8; MPN ADR4525BRZ

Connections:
+2.5_VREF: C24.1, C25.1, R8.2, U6.20 (REFIN2+/AIN14), U7.6 (VOUT)
+3.3V_ANA: C14.2, C15.3 (OUT), C22.1, C23.1, U7.2 (VIN); also elsewhere on the board
+3.3V_IOVDD: C16.3 (OUT), C17.2, R9.2; also elsewhere on the board
/4 Barreira digital/CLK_ADC_ISO: U6.30 (SCLK); also elsewhere on the board
/4 Barreira digital/CS_ADC_ISO: U6.32 (~CS); also elsewhere on the board
/4 Barreira digital/MISO_ADC_ISO: U6.28 (DOUT/~RDY); also elsewhere on the board
/4 Barreira digital/MOSI_ADC_ISO: U6.29 (DIN); also elsewhere on the board
/5 ADC/AIN1_ADC: U6.8 (AIN4); also elsewhere on the board
/5 ADC/AIN2_ADC: U6.7 (AIN3); also elsewhere on the board
/5 ADC/AIN3_ADC: U6.6 (AIN2); also elsewhere on the board
/5 ADC/AIN4_ADC: U6.5 (AIN1); also elsewhere on the board
/5 ADC/AIN5_ADC_Load_Cell+: U6.9 (AIN5); also elsewhere on the board
/5 ADC/AIN6_ADC_Load_Cell-: U6.10 (AIN6); also elsewhere on the board
/5 ADC/Temp1_AIN8_ADC: U6.14 (AIN8); also elsewhere on the board
/5 ADC/Temp2_AIN9_ADC: U6.15 (AIN9); also elsewhere on the board
GND_ADC: C14.1, C15.2 (GND), C16.2 (GND), C17.1, C18.1, C19.1, C20.1, C21.2, C22.2, C23.2, C24.2, C25.2, T7.1 (1_1), U6.3 (DGND), U6.13 (REFIN1-), U6.21 (REFIN2-/AIN15), U6.23 (AVSS), U6.33 (EP), U7.4 (GND); also elsewhere on the board
unnamed: C15.1 (IN), U6.26 (AVDD)
unnamed: C16.1 (IN), U6.2 (IOVDD)
unnamed: C20.2, U6.24 (REGCAPA)
unnamed: C19.2, U6.1 (REGCAPD)
unnamed: R9.1, U6.27 (~SYNC)
REFIN1+: U6.12 (REFIN1+); also elsewhere on the board
VREFADC: C18.2, C21.1, R8.1, U6.22 (REFOUT); also elsewhere on the board

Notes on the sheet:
celula > AIN10/AIN11. Firmware: GPIO_CTRLx=1; GPIO_DATx=1 ->
ratiometrica (ADI Fig.128; folha 07 n.10). REF_SEL = REFIN1.
4. AVDD: +3.3V_ANA > C31 (pasante NFM, 2 A, 30 mOhm).
engano ate esta folha; corrigida para +3.3V_IOVDD.
Nota: na folha 3 esta rede chamou-se +3.3V_AVDD por
com REFIN2. REFIN2(-) esta em AVSS e os buffers de referencia
1. A5 APLICADA: R151/R152 FORA. Resta o R150 (0R) a levar
Remapeado: AIN1_ADC>AIN0, AIN2_ADC>AIN1, AIN3_ADC>AIN6,
calibracao de sistema; diagnosticos do ADC (monitor de
sobretensao, REF_DET_ERR, burnout) - teriam apanhado
saidas digitais a AVDD (IO_CONTROL_1, p.48/83) -> MODO_AIN1..4.
AIN4_ADC>AIN7 (pinos mais proximos de cada fila na PCB),
2. REFIN1+ = IEXC_OUT via R43/D30 (folha 07 n.13); REFIN1-=GND_ADC:
interno +-5% custa 22 dB de rejeicao a 50 Hz.
VREFADC (2,5 V) ao REFIN2(+). Na V2.2 os tres 0R punham
DECISOES DESTA FOLHA (F2 2.2b)
3. DGND do U6 em GND_ADC: plano unico da regiao analogica.
6. CLK (31) livre: opcao de relogio externo (V8) - o
10. MODO DUPLO (2026-09-04): P1-P4 (pinos 6-9 = AIN2-AIN5, p.15) sao
IOVDD: +3.3V_IOVDD (FB7 na folha 3) > C30 + C29.
o defeito da V2.2 desde a primeira placa.
nao tem pull-up interno (p.9); SYNC baixo = ADC em reset (p.16).
5. SYNC (27): R24 10k a +3.3V_IOVDD (revisao 2026-09-03). O AD7124
8. Firmware: REF_EN=1; buffers AIN em todos os canais;
VOH = AVDD-0,6 = 2,7 V (p.8). Ler > VREF sem configurar = falha.
7. PSW (25) sem uso (rodada 9: pioraria o K78U05).
5 V no pino 20 - abs max 3,6 V - em TODAS as placas.
exigem AVSS+0,1 V (AD7124-8 rev.F p.7 e p.47).
4-20 mA (ganho 4, FE 1,59 V), 0 -> 0-10 V (ganho 1, FE 1,99 V).
9. Firmware (revisao 2026-09-03): REF_BUFP = REF_BUFM = 0 nos setups

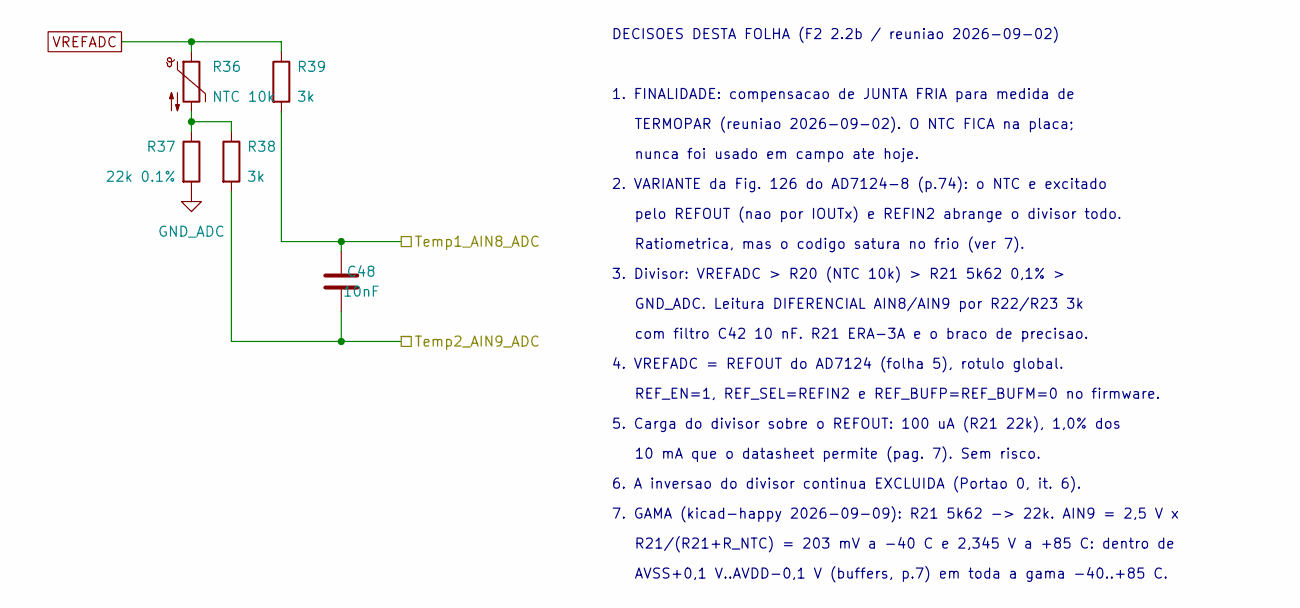
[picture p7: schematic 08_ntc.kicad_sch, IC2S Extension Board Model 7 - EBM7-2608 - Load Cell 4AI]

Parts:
C48: 10nF; 0603C; MPN GCM188R71H103KA37J
R36: NTC 10k; 0603R; MPN NTCS0603E3103JLT
R37: 22k 0.1%; 0603R; MPN RG1608P-223-B-T5
R38, R39: 3k; 0603R; MPN RC0603FR-073KL

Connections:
/5 ADC/Temp1_AIN8_ADC: C48.2, R39.2; also elsewhere on the board
/5 ADC/Temp2_AIN9_ADC: C48.1, R38.2; also elsewhere on the board
GND_ADC: R37.2; also elsewhere on the board
unnamed: R36.2, R37.1, R38.1
VREFADC: R36.1, R39.1; also elsewhere on the board

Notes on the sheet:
GND_ADC. Leitura DIFERENCIAL AIN8/AIN9 por R22/R23 3k
pelo REFOUT (nao por IOUTx) e REFIN2 abrange o divisor todo.
5. Carga do divisor sobre o REFOUT: 100 uA (R21 22k), 1,0% dos
Ratiometrica, mas o codigo satura no frio (ver 7).
4. VREFADC = REFOUT do AD7124 (folha 5), rotulo global.
nunca foi usado em campo ate hoje.
R21/(R21+R_NTC) = 203 mV a -40 C e 2,345 V a +85 C: dentro de
1. FINALIDADE: compensacao de JUNTA FRIA para medida de
2. VARIANTE da Fig. 126 do AD7124-8 (p.74): o NTC e excitado
REF_EN=1, REF_SEL=REFIN2 e REF_BUFP=REF_BUFM=0 no firmware.
10 mA que o datasheet permite (pag. 7). Sem risco.
3. Divisor: VREFADC > R20 (NTC 10k) > R21 5k62 0,1% >
DECISOES DESTA FOLHA (F2 2.2b / reuniao 2026-09-02)
6. A inversao do divisor continua EXCLUIDA (Portao 0, it. 6).
com filtro C42 10 nF. R21 ERA-3A e o braco de precisao.
TERMOPAR (reuniao 2026-09-02). O NTC FICA na placa;
7. GAMA (kicad-happy 2026-09-09): R21 5k62 -> 22k. AIN9 = 2,5 V x
AVSS+0,1 V..AVDD-0,1 V (buffers, p.7) em toda a gama -40..+85 C.

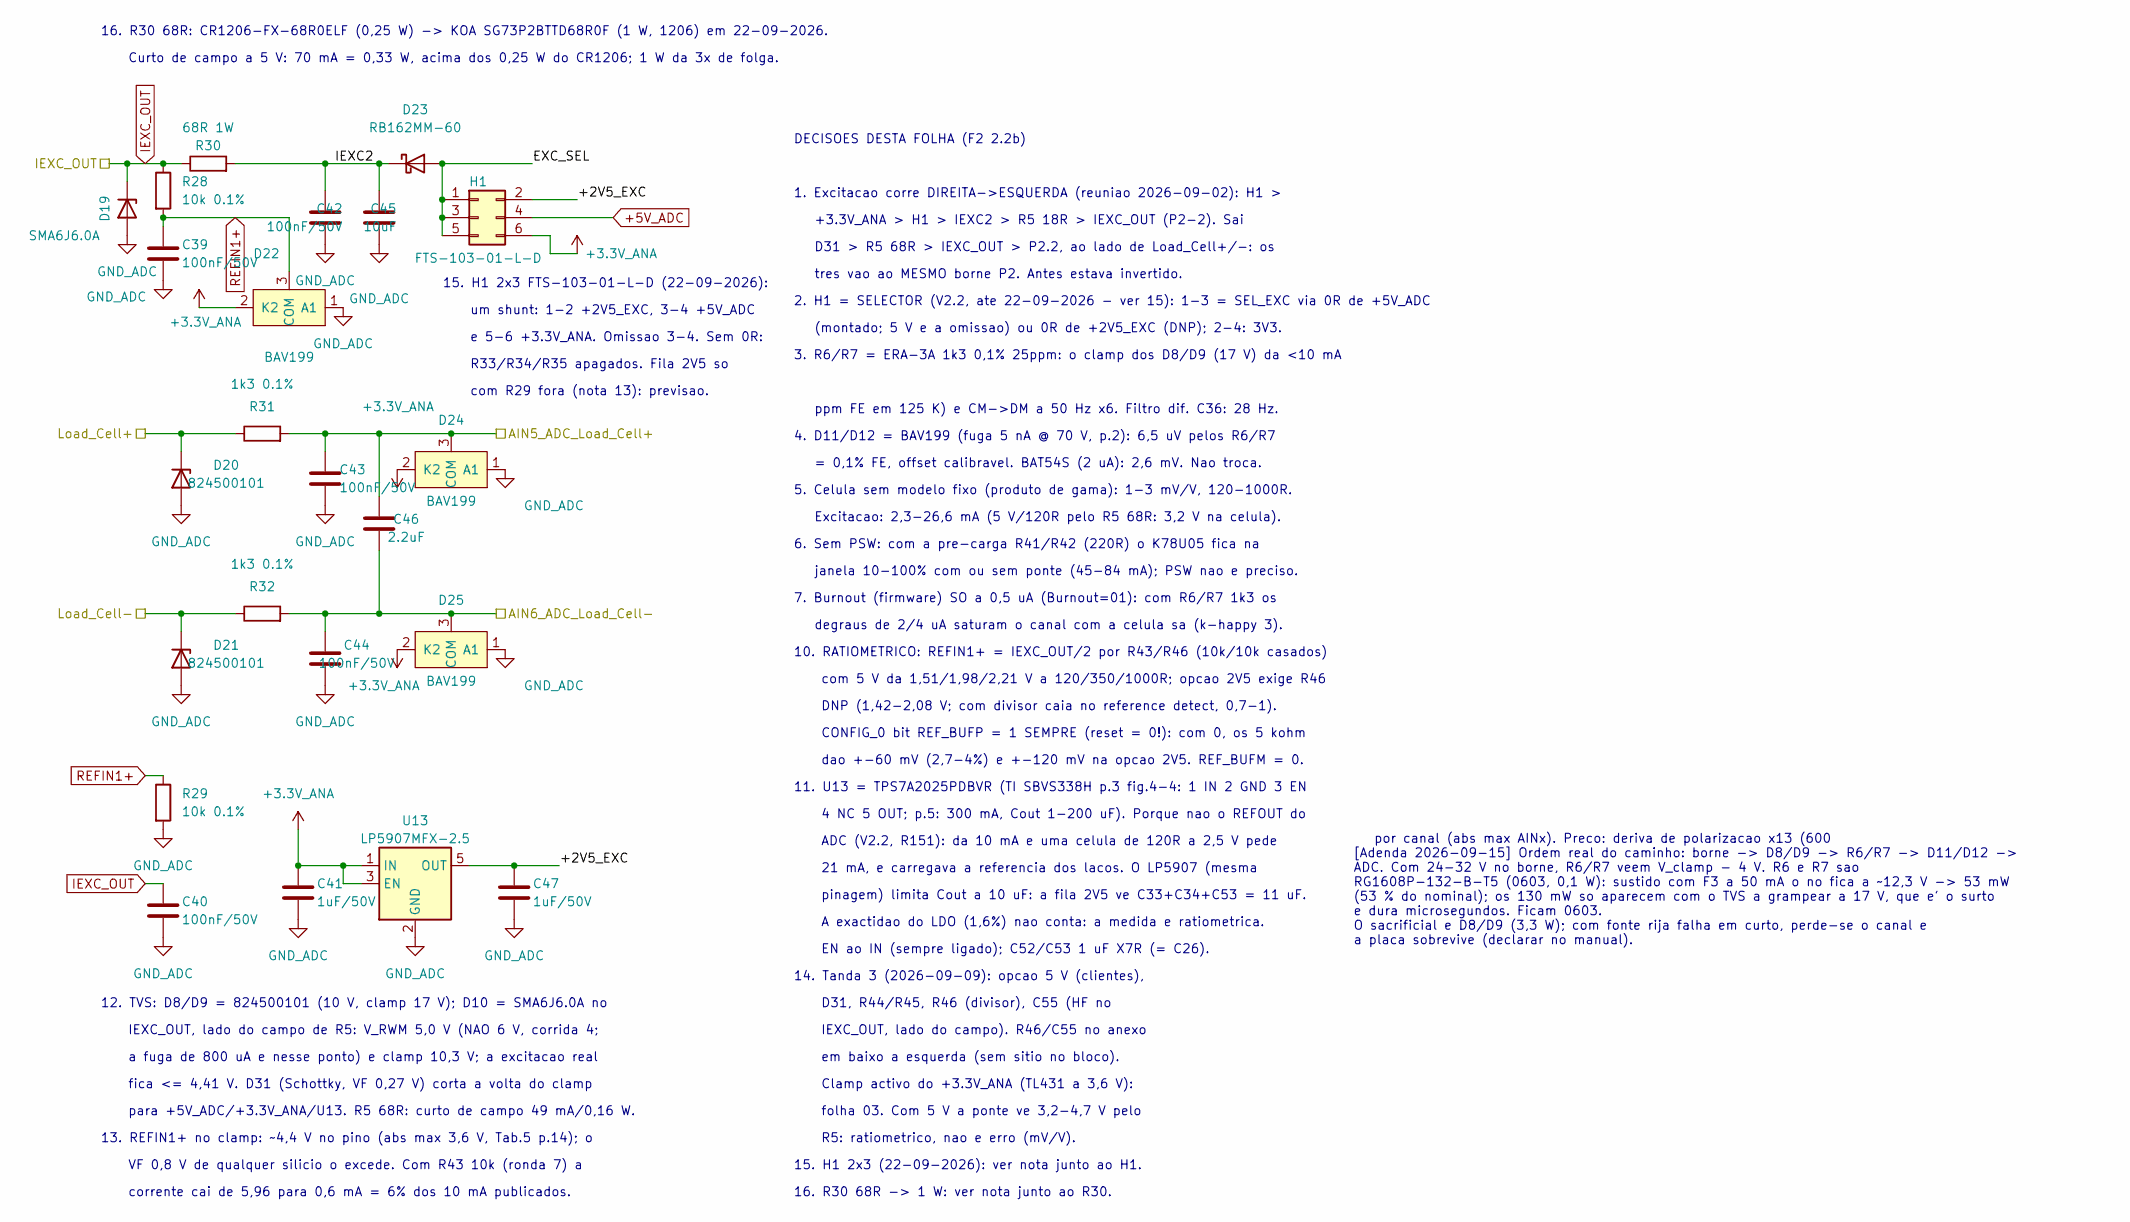
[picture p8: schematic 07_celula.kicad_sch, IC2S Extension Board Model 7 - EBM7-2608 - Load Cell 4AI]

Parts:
C39, C40, C42, C43, C44: 100nF/50V; 0603C; MPN C1608X7R1H104K080AA
C41, C47: 1uF/50V; 0603C; MPN C1608X7R1H105K080AB
C45: 10uF; 0603C; MPN 0603YD106KAT2A
C46: 2.2uF; 0603C; MPN C1608X5R1E225K080AB
D19: SMA6J6.0A; DO-214; MPN SMA6J6.0A
D20, D21: 824500101; DO-214; MPN 824500101
D22, D24, D25: BAV199; SOT23-3; MPN BAV199LT1G
D23: RB162MM-60; SOD-123F; MPN RB162MM-60TR
H1: FTS-103-01-L-D; HDR2X3_1.27mm-Without_number; MPN FTS-103-01-L-D
R28, R29: 10k 0.1%; 0603R; MPN RG1608P-103-B-T5
R30: 68R 1W; 1206R; MPN SG73P2BTTD68R0F
R31, R32: 1k3 0.1%; 0603R; MPN RG1608P-132-B-T5
U13: LP5907MFX-2.5; SOT-23-5; MPN LP5907MFX-2.5/NOPB

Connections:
+3.3V_ANA: C41.1, D22.2 (K2), D24.2 (K2), D25.2 (K2), H1.6, U13.1 (IN), U13.3 (EN); also elsewhere on the board
+5V_ADC: H1.4; also elsewhere on the board
/1 Conectores/Load_Cell+: D20.1 (K), R31.1; also elsewhere on the board
/1 Conectores/Load_Cell-: D21.1 (K), R32.1; also elsewhere on the board
/5 ADC/AIN5_ADC_Load_Cell+: C43.1, C46.2, D24.3 (COM), R31.2; also elsewhere on the board
/5 ADC/AIN6_ADC_Load_Cell-: C44.2, C46.1, D25.3 (COM), R32.2; also elsewhere on the board
/7 Celula de carga/+2V5_EXC: C47.1, H1.2, U13.5 (OUT)
/7 Celula de carga/EXC_SEL: D23.2 (A), H1.1, H1.3, H1.5
/7 Celula de carga/IEXC2: C42.2, C45.2, D23.1 (K), R30.2
GND_ADC: C39.2, C40.2, C41.2, C42.1, C43.2, C44.1, C45.1, C47.2, D19.2 (A), D20.2 (A), D21.2 (A), D22.1 (A1), D24.1 (A1), D25.1 (A1), R29.2, U13.2 (GND); also elsewhere on the board
IEXC_OUT: C40.1, D19.1 (K), R28.1, R30.1; also elsewhere on the board
REFIN1+: C39.1, D22.3 (COM), R28.2, R29.1; also elsewhere on the board

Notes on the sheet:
ADC (V2.2, R151): da 10 mA e uma celula de 120R a 2,5 V pede
14. Tanda 3 (2026-09-09): opcao 5 V (clientes),
folha 03. Com 5 V a ponte ve 3,2-4,7 V pelo
12. TVS: D8/D9 = 824500101 (10 V, clamp 17 V); D10 = SMA6J6.0A no
IEXC_OUT, lado do campo). R46/C55 no anexo
fica <= 4,41 V. D31 (Schottky, VF 0,27 V) corta a volta do clamp
dao +-60 mV (2,7-4%) e +-120 mV na opcao 2V5. REF_BUFM = 0.
a fuga de 800 uA e nesse ponto) e clamp 10,3 V; a excitacao real
Clamp activo do +3.3V_ANA (TL431 a 3,6 V):
15. H1 2x3 (22-09-2026): ver nota junto ao H1.
EN ao IN (sempre ligado); C52/C53 1 uF X7R (= C26).
13. REFIN1+ no clamp: ~4,4 V no pino (abs max 3,6 V, Tab.5 p.14); o
com 5 V da 1,51/1,98/2,21 V a 120/350/1000R; opcao 2V5 exige R46
corrente cai de 5,96 para 0,6 mA = 6% dos 10 mA publicados.
5. Celula sem modelo fixo (produto de gama): 1-3 mV/V, 120-1000R.
16. R30 68R: CR1206-FX-68R0ELF (0,25 W) -> KOA SG73P2BTTD68R0F (1 W, 1206) em 22-09-2026.
4. D11/D12 = BAV199 (fuga 5 nA @ 70 V, p.2): 6,5 uV pelos R6/R7
7. Burnout (firmware) SO a 0,5 uA (Burnout=01): com R6/R7 1k3 os
Curto de campo a 5 V: 70 mA = 0,33 W, acima dos 0,25 W do CR1206; 1 W da 3x de folga.
VF 0,8 V de qualquer silicio o excede. Com R43 10k (ronda 7) a
A exactidao do LDO (1,6%) nao conta: a medida e ratiometrica.
4 NC 5 OUT; p.5: 300 mA, Cout 1-200 uF). Porque nao o REFOUT do
3. R6/R7 = ERA-3A 1k3 0,1% 25ppm: o clamp dos D8/D9 (17 V) da <10 mA
16. R30 68R -> 1 W: ver nota junto ao R30.
em baixo a esquerda (sem sitio no bloco).
2. H1 = SELECTOR (V2.2, ate 22-09-2026 - ver 15): 1-3 = SEL_EXC via 0R de +5V_ADC
um shunt: 1-2 +2V5_EXC, 3-4 +5V_ADC
degraus de 2/4 uA saturam o canal com a celula sa (k-happy 3).
CONFIG_0 bit REF_BUFP = 1 SEMPRE (reset = 0!): com 0, os 5 kohm
Excitacao: 2,3-26,6 mA (5 V/120R pelo R5 68R: 3,2 V na celula).
para +5V_ADC/+3.3V_ANA/U13. R5 68R: curto de campo 49 mA/0,16 W.
IEXC_OUT, lado do campo de R5: V_RWM 5,0 V (NAO 6 V, corrida 4;
R5: ratiometrico, nao e erro (mV/V).
1. Excitacao corre DIREITA->ESQUERDA (reuniao 2026-09-02): H1 >
D31 > R5 68R > IEXC_OUT > P2.2, ao lado de Load_Cell+/-: os
R33/R34/R35 apagados. Fila 2V5 so
DNP (1,42-2,08 V; com divisor caia no reference detect, 0,7-1).
+3.3V_ANA > H1 > IEXC2 > R5 18R > IEXC_OUT (P2-2). Sai
ppm FE em 125 K) e CM->DM a 50 Hz x6. Filtro dif. C36: 28 Hz.
por canal (abs max AINx). Preco: deriva de polarizacao x13 (600 [Adenda 2026-09-15] Ordem real do caminho: borne -> D8/D9 -> R6/R7 -> D11/D12 -> ADC. Com 24-32 V no borne, R6/R7 veem V_clamp - 4 V. R6 e R7 sao RG1608P-132-B-T5 (0603, 0,1 W): sustido com F3 a 50 mA o no fica a ~12,3 V -> 53 mW (53 %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

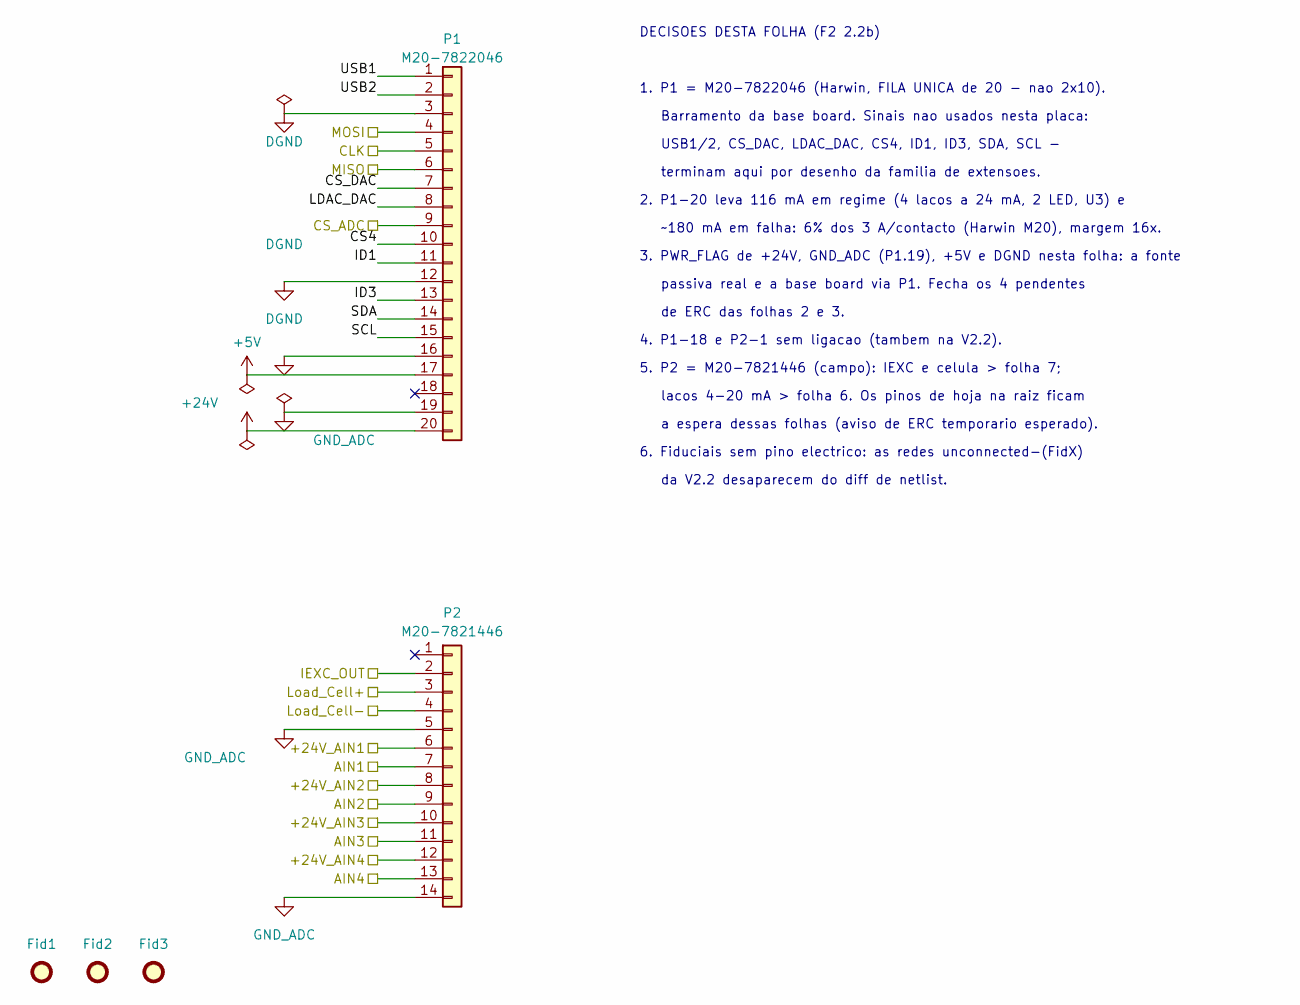
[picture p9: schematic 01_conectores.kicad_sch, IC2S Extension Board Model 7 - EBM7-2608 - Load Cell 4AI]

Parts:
Fid1, Fid2, Fid3: Fiducial; Fiducial_Point_Top-Bot
P1: M20-7822046; HDR1X20_FEMALE; MPN M20-7822046
P2: M20-7821446; HDR1X14_FEMALE; MPN M20-7821446

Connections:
+5V: P1.17; also elsewhere on the board
+24V: P1.20; also elsewhere on the board
/1 Conectores/+24V_AIN1: P2.6; also elsewhere on the board
/1 Conectores/+24V_AIN2: P2.8; also elsewhere on the board
/1 Conectores/+24V_AIN3: P2.10; also elsewhere on the board
/1 Conectores/+24V_AIN4: P2.12; also elsewhere on the board
/1 Conectores/AIN1: P2.7; also elsewhere on the board
/1 Conectores/AIN2: P2.9; also elsewhere on the board
/1 Conectores/AIN3: P2.11; also elsewhere on the board
/1 Conectores/AIN4: P2.13; also elsewhere on the board
/1 Conectores/CS4: P1.10
/1 Conectores/CS_DAC: P1.7
/1 Conectores/ID1: P1.11
/1 Conectores/ID3: P1.13
/1 Conectores/LDAC_DAC: P1.8
/1 Conectores/Load_Cell+: P2.3; also elsewhere on the board
/1 Conectores/Load_Cell-: P2.4; also elsewhere on the board
/1 Conectores/SCL: P1.15
/1 Conectores/SDA: P1.14
/1 Conectores/USB1: P1.1
/1 Conectores/USB2: P1.2
/CLK: P1.5; also elsewhere on the board
/CS_ADC: P1.9; also elsewhere on the board
/MISO: P1.6; also elsewhere on the board
/MOSI: P1.4; also elsewhere on the board
DGND: P1.3, P1.12, P1.16; also elsewhere on the board
GND_ADC: P1.19, P2.5, P2.14; also elsewhere on the board
IEXC_OUT: P2.2; also elsewhere on the board

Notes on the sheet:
de ERC das folhas 2 e 3.
Barramento da base board. Sinais nao usados nesta placa:
4. P1-18 e P2-1 sem ligacao (tambem na V2.2).
lacos 4-20 mA > folha 6. Os pinos de hoja na raiz ficam
~180 mA em falha: 6% dos 3 A/contacto (Harwin M20), margem 16x.
USB1/2, CS_DAC, LDAC_DAC, CS4, ID1, ID3, SDA, SCL -
6. Fiduciais sem pino electrico: as redes unconnected-(FidX)
5. P2 = M20-7821446 (campo): IEXC e celula > folha 7;
1. P1 = M20-7822046 (Harwin, FILA UNICA de 20 - nao 2x10).
2. P1-20 leva 116 mA em regime (4 lacos a 24 mA, 2 LED, U3) e
da V2.2 desaparecem do diff de netlist.
DECISOES DESTA FOLHA (F2 2.2b)
passiva real e a base board via P1. Fecha os 4 pendentes
3. PWR_FLAG de +24V, GND_ADC (P1.19), +5V e DGND nesta folha: a fonte
terminam aqui por desenho da familia de extensoes.
a espera dessas folhas (aviso de ERC temporario esperado).

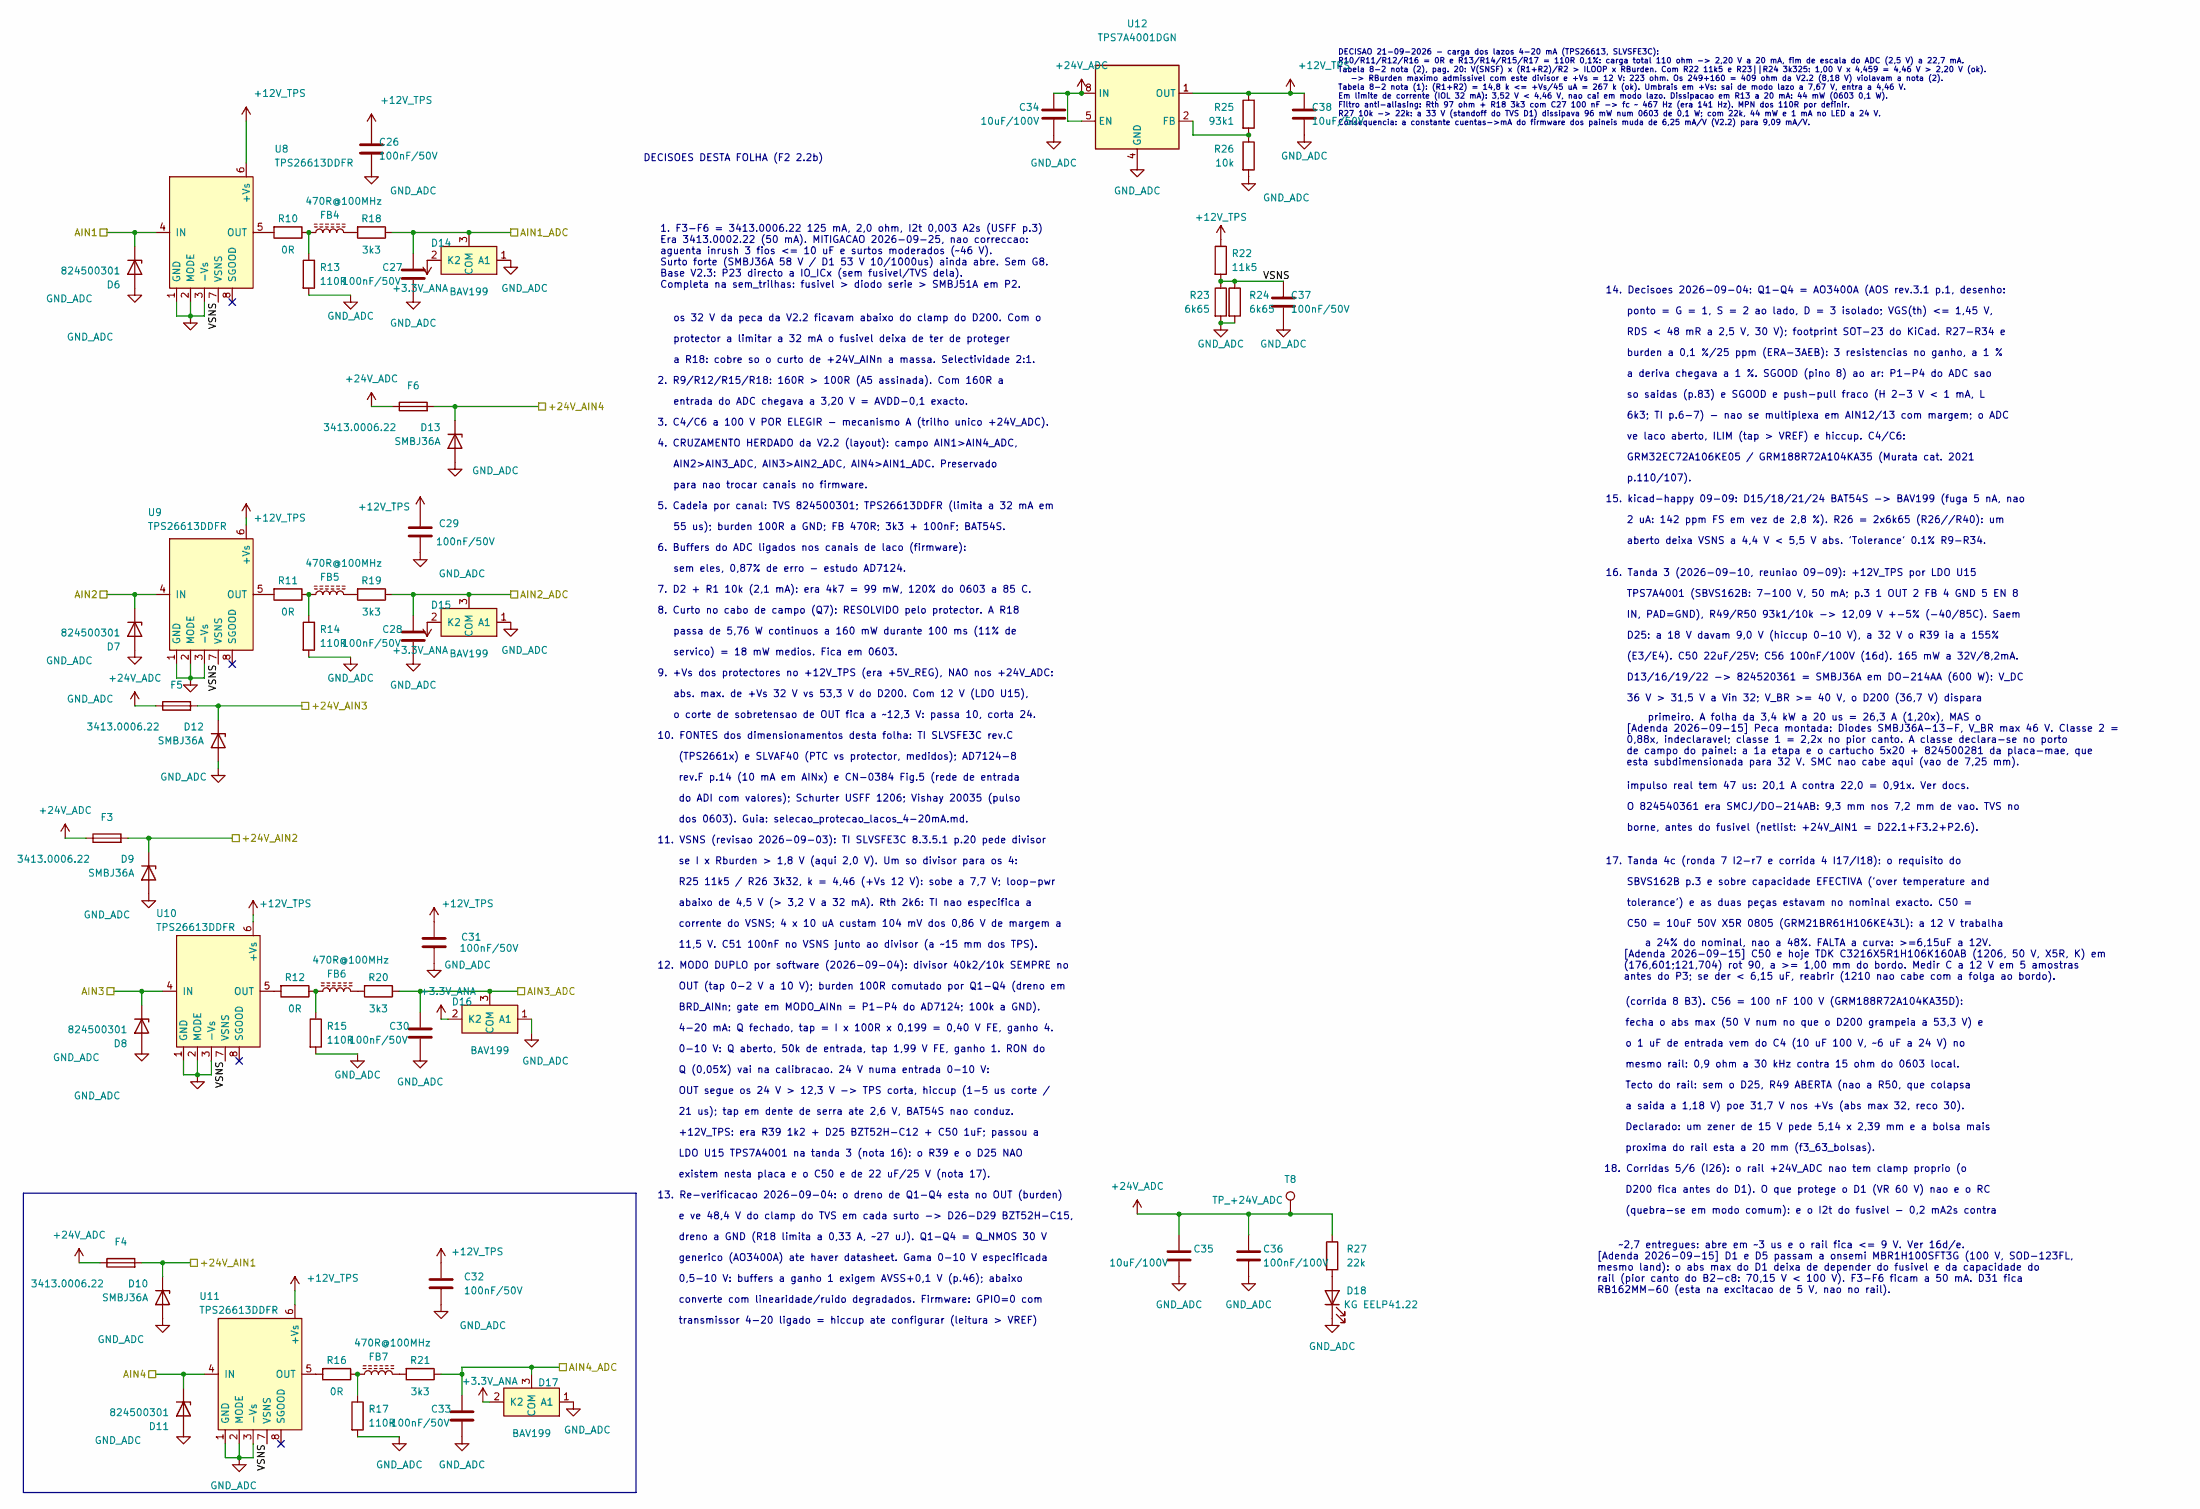
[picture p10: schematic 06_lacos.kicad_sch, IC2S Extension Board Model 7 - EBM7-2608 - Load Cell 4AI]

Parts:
C26, C27, C28, C29, C30, C31, C32, C33, C37: 100nF/50V; 0603C; MPN C1608X7R1H104K080AA
C34, C35: 10uF/100V; C_1210_3225Metric; MPN GRM32EC72A106ME05L
C36: 100nF/100V; 0603C; MPN GRM188R72A104KA35D
C38: 10uF/50V; C_1206_3216Metric; MPN C3216X5R1H106K160AB
D6, D7, D8, D11: 824500301; DO-214; MPN 824500301
D9, D10, D12, D13: SMBJ36A; DO-214AA; MPN SMBJ36A-13-F
D14, D15, D16, D17: BAV199; SOT23-3; MPN BAV199LT1G
D18: KG EELP41.22; 0603LED; MPN KG EELP41.22-PHRH-35-A8J8-20-R18
F3, F4, F5, F6: 3413.0006.22; 1206F; MPN 3413.0006.22
FB4, FB5, FB6, FB7: 470R@100MHz; 0603FB; MPN BLM18PG471SN1D
R10, R11, R12, R16: 0R; 0603R; Tolerance 0.1%; MPN RC0603JR-070RL
R13, R14, R15, R17: 110R; 0603R; Tolerance 0.1%; MPN RG1608P-111-B-T5
R18, R19, R20, R21: 3k3; 0603R; MPN RC0603FR-073K3L
R22: 11k5; 0603R; MPN RC0603FR-0711K5L
R23, R24: 6k65; 0603R; MPN RC0603FR-076K65L
R25: 93k1; 0603R; MPN RMCF0603FT93K1
R26: 10k; 0603R; MPN RC0603FR-0710KL
R27: 22k; 0603R; MPN ERJ-3EKF2202V
T8: TP_+24V_ADC; TestPad_Via
U8, U9, U10, U11: TPS26613DDFR; SOT-23-8; MPN TPS26613DDFR
U12: TPS7A4001DGN; HVSSOP-8-1EP; MPN TPS7A4001DGNR

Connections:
+3.3V_ANA: D14.2 (K2), D15.2 (K2), D16.2 (K2), D17.2 (K2); also elsewhere on the board
+12V_TPS: C26.1, C29.1, C31.1, C32.1, C38.1, R22.1, R25.1, U8.6 (+Vs), U9.6 (+Vs), U10.6 (+Vs), U11.6 (+Vs), U12.1 (OUT)
+24V_ADC: C34.1, C35.1, C36.1, F3.1, F4.1, F5.1, F6.1, R27.1, T8.1 (1_1), U12.5 (EN), U12.8 (IN); also elsewhere on the board
/1 Conectores/+24V_AIN1: D10.1 (K), F4.2; also elsewhere on the board
/1 Conectores/+24V_AIN2: D9.1 (K), F3.2; also elsewhere on the board
/1 Conectores/+24V_AIN3: D12.1 (K), F5.2; also elsewhere on the board
/1 Conectores/+24V_AIN4: D13.1 (K), F6.2; also elsewhere on the board
/1 Conectores/AIN1: D6.1 (K), U8.4 (IN); also elsewhere on the board
/1 Conectores/AIN2: D7.1 (K), U9.4 (IN); also elsewhere on the board
/1 Conectores/AIN3: D8.1 (K), U10.4 (IN); also elsewhere on the board
/1 Conectores/AIN4: D11.1 (K), U11.4 (IN); also elsewhere on the board
/5 ADC/AIN1_ADC: C27.2, D14.3 (COM), R18.1; also elsewhere on the board
/5 ADC/AIN2_ADC: C28.2, D15.3 (COM), R19.1; also elsewhere on the board
/5 ADC/AIN3_ADC: C30.2, D16.3 (COM), R20.1; also elsewhere on the board
/5 ADC/AIN4_ADC: C33.2, D17.3 (COM), R21.1; also elsewhere on the board
/6 Lacos 4-20mA/VSNS: C37.1, R22.2, R23.1, R24.1, U8.7 (VSNS), U9.7 (VSNS), U10.7 (VSNS), U11.7 (VSNS)
GND_ADC: C26.2, C27.1, C28.1, C29.2, C30.1, C31.2, C32.2, C33.1, C34.2, C35.2, C36.2, C37.2, C38.2, D6.2 (A), D7.2 (A), D8.2 (A), D9.2 (A), D10.2 (A), D11.2 (A), D12.2 (A), D13.2 (A), D14.1 (A1), D15.1 (A1), D16.1 (A1), D17.1 (A1), D18.1 (K), R13.2, R14.2, R15.2, R17.2, R23.2, R24.2, R26.2, U8.1 (GND), U8.2 (MODE), U8.3 (-Vs), U9.1 (GND), U9.2 (MODE), U9.3 (-Vs), U10.1 (GND), U10.2 (MODE), U10.3 (-Vs), U11.1 (GND), U11.2 (MODE), U11.3 (-Vs), U12.4 (GND), U12.9 (PAD); also elsewhere on the board
unnamed: D18.2 (A), R27.2
unnamed: FB4.1, R10.1, R13.1
unnamed: FB4.2, R18.2
unnamed: FB5.1, R11.1, R14.1
unnamed: FB5.2, R19.2
unnamed: FB6.1, R12.1, R15.1
unnamed: FB6.2, R20.2
unnamed: FB7.1, R16.1, R17.1
unnamed: FB7.2, R21.2
unnamed: R10.2, U8.5 (OUT)
unnamed: R11.2, U9.5 (OUT)
unnamed: R12.2, U10.5 (OUT)
unnamed: R16.2, U11.5 (OUT)
unnamed: R25.2, R26.1, U12.2 (FB)

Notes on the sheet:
o 1 uF de entrada vem do C4 (10 uF 100 V, ~6 uF a 24 V) no
p.110/107).
BRD_AINn; gate em MODO_AINn = P1-P4 do AD7124; 100k a GND).
9. +Vs dos protectores no +12V_TPS (era +5V_REG), NAO nos +24V_ADC:
18. Corridas 5/6 (I26): o rail +24V_ADC nao tem clamp proprio (o
(quebra-se em modo comum): e o I2t do fusivel - 0,2 mA2s contra
o corte de sobretensao de OUT fica a ~12,3 V: passa 10, corta 24.
55 us); burden 100R a GND; FB 470R; 3k3 + 100nF; BAT54S.
Tecto do rail: sem o D25, R49 ABERTA (nao a R50, que colapsa
~2,7 entregues: abre em ~3 us e o rail fica <= 9 V. Ver 16d/e. [Adenda 2026-09-15] D1 e D5 passam a onsemi MBR1H100SFT3G (100 V, SOD-123FL, mesmo land): o abs max do D1 deixa de depender do fusivel e da capacidade do rail (pior canto do B2-c8: 70,15 V < 100 V). F3-F6 ficam a 50 mA. D31 fica RB162MM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
17. Tanda 4c (ronda 7 I2-r7 e corrida 4 I17/I18): o requisito do
ponto = G = 1, S = 2 ao lado, D = 3 isolado; VGS(th) <= 1,45 V,
D200 fica antes do D1). O que protege o D1 (VR 60 V) nao e o RC
(E3/E4). C50 22uF/25V; C56 100nF/100V (16d). 165 mW a 32V/8,2mA.
4-20 mA: Q fechado, tap = I x 100R x 0,199 = 0,40 V FE, ganho 4.
rev.F p.14 (10 mA em AINx) e CN-0384 Fig.5 (rede de entrada
15. kicad-happy 09-09: D15/18/21/24 BAT54S -> BAV199 (fuga 5 nA, nao
AIN2>AIN3_ADC, AIN3>AIN2_ADC, AIN4>AIN1_ADC. Preservado
dreno a GND (R18 limita a 0,33 A, ~27 uJ). Q1-Q4 = Q_NMOS 30 V
passa de 5,76 W continuos a 160 mW durante 100 ms (11% de
14. Decisoes 2026-09-04: Q1-Q4 = AO3400A (AOS rev.3.1 p.1, desenho:
DECISOES DESTA FOLHA (F2 2.2b)
7. D2 + R1 10k (2,1 mA): era 4k7 = 99 mW, 120% do 0603 a 85 C.
abaixo de 4,5 V (> 3,2 V a 32 mA). Rth 2k6: TI nao especifica a
4. CRUZAMENTO HERDADO da V2.2 (layout): campo AIN1>AIN4_ADC,
(corrida 8 B3). C56 = 100 nF 100 V (GRM188R72A104KA35D):
protector a limitar a 32 mA o fusivel deixa de ter de proteger
burden a 0,1 %/25 ppm (ERA-3AEB): 3 resistencias no ganho, a 1 %
mesmo rail: 0,9 ohm a 30 kHz contra 15 ohm do 0603 local.
borne, antes do fusivel (netlist: +24V_AIN1 = D22.1+F3.2+P2.6).
(TPS2661x) e SLVAF40 (PTC vs protector, medidos); AD7124-8
R25 11k5 / R26 3k32, k = 4,46 (+Vs 12 V): sobe a 7,7 V; loop-pwr
OUT segue os 24 V > 12,3 V -> TPS corta, hiccup (1-5 us corte /
5. Cadeia por canal: TVS 824500301; TPS26613DDFR (limita a 32 mA em
generico (AO3400A) ate haver datasheet. Gama 0-10 V especificada
10. FONTES dos dimensionamentos desta folha: TI SLVSFE3C rev.C
servico) = 18 mW medios. Fica em 0603.
1. F3-F6 = 3413.0006.22 125 mA, 2,0 ohm, I2t 0,003 A2s (USFF p.3) Era 3413.0002.22 (50 mA). MITIGACAO 2026-09-25, nao correccao: aguenta inrush 3 fios <= 10 uF e surtos moderados (~46 V). Surto forte (SMBJ36A 58 V / D1 53 V 10/1000us) ainda abre. Sem G8. Base V2.3: P23 directo a IO_ICx (sem fusivel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
LDO U15 TPS7A4001 na tanda 3 (nota 16): o R39 e o D25 NAO
0-10 V: Q aberto, 50k de entrada, tap 1,99 V FE, ganho 1. RON do

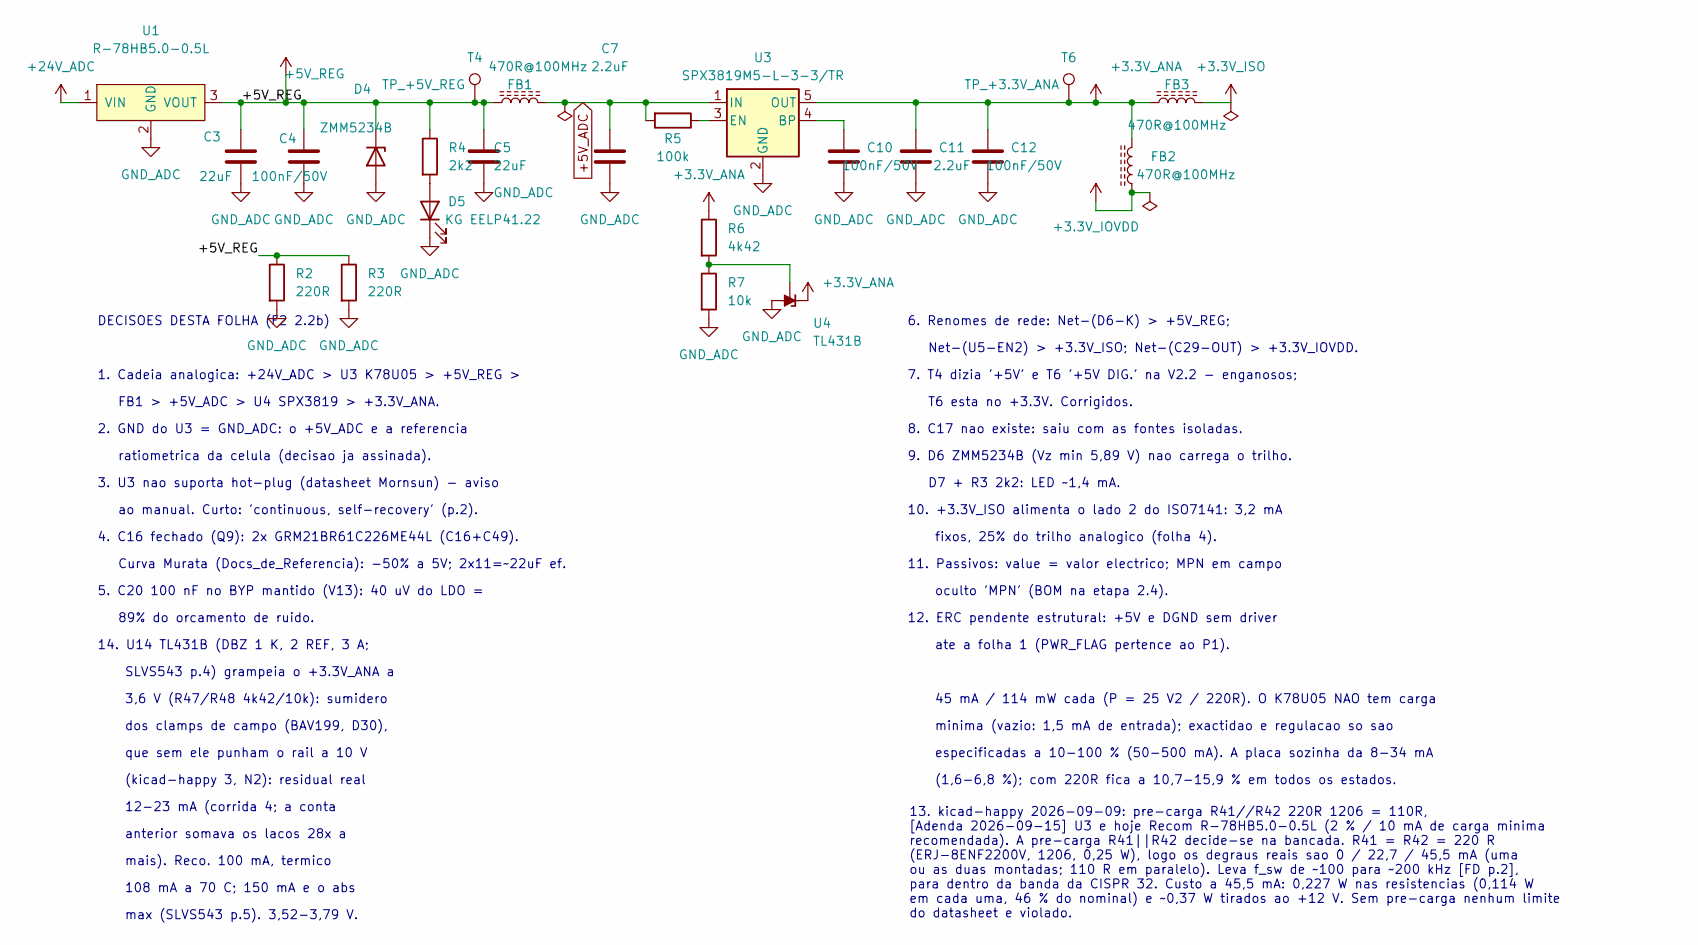
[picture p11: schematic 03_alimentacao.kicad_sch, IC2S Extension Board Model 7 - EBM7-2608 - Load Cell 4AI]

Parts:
C3, C5: 22uF; C_0805_2012Metric; MPN CL21A226KOQNNNG
C4, C10, C12: 100nF/50V; 0603C; MPN C1608X7R1H104K080AA
C7, C11: 2.2uF; 0603C; MPN C1608X5R1E225K080AB
D4: ZMM5234B; SOD-80C; MPN ZMM5234B
D5: KG EELP41.22; 0603LED; MPN KG EELP41.22-PHRH-35-A8J8-20-R18
FB1, FB2, FB3: 470R@100MHz; 0603FB; MPN BLM18PG471SN1D
R2, R3: 220R; 1206R; MPN RC1206FR-07220RL
R4: 2k2; 0603R; MPN RC0603FR-072K2L
R5: 100k; 0603R; MPN CRCW0603100KFKEA
R6: 4k42; 0603R; MPN RMCF0603FT4K42
R7: 10k; 0603R; MPN RC0603FR-0710KL
T4: TP_+5V_REG; TestPad_Via
T6: TP_+3.3V_ANA; TestPad_Via
U1: R-78HB5.0-0.5L; R-78HBxx-0.5L_SIP-3H; MPN R-78HB5.0-0.5L
U3: SPX3819M5-L-3-3/TR; SOT-23-5; MPN SPX3819M5-L-3-3/TR
U4: TL431B; SOT23-3; MPN TL431BQDBZR

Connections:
+3.3V_ANA: C11.2, C12.2, FB2.2, FB3.1, R6.1, T6.1 (1_1), U3.5 (OUT), U4.1 (K); also elsewhere on the board
+3.3V_IOVDD: FB2.1; also elsewhere on the board
+3.3V_ISO: FB3.2; also elsewhere on the board
+5V_ADC: C7.2, FB1.2, R5.2, U3.1 (IN); also elsewhere on the board
+5V_REG: C3.2, C4.2, C5.2, D4.1 (K), FB1.1, R2.1, R3.1, R4.1, T4.1 (1_1), U1.3 (VOUT)
+24V_ADC: U1.1 (VIN); also elsewhere on the board
GND_ADC: C3.1, C4.1, C5.1, C7.1, C10.1, C11.1, C12.1, D4.2 (A), D5.1 (K), R2.2, R3.2, R7.2, U1.2 (GND), U3.2 (GND), U4.3 (A); also elsewhere on the board
unnamed: D5.2 (A), R4.2
unnamed: C10.2, U3.4 (BP)
unnamed: R5.1, U3.3 (EN)
unnamed: R6.2, R7.1, U4.2 (REF)

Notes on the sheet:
dos clamps de campo (BAV199, D30),
mais). Reco. 100 mA, termico
ate a folha 1 (PWR_FLAG pertence ao P1).
8. C17 nao existe: saiu com as fontes isoladas.
minima (vazio: 1,5 mA de entrada); exactidao e regulacao so sao
7. T4 dizia '+5V' e T6 '+5V DIG.' na V2.2 - enganosos;
6. Renomes de rede: Net-(D6-K) > +5V_REG;
3. U3 nao suporta hot-plug (datasheet Mornsun) - aviso
3,6 V (R47/R48 4k42/10k): sumidero
ratiometrica da celula (decisao ja assinada).
D7 + R3 2k2: LED ~1,4 mA.
FB1 > +5V_ADC > U4 SPX3819 > +3.3V_ANA.
que sem ele punham o rail a 10 V
4. C16 fechado (Q9): 2x GRM21BR61C226ME44L (C16+C49).
108 mA a 70 C; 150 mA e o abs
14. U14 TL431B (DBZ 1 K, 2 REF, 3 A;
anterior somava os lacos 28x a
Curva Murata (Docs_de_Referencia): -50% a 5V; 2x11=~22uF ef.
10. +3.3V_ISO alimenta o lado 2 do ISO7141: 3,2 mA
T6 esta no +3.3V. Corrigidos.
oculto 'MPN' (BOM na etapa 2.4).
13. kicad-happy 2026-09-09: pre-carga R41//R42 220R 1206 = 110R, [Adenda 2026-09-15] U3 e hoje Recom R-78HB5.0-0.5L (2 % / 10 mA de carga minima recomendada). A pre-carga R41||R42 decide-se na bancada. R41 = R42 = 220 R (ERJ-8ENF2200V, 1206, 0,25 W), logo os degraus reais sao 0 / 22,7 / 45,5 mA (um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
11. Passivos: value = valor electrico; MPN em campo
12. ERC pendente estrutural: +5V e DGND sem driver
2. GND do U3 = GND_ADC: o +5V_ADC e a referencia
(1,6-6,8 %); com 220R fica a 10,7-15,9 % em todos os estados.
fixos, 25% do trilho analogico (folha 4).
5. C20 100 nF no BYP mantido (V13): 40 uV do LDO =
1. Cadeia analogica: +24V_ADC > U3 K78U05 > +5V_REG >
Net-(U5-EN2) > +3.3V_ISO; Net-(C29-OUT) > +3.3V_IOVDD.
DECISOES DESTA FOLHA (F2 2.2b)
SLVS543 p.4) grampeia o +3.3V_ANA a
(kicad-happy 3, N2): residual real
45 mA / 114 mW cada (P = 25 V2 / 220R). O K78U05 NAO tem carga
ao manual. Curto: 'continuous, self-recovery' (p.2).
9. D6 ZMM5234B (Vz min 5,89 V) nao carrega o trilho.
12-23 mA (corrida 4; a conta
especificadas a 10-100 % (50-500 mA). A placa sozinha da 8-34 mA
89% do orcamento de ruido.
max (SLVS543 p.5). 3,52-3,79 V.

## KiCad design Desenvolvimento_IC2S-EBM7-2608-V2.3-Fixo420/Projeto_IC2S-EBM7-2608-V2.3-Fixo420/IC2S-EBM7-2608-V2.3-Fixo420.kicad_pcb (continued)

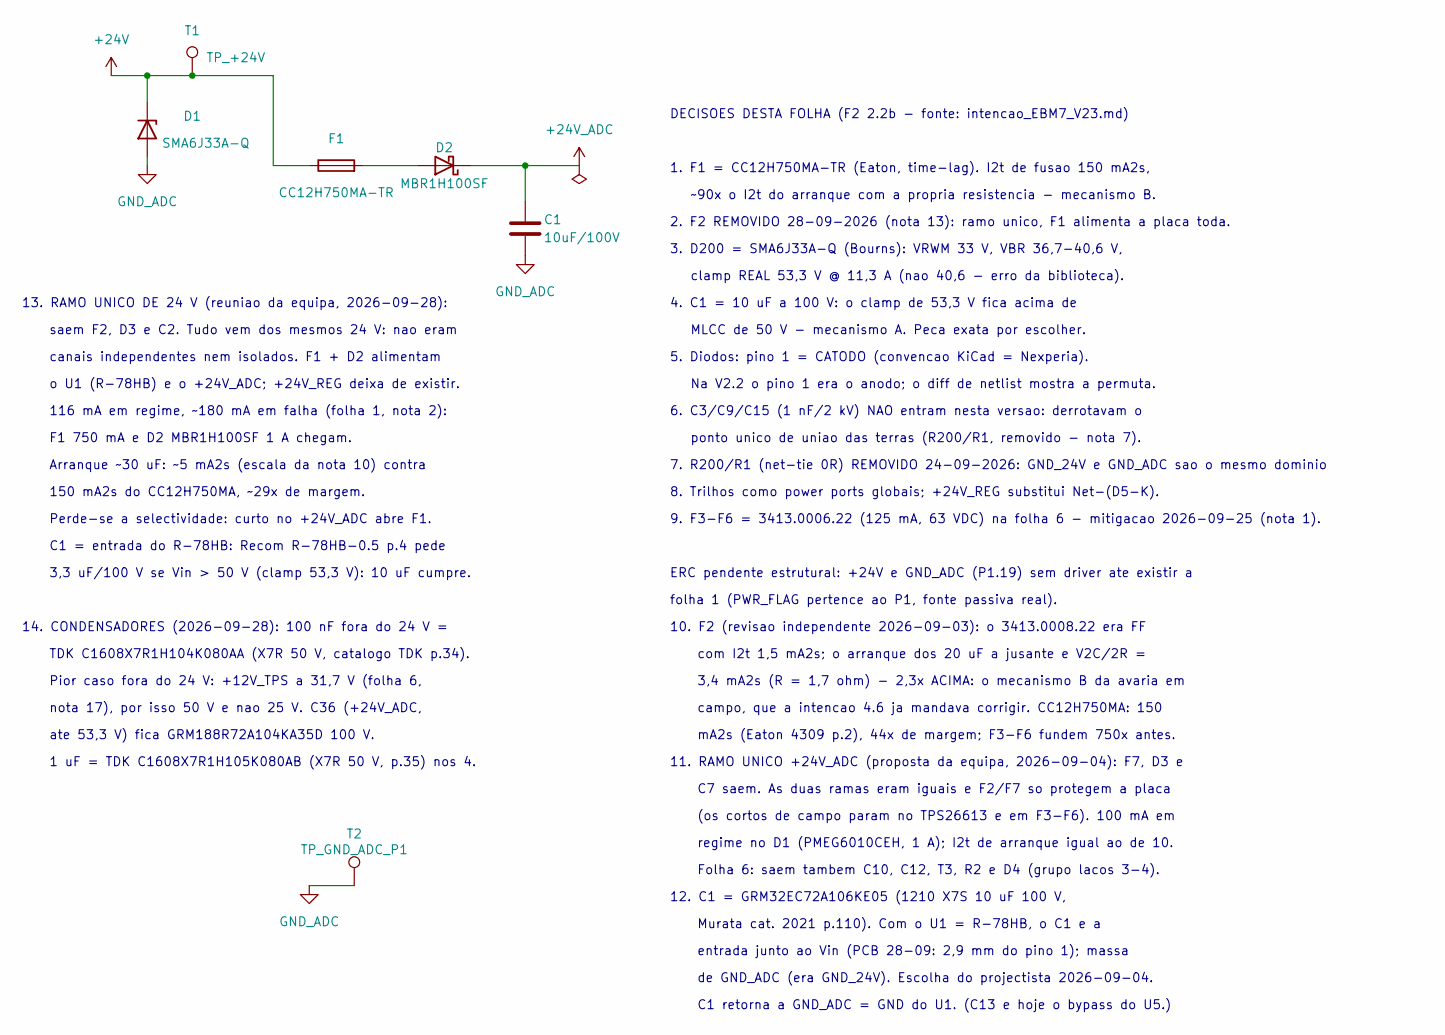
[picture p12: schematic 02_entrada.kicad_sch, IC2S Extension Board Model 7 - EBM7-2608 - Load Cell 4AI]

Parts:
C1: 10uF/100V; C_1210_3225Metric; MPN GRM32EC72A106ME05L
D1: SMA6J33A-Q; DO-214; MPN SMA6J33A-Q
D2: MBR1H100SF; SOD123; MPN MBR1H100SFT3G
F1: CC12H750MA-TR; 1206F; MPN CC12H750MA-TR
T1: TP_+24V; TestPad_Via
T2: TP_GND_ADC_P1; TestPad_Via

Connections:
+24V: D1.1 (K), F1.1, T1.1 (1_1); also elsewhere on the board
+24V_ADC: C1.1, D2.1 (K); also elsewhere on the board
GND_ADC: C1.2, D1.2 (A), T2.1 (1_1); also elsewhere on the board
unnamed: D2.2 (A), F1.2

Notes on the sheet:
8. Trilhos como power ports globais; +24V_REG substitui Net-(D5-K).
13. RAMO UNICO DE 24 V (reuniao da equipa, 2026-09-28):
Pior caso fora do 24 V: +12V_TPS a 31,7 V (folha 6,
Murata cat. 2021 p.110). Com o U1 = R-78HB, o C1 e a
5. Diodos: pino 1 = CATODO (convencao KiCad = Nexperia).
Folha 6: saem tambem C10, C12, T3, R2 e D4 (grupo lacos 3-4).
~90x o I2t do arranque com a propria resistencia - mecanismo B.
Arranque ~30 uF: ~5 mA2s (escala da nota 10) contra
F1 750 mA e D2 MBR1H100SF 1 A chegam.
Perde-se a selectividade: curto no +24V_ADC abre F1.
MLCC de 50 V - mecanismo A. Peca exata por escolher.
12. C1 = GRM32EC72A106KE05 (1210 X7S 10 uF 100 V,
7. R200/R1 (net-tie 0R) REMOVIDO 24-09-2026: GND_24V e GND_ADC sao o mesmo dominio
com I2t 1,5 mA2s; o arranque dos 20 uF a jusante e V2C/2R =
1 uF = TDK C1608X7R1H105K080AB (X7R 50 V, p.35) nos 4.
150 mA2s do CC12H750MA, ~29x de margem.
4. C1 = 10 uF a 100 V: o clamp de 53,3 V fica acima de
6. C3/C9/C15 (1 nF/2 kV) NAO entram nesta versao: derrotavam o
C1 retorna a GND_ADC = GND do U1. (C13 e hoje o bypass do U5.)
TDK C1608X7R1H104K080AA (X7R 50 V, catalogo TDK p.34).
de GND_ADC (era GND_24V). Escolha do projectista 2026-09-04.
10. F2 (revisao independente 2026-09-03): o 3413.0008.22 era FF
saem F2, D3 e C2. Tudo vem dos mesmos 24 V: nao eram
116 mA em regime, ~180 mA em falha (folha 1, nota 2):
ponto unico de uniao das terras (R200/R1, removido - nota 7).
9. F3-F6 = 3413.0006.22 (125 mA, 63 VDC) na folha 6 - mitigacao 2026-09-25 (nota 1).
folha 1 (PWR_FLAG pertence ao P1, fonte passiva real).
campo, que a intencao 4.6 ja mandava corrigir. CC12H750MA: 150
nota 17), por isso 50 V e nao 25 V. C36 (+24V_ADC,
3. D200 = SMA6J33A-Q (Bourns): VRWM 33 V, VBR 36,7-40,6 V,
clamp REAL 53,3 V @ 11,3 A (nao 40,6 - erro da biblioteca).
ate 53,3 V) fica GRM188R72A104KA35D 100 V.
o U1 (R-78HB) e o +24V_ADC; +24V_REG deixa de existir.
entrada junto ao Vin (PCB 28-09: 2,9 mm do pino 1); massa
14. CONDENSADORES (2026-09-28): 100 nF fora do 24 V =
canais independentes nem isolados. F1 + D2 alimentam
1. F1 = CC12H750MA-TR (Eaton, time-lag). I2t de fusao 150 mA2s,
mA2s (Eaton 4309 p.2), 44x de margem; F3-F6 fundem 750x antes.
ERC pendente estrutural: +24V e GND_ADC (P1.19) sem driver ate existir a
2. F2 REMOVIDO 28-09-2026 (nota 13): ramo unico, F1 alimenta a placa toda.

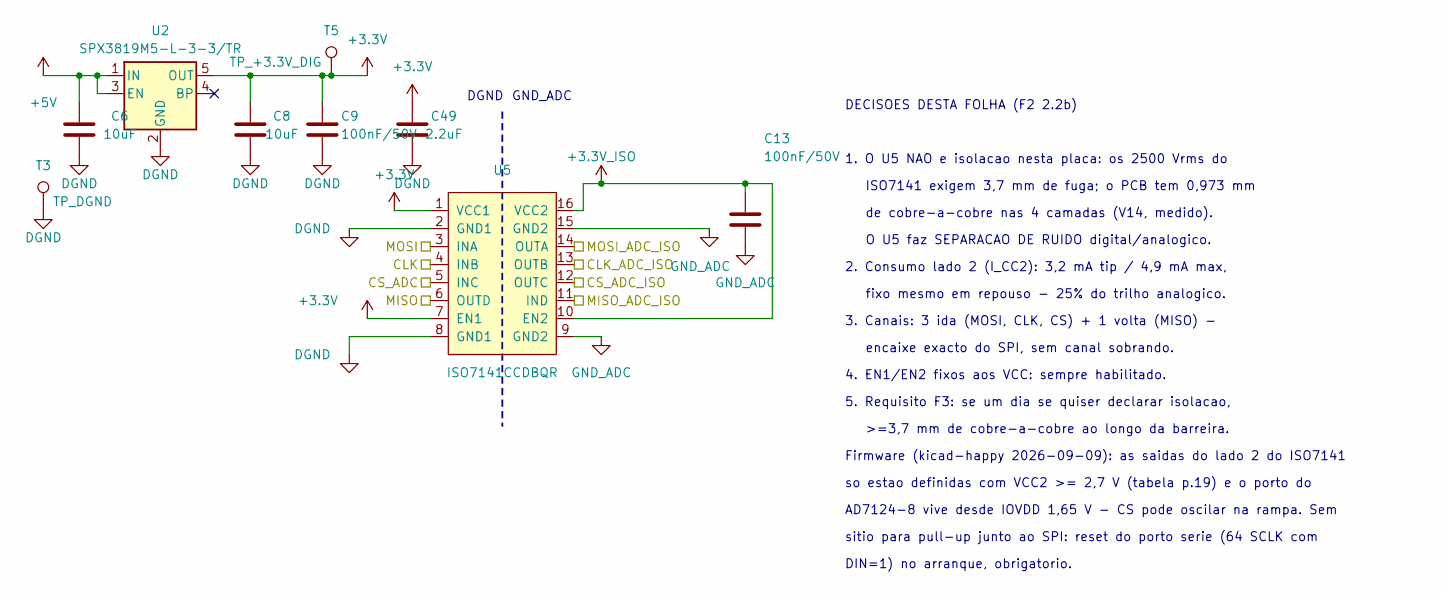
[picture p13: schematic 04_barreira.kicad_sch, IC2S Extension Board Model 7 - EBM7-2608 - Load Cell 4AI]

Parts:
C6, C8: 10uF; 0603C; MPN 0603YD106KAT2A
C9, C13: 100nF/50V; 0603C; MPN C1608X7R1H104K080AA
C49: 2.2uF; 0603C; MPN C1608X5R1E225K080AB
T3: TP_DGND; TestPad_Via
T5: TP_+3.3V_DIG; TestPad_Via
U2: SPX3819M5-L-3-3/TR; SOT-23-5; MPN SPX3819M5-L-3-3/TR
U5: ISO7141CCDBQR; SSOP16-4.9x3.9mm; MPN ISO7141CCDBQR

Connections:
+3.3V: C8.2, C9.1, C49.2, T5.1 (1_1), U2.5 (OUT), U5.1 (VCC1), U5.7 (EN1)
+3.3V_ISO: C13.1, U5.10 (EN2), U5.16 (VCC2); also elsewhere on the board
+5V: C6.2, U2.1 (IN), U2.3 (EN); also elsewhere on the board
/4 Barreira digital/CLK_ADC_ISO: U5.13 (OUTB); also elsewhere on the board
/4 Barreira digital/CS_ADC_ISO: U5.12 (OUTC); also elsewhere on the board
/4 Barreira digital/MISO_ADC_ISO: U5.11 (IND); also elsewhere on the board
/4 Barreira digital/MOSI_ADC_ISO: U5.14 (OUTA); also elsewhere on the board
/CLK: U5.4 (INB); also elsewhere on the board
/CS_ADC: U5.5 (INC); also elsewhere on the board
/MISO: U5.6 (OUTD); also elsewhere on the board
/MOSI: U5.3 (INA); also elsewhere on the board
DGND: C6.1, C8.1, C9.2, C49.1, T3.1 (1_1), U2.2 (GND), U5.2 (GND1), U5.8 (GND1); also elsewhere on the board
GND_ADC: C13.2, U5.9 (GND2), U5.15 (GND2); also elsewhere on the board

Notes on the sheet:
AD7124-8 vive desde IOVDD 1,65 V - CS pode oscilar na rampa. Sem
DECISOES DESTA FOLHA (F2 2.2b)
ISO7141 exigem 3,7 mm de fuga; o PCB tem 0,973 mm
sitio para pull-up junto ao SPI: reset do porto serie (64 SCLK com
encaixe exacto do SPI, sem canal sobrando.
de cobre-a-cobre nas 4 camadas (V14, medido).
5. Requisito F3: se um dia se quiser declarar isolacao,
2. Consumo lado 2 (I_CC2): 3,2 mA tip / 4,9 mA max,
DGND
Firmware (kicad-happy 2026-09-09): as saidas do lado 2 do ISO7141
1. O U5 NAO e isolacao nesta placa: os 2500 Vrms do
O U5 faz SEPARACAO DE RUIDO digital/analogico.
GND_ADC
4. EN1/EN2 fixos aos VCC: sempre habilitado.
3. Canais: 3 ida (MOSI, CLK, CS) + 1 volta (MISO) -
so estao definidas com VCC2 >= 2,7 V (tabela p.19) e o porto do
fixo mesmo em repouso - 25% do trilho analogico.
>=3,7 mm de cobre-a-cobre ao longo da barreira.
DIN=1) no arranque, obrigatorio.

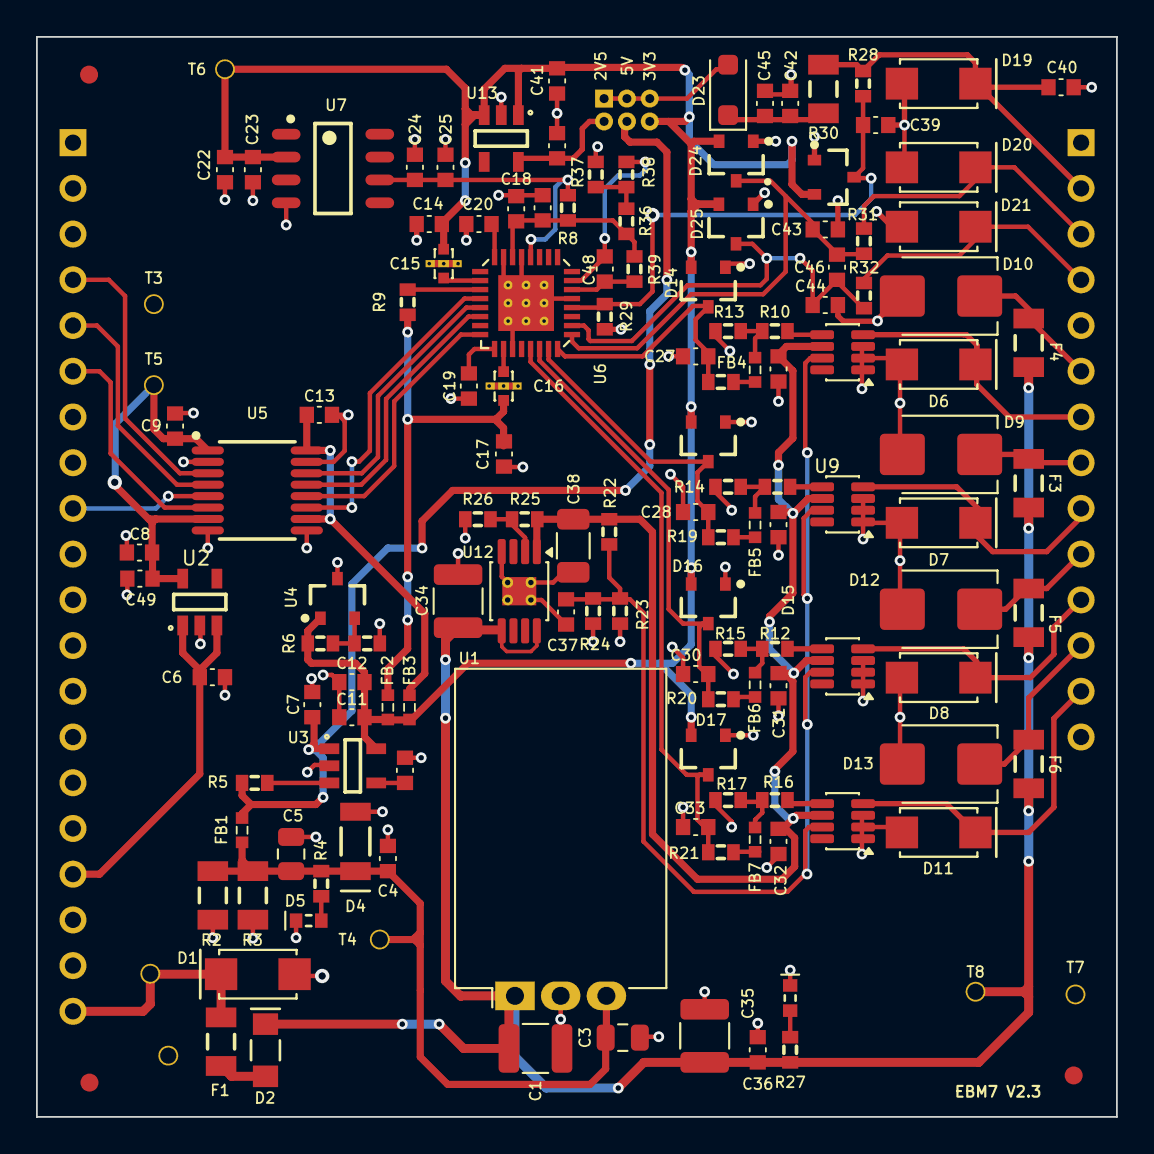
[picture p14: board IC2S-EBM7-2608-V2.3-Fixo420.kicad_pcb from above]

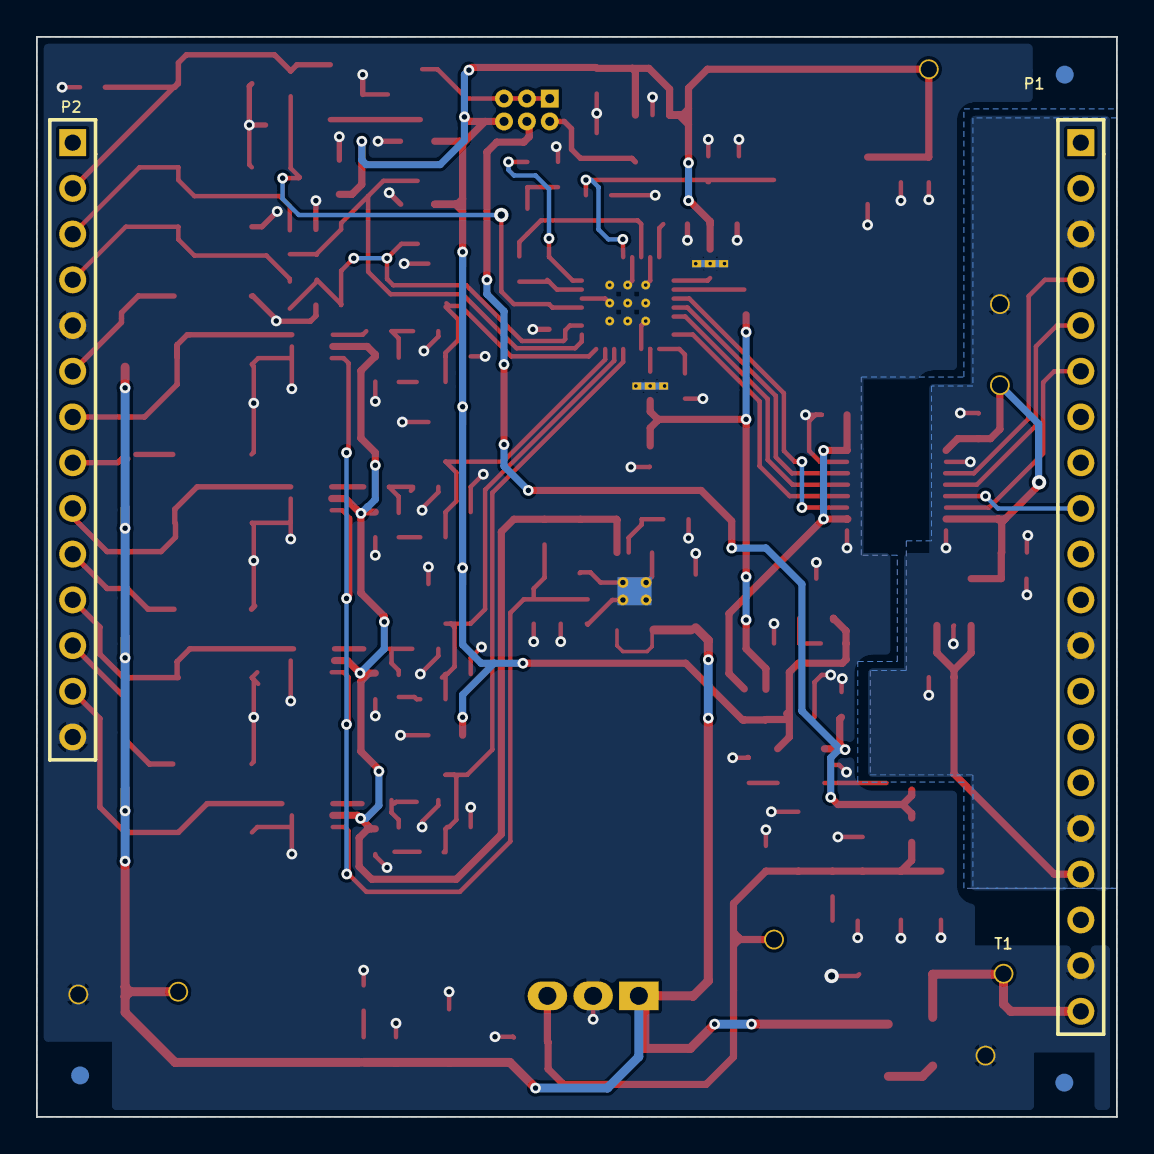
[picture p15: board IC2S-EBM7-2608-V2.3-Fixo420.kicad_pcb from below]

Board: 4 copper layers, 60.0 x 60.0 mm, 146 parts (4 on the bottom side), 71 nets.

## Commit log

2026-09-25 EBM7-2608 V2.3 fixo 4-20 mA: estado actual do projecto KiCad
    Projecto KiCad 10 da variante fixa 4-20 mA (antes KiCad_EBM7_V23_LEGACY_4-20):
    esquematico (8 folhas), PCB roteada de 4 camadas, regras (.kicad_dru),
    bibliotecas locais de footprints e simbolos, e os documentos de
    verificacao que vivem na pasta do projecto.
    Estado da placa no momento do commit: DRC 0 erros, paridade 0,
    0 ligacoes por fazer; avisos de serigrafia pendentes.
    Ficam fora do repositorio o historico local do KiCad (.history), os
    ficheiros de sessao (.kicad_prl, ~*.lck) e as copias .antes_*.
    [01_conectores.kicad_sch, 02_entrada.kicad_sch, 03_alimentacao.kicad_sch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]
2026-09-25 Esquematico: alimentacao do lado PLC passa da folha 3 para a folha 4
    U2 (MCP1824, +3.3V do lado DGND), C6, C8, C9, T3 e T5 desenhados na
    folha 4 (barreira digital), junto ao ISO7141 que alimentam. Limpeza
    grafica nas folhas 2 e 6 (rectangulos e fios soltos).
    Sem mudanca electrica: netlist com os mesmos 148 componentes e nenhum
    pino com rede diferente; ERC 0 erros; DRC 0 erros, paridade 0.
    [02_entrada.kicad_sch, 03_alimentacao.kicad_sch, 04_barreira.kicad_sch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]
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2026-09-25 Arrumacao no padrao de pastas dos produtos (Axcel_Sensor)
    Estrutura Desenvolvimento_<ID>/{Projeto_, Documentos_, Arquivos_Fabricação_}<ID>
    com ID = IC2S-EBM7-2608-V2.3-Fixo420:
    - Projeto: ficheiros KiCad renomeados para <ID>.kicad_*; as 322 referencias
    internas ao nome do projecto (instancias dos simbolos e .kicad_pro)
    actualizadas; bibliotecas, Outputs/drc_report.json e
    Documentos_de_Referência com os 31 datasheets das pecas desta placa.
    - Documentos: 00-Especificações_Técnicas (verificacoes e relatorios),
    01-Esquemáticos (Schematic PDF, STEP, vistas topo/base), 02-Pinout e
    03-Diagrama_Blocos (vazios, como no modelo).
    - Arquivos_Fabricação: Gerbers com extensoes Protel e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
    [01_conectores.kicad_sch, 02_entrada.kicad_sch, 03_alimentacao.kicad_sch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]
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2026-09-28 Revisao da reuniao 28-09: ramo unico de 24 V, 100 nF a 50 V, um so MPN de 1 uF
    - Saem F2, o diodo e o condensador do ramo +24V_ADC; F1 + diodo alimentam o
    R-78HB e o +24V_ADC. +24V_REG deixa de existir (esquematico, PCB, netclasses).
    - Condensador de entrada do R-78HB conferido contra o datasheet Recom (p.4):
    10 uF/100 V cumpre os 3,3 uF/100 V pedidos com Vin > 50 V. Sem alteracao.
    - 100 nF fora do 24 V -> TDK C1608X7R1H104K080AA (50 V); o do +24V_ADC fica
    GRM188R72A104KA35D (100 V). 1 uF -> TDK C1608X7R1H105K080AB nos quatro.
    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
    [02_entrada.kicad_sch, 03_alimentacao.kicad_sch, 04_barreira.kicad_sch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]
2026-09-28 NTC com simbolo de termistor e explicacao do TL431 do +3.3V_ANA
    - Folha 8: o NTC deixa de usar Device:R e passa a Device:Thermistor_NTC
    (mesmos pinos; netlist e PCB inalterados). Observacao da reuniao de 25-09.
    - Documento porque_TL431_*_no_3V3_ANA.md: o LDO nao absorve corrente, os
    BAV199 despejam os surtos no rail e o TL431 segura-o abaixo do maximo
    absoluto do AD7124; numeros tirados dos datasheets locais.
    Claude-Session: https://claude.ai/code/session_01KPnkiJQKrkjgRqqw9M78ie
    [08_ntc.kicad_sch, IC2S-EBM7-2608-V2.3-Fixo420.kicad_pcb]
2026-09-28 LDO 3,3 V do lado PLC: U2 MCP1824ST (SOT-223) -> SPX3819M5-L-3-3/TR (SOT-23-5), mesmo MPN do U3
    - Criterio da equipa: menos MPN, mais pecas do mesmo tipo; o MCP1824ST sai.
    - EN a VIN, BYP aberto; estabilidade com ceramico sem garantia no datasheet (provada em campo na V2.2).
    - Esquematico: ERC 0; netlist so muda os pinos do U2. PCB: pegada SOT-23-5 no
    mesmo sitio; faltam rotear 6 ligacoes do U2; Gerbers/PnP por regenerar depois.
    - Registo: alteracao_LDO_3V3_lado_PLC_2026-09-28.md (comparacao, verificacao e
    riscos em aberto). BOM e PDF do esquematico regenerados.
    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
    [04_barreira.kicad_sch, IC2S-EBM7-2608-V2.3-Fixo420-Preliminar.xlsx, IC2S-EBM7-2608-V2.3-Fixo420.kicad_pcb]
2026-09-28 C49 2,2 uF na saida do U2 (SPX3819), como a saida do SPX da V2.2 em campo
    - Datasheet SPX3819 Fig. 18 (p.8) conferido: EN a VIN e BYP aberto como a figura; saida
    cerâmica 2,2 + 10 uF + 100 nF (V2.2 so tinha ceramicos no SPX). MPN C1608X5R1E225K080AB
    ja na BOM (C7/C11/C46). PCB: clone do C8 a 3 mm do U2, 2 ligacoes por rotear.
    - Inclui as alteracoes de roteamento em curso do projectista no PCB.
    - ERC 0; DRC 0 erros, sem avisos novos, paridade 0. BOM e PDF regenerados.
    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
    [04_barreira.kicad_sch, IC2S-EBM7-2608-V2.3-Fixo420-Preliminar.xlsx, IC2S-EBM7-2608-V2.3-Fixo420.kicad_pcb]
2026-09-28 Esquematicos: fim de linha normalizado para LF (so EOL, sem alteracao de conteudo)
    O KiCad 10 grava os .kicad_sch com LF; no repositorio estavam em CRLF (e o
    02_entrada com CR CR LF). Este commit troca so os fins de linha do conteudo
    de HEAD, para que o commit seguinte mostre apenas as alteracoes reais.
    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
    [01_conectores.kicad_sch, 02_entrada.kicad_sch, 04_barreira.kicad_sch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]
2026-09-28 Roteamento do U2 (SPX3819) e do bypass do ISO7141; pacote de fabricacao regenerado
    PCB:
    - C49 (2,2 uF) e C8 (10 uF) junto do VOUT do U2 (1,68 e 2,23 mm), C6 na
    entrada a 3,0 mm.
    - C9 (100 nF) reposto como bypass do VCC1 do U5 (1,93 mm), massa por via
    DGND a 1,0 mm do pad. Tinha sido movido com o grupo do U2 (6,3 mm).
    - Rede unconnected-(U2-BP-Pad4) na classe DIGSIDE (pad NC do SPX3819 dentro
    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
    [02_entrada.kicad_sch, 04_barreira.kicad_sch, 06_lacos.kicad_sch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]
2026-09-28 Condensadores do U1 junto dos pinos; pacote de fabricacao regenerado
    PCB (28-09 18:19):
    - C1 (10 uF/100 V, entrada do R-78HB) a 2,94 mm do pino 1 (era 10,9 mm).
    - C3 (22 uF, saida) a 2,32 mm do pino 3 (era 12,4 mm). Recom R-78HB-0.5:
    "C1 and C2 are required and should be fitted close to the converter pins".
    - C35/C36/R27 (folha 06) afastados do bordo: C35 de 0,53 para 2,23 mm.
    - DRC com paridade: 0 erros, 0 desligados, paridade 0; 1 aviso cosmetico
    (texto C35 sobre o pad do C36).
    Doc: corrigida a atribuicao errada do C35 ao U1 e o "C1/C2 do U1" (nomes do
    datasheet, nao referencias da placa).
    Fabricacao: Gerbers, furacao, PnP, stencil, BOM, vistas, STEP e PDF do
    esquematico regenerados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
    [IC2S-EBM7-2608-V2.3-Fixo420-Pick-and-Place-Preliminar.csv, IC2S-EBM7-2608-V2.3-Fixo420-Preliminar.xlsx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]
2026-09-28 Limpeza do ERC/DRC: fio solto e rotulo duplicado na folha 5, notas do C1 na folha 2, texto do C35
    - 05_adc: removido o troco de fio de 1,27 mm em (128,27; 78,74)-(128,27; 80,01)
    com a junction que so existia por ele (extremo sem ligacao no ERC), e o
    rotulo local +2.5_VREF sobreposto ao global em (236,22; 83,82).
    - 02_entrada: notas 4 e 12 falavam de "C1/C13" da numeracao antiga; o C13 e
    hoje o bypass do VCC2 do U5. A entrada do U1 (R-78HB) e o C1.
    - PCB: texto de serigrafia ${REFERENCE} do C35 afastado do pad do C36.
    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
    [02_entrada.kicad_sch, 05_adc.kicad_sch, IC2S-EBM7-2608-V2.3-Fixo420-Preliminar.xlsx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]
